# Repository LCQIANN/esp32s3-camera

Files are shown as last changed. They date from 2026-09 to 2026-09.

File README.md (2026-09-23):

# ESP32-S3 Camera — v1.4

以 ESP32-S3-WROOM-1-N16R8 為核心的隨身相機板：OV2640 DVP 相機、microSD 存檔、USB-C 燒錄與充電、鋰電池供電、電源開關與電源燈，1.3 吋 ST7789 預覽螢幕直接插在背面的母座上，快門在上板邊側按。v1.3 起為 3D 列印相機式外殼（鏡頭正面、螢幕背面）而改，v1.4 把快門移到上板邊。KiCad 10 專案，設計成直接送 JLCPCB PCBA。

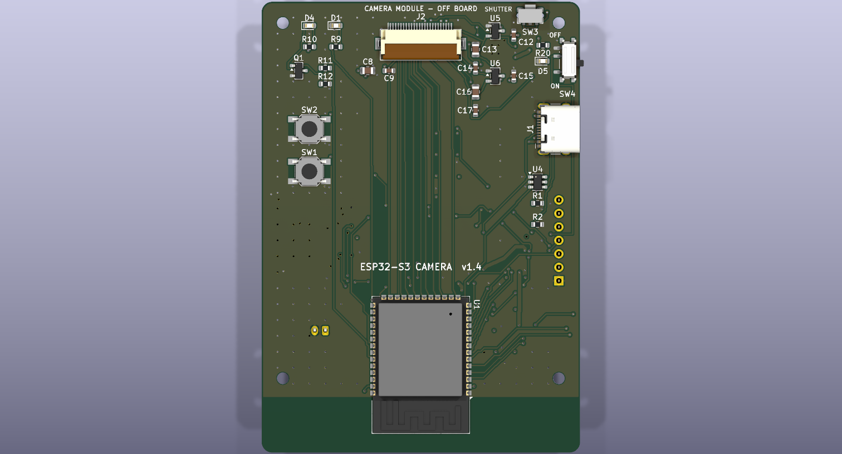
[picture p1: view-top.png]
頂面


| 項目 | 規格 |
|---|---|
| 板子 | 60 × 85 mm、4 層（In1 = GND、In2 = +3V3）、1.6 mm、四角 M2 孔 |
| 主控 | U1 ESP32-S3-WROOM-1-N16R8（16 MB flash、8 MB OPI PSRAM） |
| 相機 | J2 24P 0.5 mm FPC 座，AI-Thinker ESP32-CAM 標準腳位；U5 2.8V、U6 1.2V LDO 供相機 |
| 儲存 | J3 microSD（SDMMC），開口朝左板邊 |
| 電源 | J1 USB-C → U3 TP4056 充電 → J4 JST PH 2.0 鋰電池；U2 AP2112K 3.3V LDO；SW4 滑動開關控制 LDO EN；D5 藍色電源燈 |
| 操作 | SW3 SHUTTER 側按式（ALPS SKRTLAE010）在上板邊右段 (50.6, 2.6)；SW1 BOOT、SW2 RESET 頂面按壓式在左欄；D1 綠、D2 紅（充電）、D4 白 LED |
| 螢幕 | J5 1×7 2.54 mm 母座（底面右板邊），通用型 1.3 吋 IPS 240×240 ST7789 7 pin 模組，用七條公–母杜邦線接（2026-09-23 起；也可直插）；SCL=GPIO44、SDA=GPIO43、RES=GPIO6、DC=GPIO5、BLK=GPIO4。UART0 排針已取消 |
| 零件 | 60 顆：58 SMD 由 JLCPCB 貼片，2 插件（J4 電池座、J5 螢幕母座） |
| 狀態 | v1.4，2026-09-22 定稿。ERC 0、DRC 0/0/0、原理圖一致性 0、GND/3V3 連通性 0 孤立焊盤 |

## 目前狀態

- **v1.4 已定稿，可下單。** 快照在 `versions/v1.4/`，含 Gerber、BOM、CPL、ERC/DRC 報告，視為唯讀。v1.2、v1.3 都沒有下單。
- **預覽螢幕用七條公–母杜邦線接板上母座 J5**（2026-09-23 決定，省事不焊；腳序一對一）。模組鎖在後殼四支矮柱上、蓋在電池上方，亮面離板底約 26.4 mm；外殼後半因為杜邦膠殼加深到 27 mm 內深，整機 40.1 mm。細節與外殼用的尺寸在 `DESIGN.md` 2d 節與 `enclosure/README.md`。
- 版本沿革：v1.0 最初佈局 → v1.1 相機腳位改 ESP32-CAM 標準、加相機 LDO、填 LCSC 料號 → v1.2 加 SW4、R21、R20、D5 與 ON/OFF 絲印 → v1.3 J5/J6 兩條排針換成 1×7 螢幕母座 J5（SMD 與 CPL 不變）→ v1.4 快門 SW3 換成側按式移到上板邊右段，C12 下移 0.8 mm（CPL 只差這兩行）。
- 外殼相關但仍刻意沒改：LED 分兩面、板邊開口分三邊（USB-C 與開關右邊、記憶卡左邊、快門上邊）。
- 送洗前檢查補了兩顆 GND 過孔（J2.23、C3.2 原本焊盤浮接），細節見 `DESIGN.md` 第 3 節。

## 簡報

| 檔案 | 給誰看 | 內容 |
|---|---|---|
| `esp32s3-camera-v1.4-簡易版.pptx` / `.pdf` | 外行人、家人朋友、沒碰過電路板的人 | 11 頁，不用零件編號與專業縮寫：它能做什麼、正反面長什麼樣、工廠做哪些我們做哪些、要買什麼、三步組裝、三件注意事項、外殼長這樣、裝進殼裡長這樣 |
| `esp32s3-camera-v1.4.pptx` / `.pdf` | 自己下單與組裝時對照、有電子背景的人 | 21 頁完整版：依 PCB 座標畫的零件分工圖、Economic / Standard 差異、58 顆 SMD 清單、3D 渲染、組裝尺寸與高度、四頁 3D 列印外殼（含板外零件裝配檢查與杜邦線走線）、含購買連結的採購表；2026-09-23 已更新為杜邦線版 |

另有一個線上頁面「ESP32-S3 相機板零件分工圖」（claude.ai 私人連結，組織內可看），2026-09-23 已更新到 v1.4 杜邦線版：依座標畫的零件分工圖、組裝示意與裸板 3D 渲染、外殼與杜邦線走線渲染、採購清單。

兩份都用 PowerPoint 匯出成 PDF，PDF 內的購買連結可點。兩份簡報 2026-09-23 已更新到 v1.4（螢幕母座、側按快門、外殼）；更新方式是 `tools/update_decks_v14.py` 在 v1.2 檔上改文字、換圖、加頁，再用 `tools/export_decks.py` 叫 PowerPoint 匯出 PDF 與檢查用的 PNG。

## 檔案地圖

```
esp32s3-camera/
├── README.md                     本檔
├── DESIGN.md                     設計規格書：決策、腳位、電路細節、組裝與機構、版本規則
├── esp32s3-camera.kicad_pro/.kicad_sch/.kicad_pcb   KiCad 10 專案（根目錄永遠是最新版）
├── esp32s3-camera.pretty/        自訂 footprint（ESP32-S3-WROOM-1-Cam）
├── esp32s3-camera.step           板子 STEP，給外殼設計用
├── erc.rpt / drc.rpt / netlist.net
├── view-top.png / view-bottom.png   v1.4 頂面、底面 3D 正視
├── esp32s3-camera-v1.4.pptx / .pdf   零件分工、組裝示意、渲染圖、外殼、採購清單簡報（完整版 20 頁）
├── esp32s3-camera-v1.4-簡易版.pptx / .pdf   給外行人看的 11 頁簡易版
├── tools/                        簡報更新與匯出腳本（python-pptx + PowerPoint COM）
│
├── fab/                          送廠檔案
│   ├── esp32s3-camera-gerber.zip   Gerber + 鑽孔打包
│   ├── esp32s3-camera-bom.csv      BOM，含 LCSC Part # 欄
│   ├── esp32s3-camera-cpl.csv      貼片座標
│   ├── gerber/                     未打包的 Gerber、鑽孔檔
│   ├── JLCPCB-上傳-v1.4/            上傳用三個檔案的重新命名版 + 一頁說明
│   ├── JLCPCB-下單清單.md           下單逐步核對表，含收到板子後的第一次上電
│   └── 採購清單.md                  板外零件與插件的購買網址
│
├── render/                       kicad-cli 光線追蹤渲染
│   ├── iso-*/top/bottom/low-angle/closeup-*.png   裸板貼片後
│   ├── assembled-*.png / closeup-camera-module.png   插相機、記憶卡、電池、螢幕的組裝示意
│   └── illustration/             示意渲染專用的板檔複本、簡化 VRML 模型、輔助腳本（見下）
│
├── versions/                     各版完整快照，唯讀
│   ├── v1.0/  v1.1/  v1.2/  v1.3/  v1.4/   每版有 README.txt 說明改了什麼
│
├── enclosure/                    3D 列印外殼：SolidWorks 前殼、後殼、按鈕帽、組合件、STL、渲染圖與產生腳本（見 enclosure/README.md）
├── frames/                       2026-09-11 早期佈局的旋轉截圖，僅供回顧
└── .history/                     KiCad 自動快照，由 KiCad 管理
```

`render/illustration/esp32s3-camera-illustration.kicad_pcb` 多了三個沒有焊盤的假零件掛簡化模型，**只用來渲染，不要拿它出 Gerber**。

## 怎麼下單

1. 依 `fab/JLCPCB-下單清單.md` 逐項核對。上傳 `fab/esp32s3-camera-gerber.zip`、`esp32s3-camera-bom.csv`、`esp32s3-camera-cpl.csv`。
2. PCB：4 層、60 × 85 mm、1.6 mm、1 oz、ENIG 建議、Tented via，最少 5 片。
3. PCBA：雙面貼片，最少 2 片。
   - **Economic** 只焊 SMD：J4 電池座、J5 1×7 母座（C225482）自己買回來手焊。
   - **Standard** 含插件：兩顆一起焊好。
4. 料號配對頁逐行看：U1 `C2913202`（N16R8，可能預購，不要被換成 N8 或無 R 版）、D3 `C8598`（SOD-123，不是 SS14）、SW4 `C431540`、SW3 `C110293`（ALPS SKRTLAE010 側按，不要被換成頂按式）。
5. 零件擺放預覽確認方向：U1 天線端朝板子底邊、J1 開口朝板邊、J2 掀蓋朝板邊、SW4 撥桿朝右板邊、**SW3 觸桿朝上板邊**、J5 母座在底面、方形 pin 1 焊盤朝天線那一端。

## 板外要自己買的

相機模組、鋰電池、microSD 卡、USB-C 線是最小採購；Economic 方案再加 J4 電池座。完整清單與購買網址在 `fab/採購清單.md`。

| 品項 | 規格 | 接到 |
|---|---|---|
| OV2640 相機模組 | 24 pin 0.5 mm 排線，ESP32-CAM 相容，排線約 21 mm，多買一條備用 | J2 |
| 3.7V 鋰電池 | 603040 或 503040 約 600 mAh，帶保護板，JST PH 2.0 插頭 | J4 |
| microSD 卡 | 8–32 GB | J3 |
| USB-C 線 | 要能傳資料 | J1 |
| 預覽螢幕 | 通用型 1.3 吋 IPS 240×240 ST7789，7 pin 2.54 mm 直排針已焊，27.78 × 39.22 mm | 七條公–母杜邦線接 J5 |
| 杜邦線 | 公–母、10 cm、7 條 | 公頭插 J5、母頭套螢幕排針 |
| M2 螺絲與銅柱 | 板子 4 組 | H1–H4 |
| 雙面泡棉膠 | 約 2 mm 厚 | 相機模組與電池底下 |

## 組裝重點

- **相機**：排線接觸面朝下插入 J2，出來約 2.5 mm 就反折 180° 蓋回 J2，模組貼在按鍵欄與 U4 之間的空區（x 25.5–34.5、y 20.5–29.5 mm），鏡頭中心 (30, 25)，底下墊 8 × 8 mm 泡棉膠。
- **電池**：貼在底面中央 (34, 44)，墊 2 mm 泡棉，保護板端朝下緣。**J4 pin 1 = 正極**，在 L 形絲印那一側、靠板子中央。電池插頭極性沒有統一規範，插之前先量。
- **螢幕**：模組排針對準底面右板邊的 J5 母座直接插到底，亮面朝外、身體蓋在電池上方。腳序一對一：GND、3V3、SCL (GPIO44)、SDA (GPIO43)、RES (GPIO6)、DC (GPIO5)、BLK (GPIO4)，板上每格都有絲印，**第一次插之前先對一下模組上的 GND 字有沒有對到板上 GND 那格**。借用 UART0 腳位當 SPI，USB 序列埠仍可用。
- **快門**：SW3 在上板邊右段，觸桿朝板邊伸出 0.56 mm 內，由外殼上牆的快門帽按壓；不裝外殼時用指甲從板邊按。BOOT、RESET 仍在鏡頭面左欄。
- **電源開關**：撥向板子上緣（角落孔那側）= OFF，撥向模組 = ON，絲印已標。關機時 USB 仍可充電，D2 紅燈照常。D5 藍燈接 3.3V，開機必亮。
- **microSD**：從左板邊插入 J3，金手指朝電路板，推到「喀」一聲。
- **底面高度**：電池 + 泡棉 8 mm；J5 上的杜邦公頭膠殼到板底下 22.5 mm；螢幕模組背面離板底 23.6 mm、亮面 26.4 mm，外殼底側內深 27.0 mm。
- **外殼開孔**：鏡頭 (30, 25) 頂面；快門上板邊 x 47.6–53.6、板頂以上 0.2–4.4 mm；BOOT/RESET 針孔 (9, 24)、(9, 32)；開關右板邊 y 8–14；USB-C 右板邊 y 19.5–28.5；記憶卡左板邊 y 36–52；螢幕窗 23.4 × 23.4 mm，中心約 (28.4, 45) 底面。板子 STEP 在 `esp32s3-camera.step`，含母座；螢幕模組的簡化模型在 `render/illustration/models/display_module.wrl`。

## 外殼

`enclosure/` 是給 v1.4 板子的相機式兩片殼（前殼鏡頭面、後殼螢幕面，快門帽在上牆），用 `enclosure/build_enclosure_sw.py` 透過 SolidWorks 2024 的 API 依板檔座標自動建模，組合件含板子 STEP 與板外零件簡化模型，干涉檢查 0 件。螢幕模組用四支 M2×4 鎖在後殼的矮柱上、以七條杜邦線接 J5，快門帽在上牆。外形 65 × 90 × 40.1 mm，四支 M2×35 從背面鎖。組合件連相機模組、排線反折、電池與電池線、記憶卡、螢幕模組、杜邦線的簡化模型都放進去做過干涉檢查，0 件。尺寸依據、列印方向、組裝步驗與第一次實體要驗證的項目都在 `enclosure/README.md`。

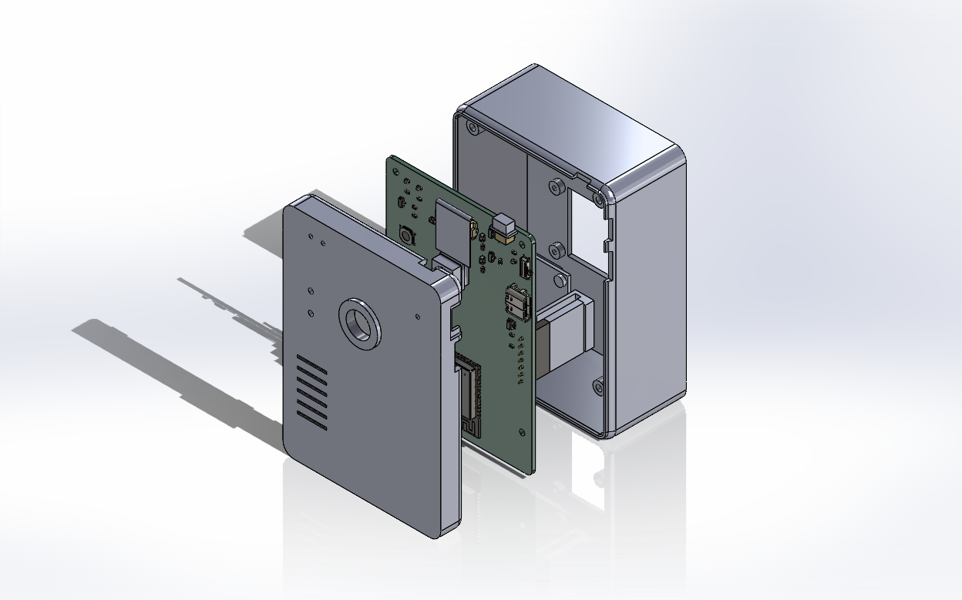
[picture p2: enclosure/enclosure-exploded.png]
外殼爆炸圖


## 收到板子後的第一次上電

先不插相機與電池。接 USB-C 撥 SW4 看 D5 亮滅，量 +3V3 / +2V8 / +1V2 對地無短路且電壓正確，電腦看到 ESP32-S3 USB 裝置，燒 blink 測 D1。都過了再依序插 microSD、相機排線、最後接電池。完整清單在 `fab/JLCPCB-下單清單.md` 第 8 節。

## 韌體

Arduino IDE `esp32` 套件的 CameraWebServer 範例，或 ESP-IDF 的 `esp32-camera` component。Board 選 **ESP32S3 Dev Module**，PSRAM 選 **OPI PSRAM**（R8 是 octal，選 QSPI 會抓不到）。相機 GPIO 對應表在 `DESIGN.md` 第 4 節，直接填進 `camera_config_t`。

## 版本規則

- 根目錄永遠是正在改的最新版。每次出 Gerber 準備下單，把 `.kicad_pcb / .kicad_sch / .kicad_pro`、`esp32s3-camera.pretty/`、`fp-lib-table` 與 `fab/` 內的 zip、BOM、CPL 複製到 `versions/vX.Y/`，並寫 README.txt。
- 版本號用數字（v1.0、v1.1、v1.2），不用 rev A / rev B。板上絲印、KiCad 標題欄、Gerber ProjectId 三處同步。
- 不在根目錄留 `*.bak_before_xxx`，中途快照交給 KiCad 的 `.history/`。
- 2026-09-21 起以 Git 管理，遠端為公開的 GitHub LCQIANN/esp32s3-camera；`versions/` 的快照仍照上面規則保留。

## 重新輸出送廠檔

```
kicad-cli sch export bom --fields "Reference,Value,Footprint,QUANTITY,LCSC" --labels "Designator,Comment,Footprint,Qty,LCSC Part #" --group-by "Value,Footprint,LCSC" --exclude-dnp -o fab/esp32s3-camera-bom.csv esp32s3-camera.kicad_sch
kicad-cli pcb drc --schematic-parity esp32s3-camera.kicad_pcb
```

## 輔助腳本（`render/illustration/`，用 KiCad 附的 python 執行）

| 腳本 | 用途 |
|---|---|
| `gnd_connectivity.py` | 幾何連通性檢查：焊盤、過孔、走線、敷銅做 union-find，確認每個 GND / +3V3 焊盤都在主群集。**DRC 只要有 unconnected_items 就跑一次，0 才算過。** |
| `battery_check.py` | 電池投影範圍對底面零件外框與高度的間距核對 |
| `fix_v12_gnd.py` | 2026-09-21 補 J2.23、C3.2 GND 過孔與 R21 腳位修正 |
| `v12_sch.py` / `v12_pcb.py` / `v12_silk_onoff.py` | v1.2 加 SW4、R20、R21、D5 與 ON/OFF 絲印的自動改板腳本 |
| `make_illustration_board.py` | 產生示意渲染用的板檔複本 |
| `gen_camera_wrl.py` / `gen_display_wrl.py` | 產生相機模組與螢幕的簡化 VRML 模型（KiCad 不畫 Cylinder 基本體，圓柱要用網格） |
| `sch_inspect.py` | 原理圖檢查工具 |

## 教訓

- DRC 報的「zone unconnected」不要當敷銅碎片忽略。KiCad 只回報兩群集間最近的一對物件，浮接的焊盤會藏在後面。
- D3 要用 B5819W SOD-123（`C8598`），LCSC 上的 SS14 是 SMA 封裝，焊盤不合。
- JLCPCB 的零件旋轉定義與 KiCad 不一定一致，零件擺放預覽頁逐一看有極性的零件。

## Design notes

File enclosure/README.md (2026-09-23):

# ESP32-S3 Camera v1.4 — 3D 列印外殼（SolidWorks 2024）

相機式兩片殼：**前殼**（鏡頭與凸起鏡座環、上牆的快門帽、BOOT/RESET 針孔、三個 LED 導光孔、左側握持溝紋、USB-C 與電源開關的開口）＋**後殼**（內縮邊框的螢幕窗、記憶卡插槽、四支板子立柱、四支螢幕螺絲柱），外緣整圈 R2.5 倒圓、直角 R4.5，用四支 M2×35 螺絲從背面鎖穿。整組 **65 × 90 × 40.1 mm**（鏡座環再凸 1.5），壁厚 2 mm。
螢幕模組**用七條公–母杜邦線接 J5**（2026-09-23 決定，省事不焊）：公頭插板上母座、母頭套模組排針；後殼因此加深到 27 mm 內深，模組改用四支 M2×4 鎖在後殼柱子上。
所有零件都是 `build_enclosure_sw.py` 透過 SolidWorks COM API 依 v1.4 板檔的座標畫出來的，改尺寸就改腳本開頭的參數重跑。v1.3 版外殼（三顆正面按鈕帽）已被取代。

爆炸圖

## 檔案

| 檔案 | 內容 |
|---|---|
| `esp32s3-camera-enclosure.SLDASM` | 組合件：板子 + 前殼 + 後殼 + 快門帽，全部固定在板子座標系，已跑干涉檢查 0 件 |
| `esp32s3-camera-shell-front.SLDPRT` / `.STL` | 前殼（鏡頭面） |
| `esp32s3-camera-shell-back.SLDPRT` / `.STL` | 後殼（螢幕面） |
| `esp32s3-camera-shutter-cap.SLDPRT` / `.STL` | 快門帽，印 1 個（T 形，凸緣在牆內） |
| `esp32s3-camera-board.SLDPRT` | 由 `../esp32s3-camera.step` 匯入的板子（148 個實體合成一個多實體零件），只給組合件用 |
| `enclosure-*.png` | 各方向渲染與爆炸圖 |
| `build_enclosure_sw.py` | 產生器。SolidWorks 開著時執行 `python enclosure/build_enclosure_sw.py`；只重建組合件加 `--asm-only` |

## 座標系

組合件用板子座標：X = KiCad x，Y = −KiCad y，Z = 0 在板子**頂面**（鏡頭那一面），板底 Z = −1.6。
前殼佔 Z 0 ～ +9，後殼佔 Z −31.1 ～ 0，分模線就在板子頂面。KiCad 的 STEP 是 Y 上下顛倒的右手座標，所以直接對得上，只平移 Z。

## 尺寸怎麼來的

| 項目 | 數字 | 依據 |
|---|---|---|
| 內腔 | 61 × 86 mm | 板子 60 × 85 + 每邊 0.5 mm 間隙 |
| 前殼內高 | 8 mm（板頂以上） | 相機模組：泡棉 2.3 + PCB 1 + 鏡座 3.5 = 鏡座頂 6.9，留 1.1 mm；鏡筒與壓環到 9.0 穿出 Ø10 孔，鏡片在鏡座環裡內縮 2.5 mm；USB-C 座 3.3、ESP32 模組 3.1 |
| 後殼內深 | 27.0 mm（板底以下） | 插在 J5 上的杜邦公頭：母座 8.5 + 膠殼 14.0 = 22.5，線從膠殼尾端彎出來再要 3.5，留 1.0；螢幕模組就吊在這個深度：背面離板底 23.6、玻璃面 26.4，離底板內面 0.6 給窗框泡棉；電池 6 + 泡棉 2 = 8 |
| 板厚 / 壁厚 / 底板 | 1.6 / 2.0 / 前 2.0、後 2.5 | 後底板 2.5 是為了放 1.5 mm 深的螺絲頭沉孔 |
| 直角圓角 | R4.5 外、R3.5 中、R2.5 內 | 三層同心；板子四角有 2 mm 斜切，Ø5 立柱仍在內腔圓弧內 |
| 面的倒圓 | 鏡頭面與螢幕面的外緣整圈 R2.5 | 板 2 mm 加牆 2 mm，45° 處最薄 1.8 mm |
| 鏡座環 | Ø16 / Ø10、凸出 1.5 mm | 鏡頭孔外一圈凸環，相機味，也擋住鏡頭孔邊緣的層紋 |
| 握持溝紋 | 鏡頭面左側 x 3.5–15.5，六道 1 mm 寬 0.6 mm 深，y 50–70 每 4 mm 一道 | 針孔下方的空區；內側是前殼柱子，不影響 |
| 螢幕邊框 | 螢幕窗外 28.5 × 28.5 內縮 0.8 mm | 讓窗看起來是一片面板，不是牆上開個洞 |
| 立柱（後殼） | Ø5 × 14.5，Ø2.4 穿孔，底面 Ø4.2 × 1.5 沉孔 | 在板子四角 M2 孔 (4,4)(56,4)(4,71)(56,71) |
| 柱（前殼） | Ø4.6 × 8，Ø1.6 × 7 導孔 | M2 自攻，M2×35 進去 5.4 mm；Ø4.6 是因為 (56,4) 那支離 SW4 只有 0.2 mm |
| 唇口 | 後殼內側 0.8 mm 厚、高 1 mm，前殼對應凹槽 1.0 mm，每側 0.1 mm 間隙 | 對位用，也擋光 |
| 鏡頭孔 | Ø10 @ (30, 25) | 相機模組鏡頭中心 |
| 快門窗 | 上牆（y = 0 那一側）x 47.6–53.6、板頂以上 Z 0.2–4.4；後殼唇口同位置開缺口 | SW3 ALPS SKRTLAE010 側按，觸桿頭在 y = 0.56、Z 1.75，開關高 3.5 |
| 快門帽 | 凸緣 7.6 × 4.0 × 0.8 在牆內，頭 5.6 × 3.6 穿牆、露出 1.0 mm，總長 4.06 | 觸桿頭到牆內面 1.06 mm：凸緣 0.8 + 預行程 0.26；開關行程 0.25 |
| BOOT / RESET 針孔 | Ø2.0 @ (9, 24) RESET、(9, 32) BOOT，穿過 2 mm 頂板 | 用 SIM 卡針或牙籤從 7 mm 外按 1.5 mm 高的開關 |
| LED 導光孔 | Ø1.5 @ (14,4.5) D1 綠、(9,4.5) D4 白、(53,11.2) D5 藍；後殼 Ø2 @ (53,14) D2 紅 | 頂面直接透光；D2 隔 14.5 mm，只看得到微光 |
| USB-C 窗 | 右側牆，y 18.75–29.25、Z 0–4.2 | 座子 8.94 寬 × 3.26 高，加間隙；後殼唇口對應開缺口到 Z −1 |
| 電源開關槽 | 右側牆，y 7–15、Z 0–4.5；外側再挖 1 mm 深、12 × 6 的指窪 | 撥桿只伸出板邊 0.7 mm，牆薄到 1 mm 才撥得到 |
| 記憶卡槽 | 左側牆，y 37.5–50.5、Z −4.8 ～ −2.0 | 卡插到底仍露出板邊 4.6 mm，會露出殼外 2.1 mm 好拔 |
| 螢幕窗 | 24.5 × 24.5 @ (28.4, 45) | 有效顯示區 23.4 × 23.4（模組中心 x 30，顯示區偏向排針那一側 1.6）；模組玻璃 25.8 × 29.22，窗框壓在玻璃邊緣上，內側貼一圈 0.5 mm 泡棉膠填掉 0.6 mm 空隙 |
| 螢幕螺絲柱 | 後殼底板長四支 Ø4.5、2.2 mm 高的柱到模組 PCB 朝底板那一面（離板頂 26.4 mm），Ø1.6 × 4 導孔，M2×4 穿過模組四角 Ø2 孔鎖進去 @ (12.9, 33.6)、(47.1, 33.6)、(12.9, 56.4)、(47.1, 56.4) | 模組不插母座，只靠這四支螺絲；模組中心 x = 30、排針那排朝左（x 12.9），離 J5 遠一點才有地方繞線。孔位照 lcdwiki 的 GMT130 圖面，買到孔位不同的相容品要改 `DISPLAY_MODULE` |
| 杜邦線 | 7 條公–母，J5 上的公頭膠殼 2.54 × 14 站在母座上（板底下 8.5–22.5），模組排針上的母頭膠殼從模組背面朝板子伸 16.5（含排針塑膠 2.54），頂端離板底 7.1；線先在母頭上方 S 彎、走電池底下 0.7 mm 的空隙到模組右邊 x 51，沿模組邊下到離底板內面 1 mm，再從下面繞進公頭 | 買 10 cm 的一排 40P 剪 7 條；多出來的長度盤在模組右邊 x 50–54 到底板之間。膠殼尺寸不同就改 `DUPONT`，線走法在 `build_display_cable()` |

## 列印與組裝

- **列印方向：兩片殼都開口朝下、外面朝上。** 外緣有 R2.5 倒圓之後，外面朝下印會讓第一層只剩內縮 2.5 mm 的平面，圓角從幾乎水平開始一層層外擴，表面會很糙；翻過來讓圓角像圓頂一樣往上收就沒有懸空。鏡座環、握持溝紋、螢幕邊框都在最上面那一面，也正好印得最乾淨。
- 翻過來印的代價是殼內的柱子變成從天花板往下長、離床有空隙，要開支撐：前殼四支柱離床 2 mm（內高 8 對板頂，柱長 8），後殼四支立柱離床 1.6 mm、四支螢幕螺絲柱只有 2.2 mm 高、離床 26.4 mm。切片時選「只在列印床上生成支撐」加樹狀支撐，支撐只會長在這幾支柱子下面，拆掉即可；柱子底面（貼板子那一面）拆完稍微修平。後殼的唇口比外牆高 1 mm，開口朝下時唇口先著床、外牆邊 1 mm 懸空，同一組支撐設定會自動補一圈薄底，或改用 raft。
- 上牆快門窗、右側牆 USB-C 窗與開關槽、左側牆記憶卡槽都在垂直牆上，2–6 mm 跨距自然橋接，不用支撐。**快門帽**：凸緣朝下、頭朝上，不用支撐。
- 材料 PLA/PETG 皆可；預估 PLA 用量前殼約 20 g、後殼約 40 g（牆高 31 mm），支撐另加幾克。層高 0.2 mm、壁 3 圈；想要圓角更順可用 0.12 mm 層高只印外殼那兩件。
- 螺絲：**M2 × 35 mm 盤頭** ×4，從後殼底部沉孔穿過立柱與板子，自攻進前殼的 Ø1.6 × 7 導孔（進去 5.4 mm）。先用 M2 螺絲在前殼導孔上預攻一次再組。另外 **M2 × 4 mm 盤頭** ×4 把螢幕模組鎖在後殼的四支矮柱上。
- 組裝順序：① 螢幕窗框內側貼 0.5 mm 泡棉膠 ② 螢幕模組亮面朝窗、排針那排朝左（記憶卡那一側），四角用 M2×4 鎖在後殼的矮柱上 ③ 七條杜邦線母頭套上模組排針，公頭照板上絲印插進 J5（GND 對 GND，先核對模組絲印），多出來的線盤在模組右邊 ④ 板子放進後殼，四角落在立柱上，線不要壓在電池與模組之間以外的地方 ⑤ 快門帽從前殼內側塞進上牆的窗，凸緣留在牆內 ⑥ 前殼蓋上，唇口對進凹槽 ⑦ 翻面鎖四支 M2×35。相機模組與電池用泡棉膠照 `../README.md` 貼好再蓋。
- 板子與殼壁間隙 0.5 mm，FDM 列印若內縫收縮，用刀修一下唇口即可。

## 板外零件的裝配檢查

組合件除了板子 STEP，還放了五個依文件尺寸畫的簡化零件：`offboard-camera-module`（相機模組含泡棉、鏡座、鏡筒）、`offboard-ribbon`（24P 排線：0.3 mm 厚、14 mm 寬，在 y 4.0 以 0.7 mm 半徑反折，最外緣 y 3.15，回程貼板高 2.4 mm 到模組邊 y 20.5）、`offboard-battery-card`（603040 電池、電池線、J4 下方的插頭出線、露出板邊的記憶卡）、`offboard-display-module`（螢幕模組 PCB 含四角孔、背光框、玻璃、模組背面的排針塑膠、四顆 M2 螺絲頭）、`offboard-display-cable`（七條杜邦線：J5 上的公頭膠殼、模組排針上的母頭膠殼、線束以 7 條並排 1.4 mm 厚的扁塊表示）。干涉檢查含這些零件為 0 件。刻意沒放進去的：電池底下的泡棉（會包住 1.3 mm 高的零件，放進去是假警報）、插在 J4 裡的插頭本體、插在 J3 裡的卡身、排針針腳與杜邦公頭的針（在膠殼或母座裡）、杜邦線多出來的長度。這些零件只是給外殼檢查用，尺寸與實品不同就改 `build_offboard_*()`。

`fit_shots.py` 會把殼隱藏或調半透明拍幾張裝配檢查圖（`fit-*.png`）：

| | |
|---|---|
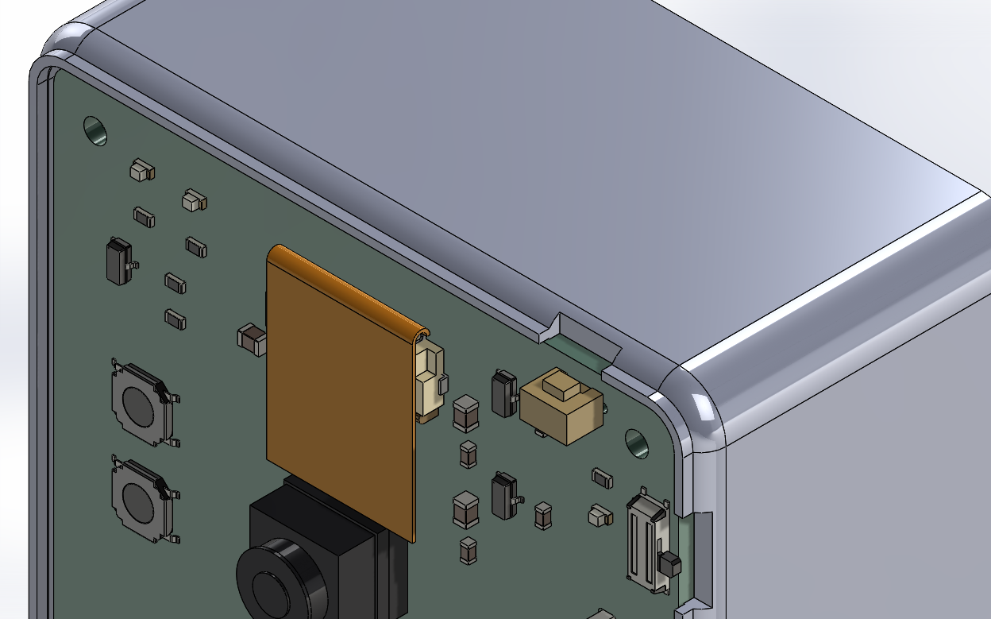
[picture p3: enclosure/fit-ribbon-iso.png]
排線特寫
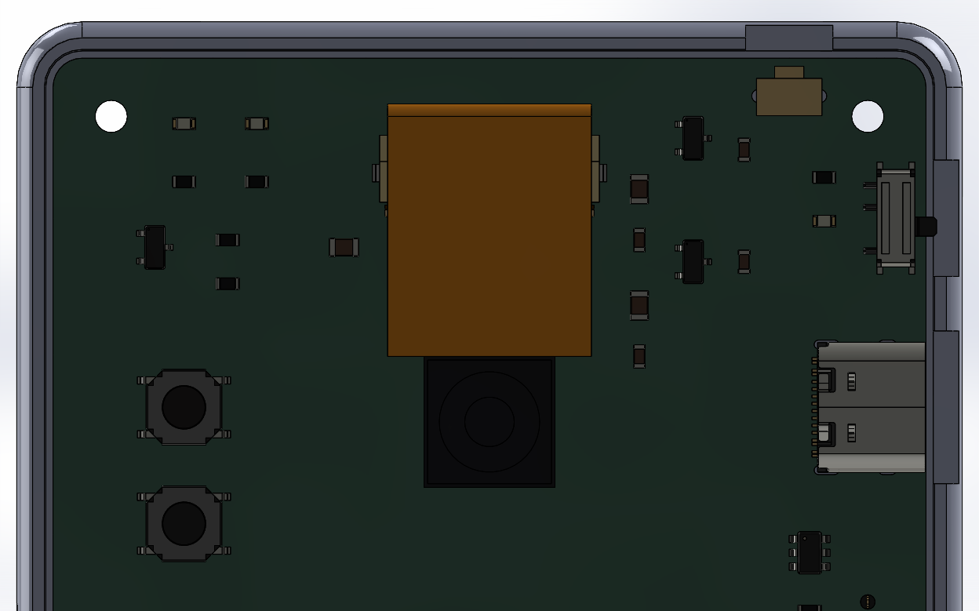
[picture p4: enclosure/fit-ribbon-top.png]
排線正上方
|  排線（橘）從 J2 出來反折 180° 貼回板面接到相機模組；反折處離上牆內面 3.8 mm |  正上方看：排線蓋過 J2，模組落在按鍵欄與 U4 之間，鏡頭中心 (30, 25) |
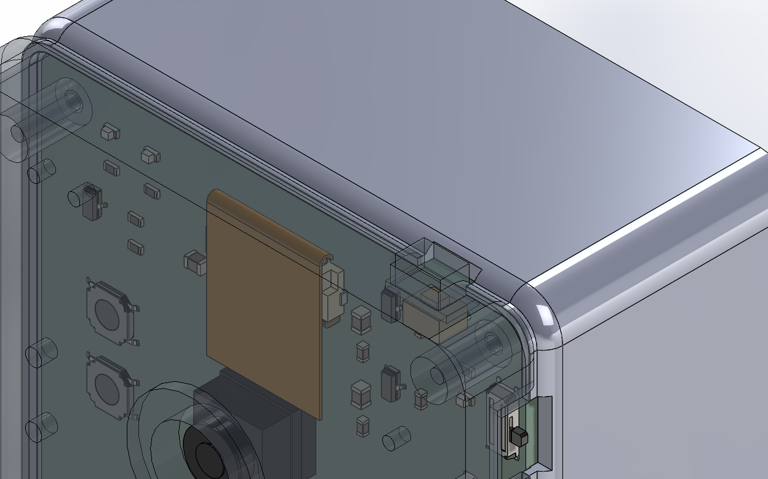
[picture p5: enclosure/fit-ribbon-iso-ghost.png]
排線半透明
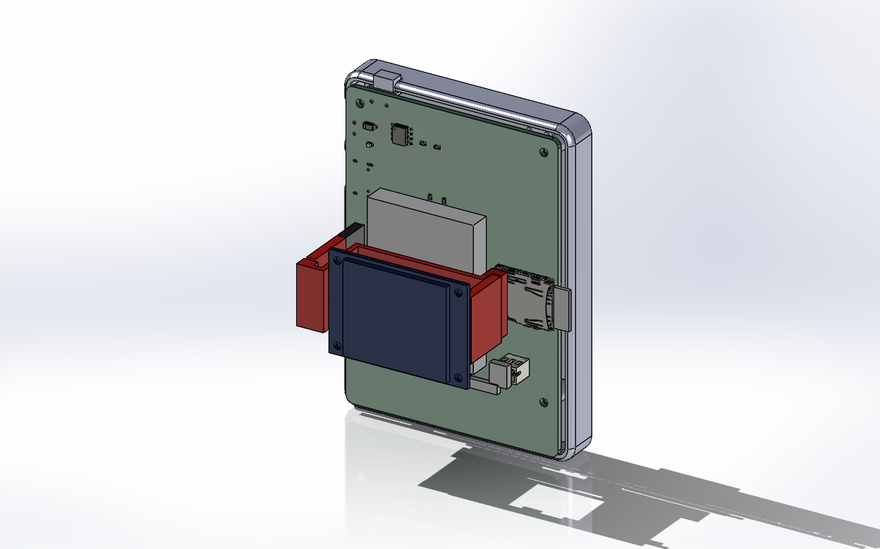
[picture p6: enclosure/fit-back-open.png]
後殼拿掉
|  前殼半透明：排線、鏡座與天花板、快門帽與上牆窗的關係 |  後殼拿掉：螢幕模組（藍）吊在杜邦線（紅）之下、電池與電池線、J4 插頭、露出的記憶卡 |
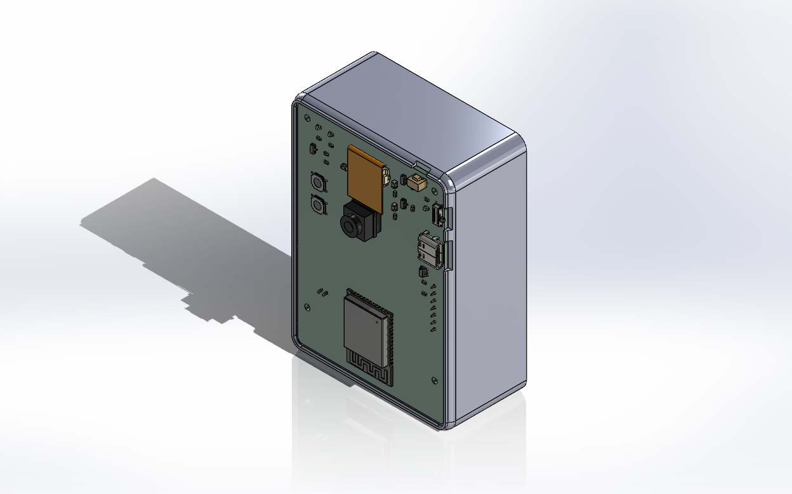
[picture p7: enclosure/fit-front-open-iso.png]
前殼拿掉
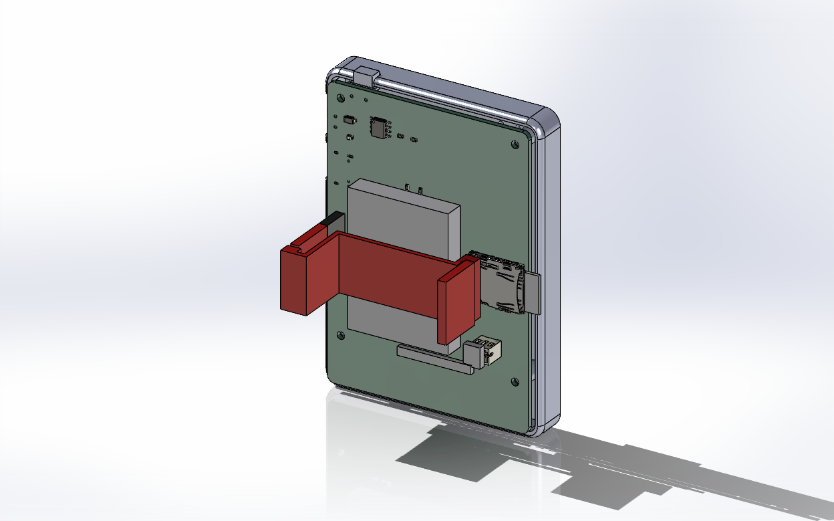
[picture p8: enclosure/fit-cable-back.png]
杜邦線
|  前殼拿掉全景 |  後殼與螢幕模組都拿掉：七條杜邦線從左邊的母頭 S 彎後走電池底下，到右邊下去繞進 J5 上的公頭 |
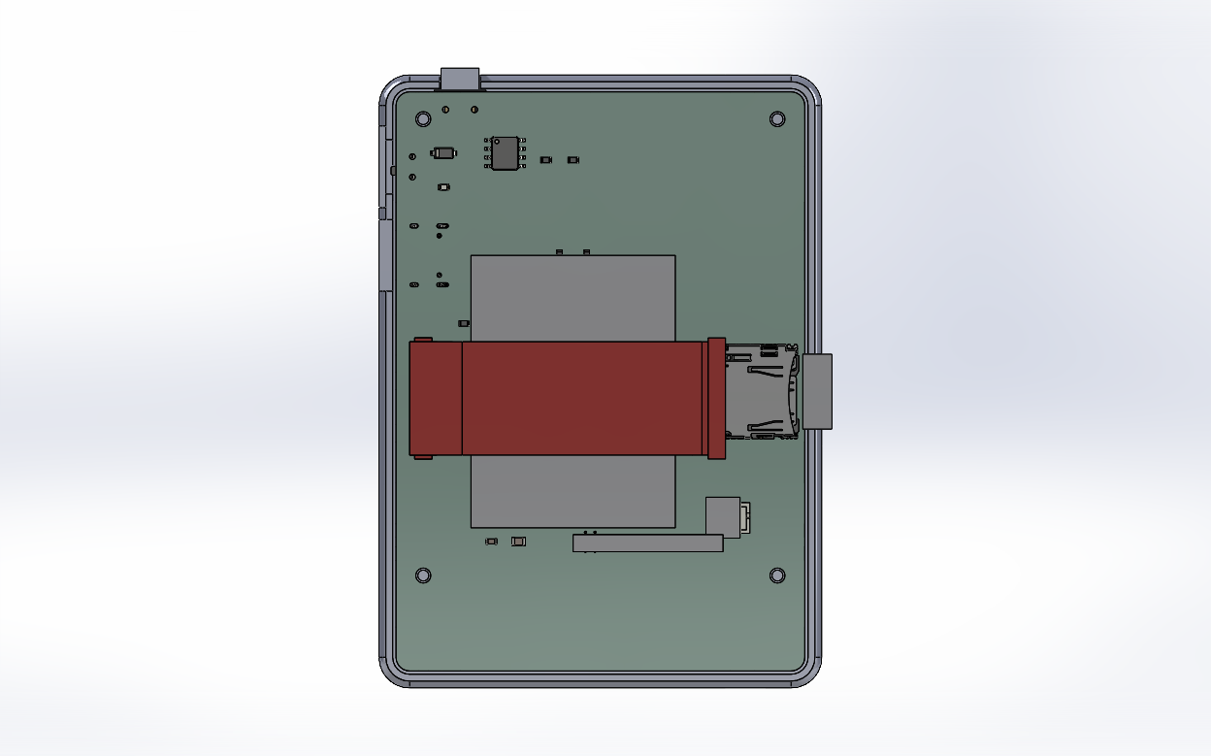
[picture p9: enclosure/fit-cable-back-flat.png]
杜邦線正視
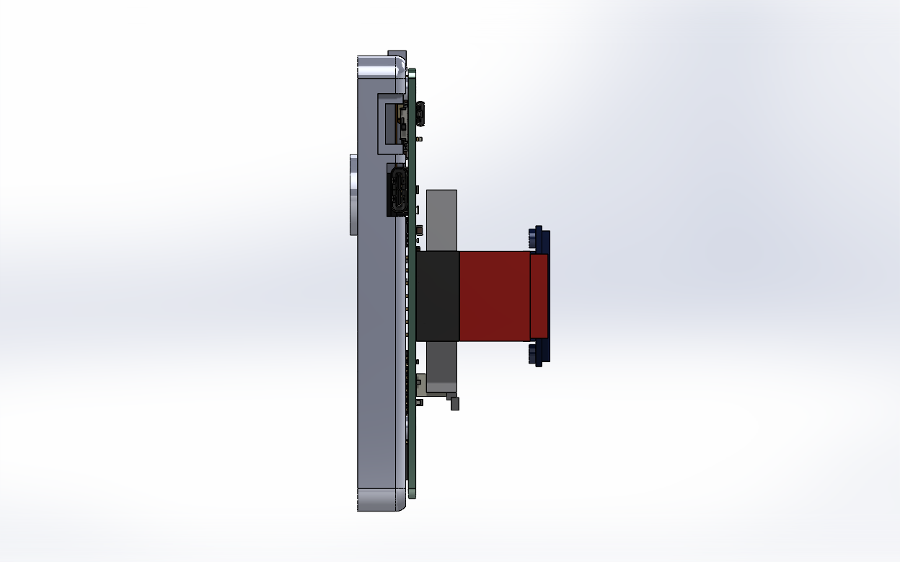
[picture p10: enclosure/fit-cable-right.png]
杜邦線側視
|  同上，底面正視 |  右側視：公頭膠殼站在 J5 母座上到板底下 22.5，線在下面彎進去；模組玻璃面在 26.4 |
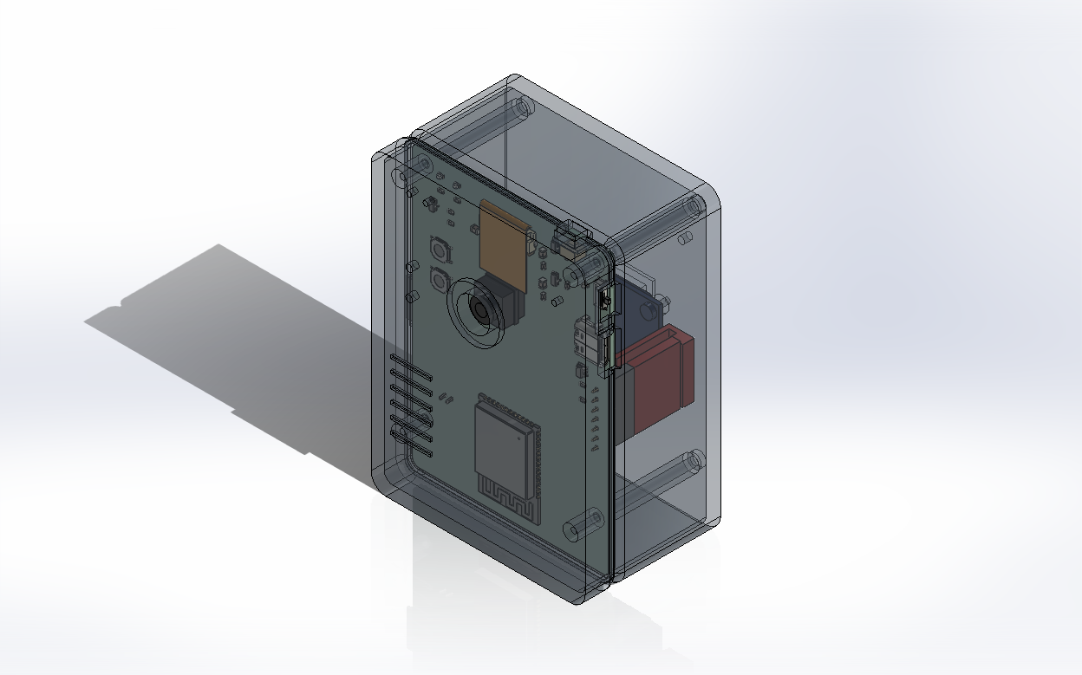
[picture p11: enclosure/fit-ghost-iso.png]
半透明
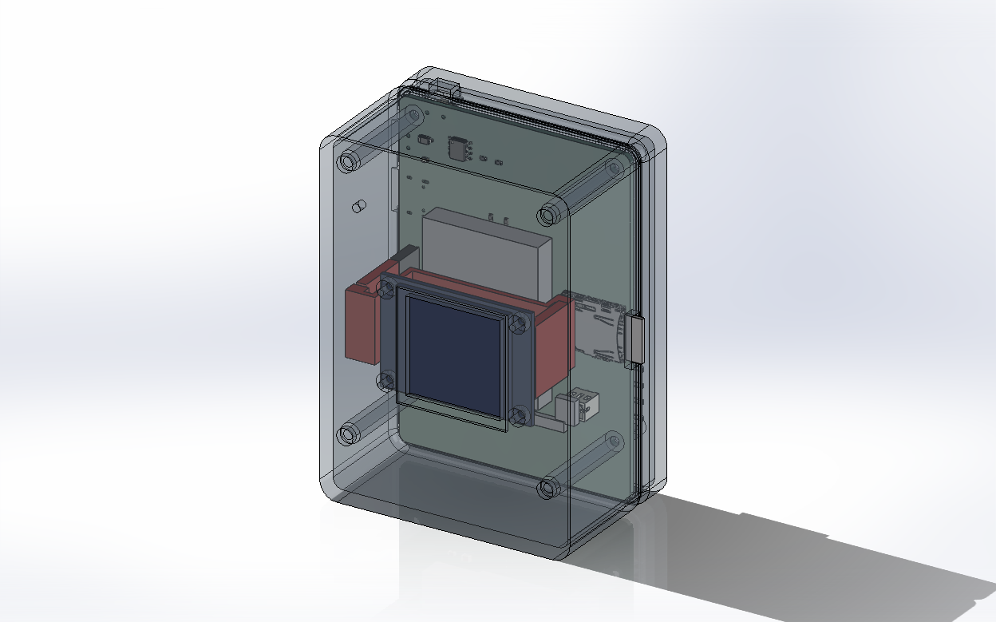
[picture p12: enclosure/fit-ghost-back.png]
半透明背面
|  兩片殼半透明，鏡頭面 |  兩片殼半透明，螢幕面：四支矮柱頂住螢幕四角 |

## 第一次實體驗證要看的

1. 相機模組含鏡頭實際高度：內高 8 mm 是照 6.9 mm 的鏡座頂加 1.1 mm 餘裕定的，鏡頭筒要能穿出 Ø10 孔且鏡座不被壓到；不合就改 `FRONT_CAV`。
2. 杜邦線：公頭插進 J5 後膠殼尾端離底板內面應有 4.5 mm（3.5 給線彎、1 餘裕），線塞不進去就把 `DUPONT["loop"]` 加大；母頭套上模組排針後頂端離板底約 7 mm，上方不能有零件；10 cm 的線多出來的部分要盤得進模組右邊的空間。
3. 螢幕模組鎖上後玻璃面離板底的實測值（設計值 26.4 mm）與四角孔是否對到矮柱；差太多就改 `DISPLAY_MODULE["back_zb"]`。
4. 電源開關撥桿能否從指窪撥動；不行就把 `SW4["pocket_depth"]` 加到 1.5。
5. 快門手感：預行程 0.26 mm 太多就把 `SHUTTER["flange_t"]` 加到 1.0；快門帽在窗裡卡住就把 `head_w`/`head_h` 各減 0.2。
6. 針孔按 BOOT/RESET 順不順手：不順就把 `PINHOLE_D` 放大到 2.5。

## 這版刻意沒做

LED 分兩面、開口分三邊（右邊 USB-C 與開關、左邊記憶卡、上邊快門），這些是板子 v1.4 定案時決定不改的；外殼跟著板子。沒有腕帶孔、腳架螺孔與品牌文字，要加請在 SolidWorks 裡直接改零件，或在腳本加特徵後重跑（腳本會覆寫同名檔案）。

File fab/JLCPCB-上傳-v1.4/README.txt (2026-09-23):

JLCPCB 上傳檔案 — ESP32-S3 Camera v1.4（2026-09-22 輸出）

1. esp32s3-camera-v1.4-gerber.zip  → Order Now → Add Gerber File（4 層、60 x 85 mm、1.6 mm、1 oz、ENIG 建議、Tented via）
2. esp32s3-camera-v1.4-bom.csv     → PCB Assembly → BOM（Designator / Comment / Footprint / Qty / LCSC Part #）
3. esp32s3-camera-v1.4-cpl.csv     → PCB Assembly → CPL（Ref / Val / Package / PosX / PosY / Rot / Side）

Assembly Side 選 Both sides，PCBA 數量最少 2。v1.4 相對 v1.3：快門 SW3 換成側按式 ALPS SKRTLAE010（C110293）放在上板邊右段，C12 下移 0.8 mm；插件仍是 J4、J5。
完整步驟見 ../JLCPCB-下單清單.md。

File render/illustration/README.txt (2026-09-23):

僅供 3D 示意渲染用的板檔複本。多了 ILL1–ILL4 四個沒有焊盤的假零件，
掛著 models/ 內簡化的相機模組、microSD 卡、鋰電池、1.3 吋螢幕模組 VRML 模型（v1.3 起螢幕插在 J5 母座上）。
不要拿這個檔案出 Gerber；真正的板檔是上層的 esp32s3-camera.kicad_pcb。
models/ 內另有 SW_Push_SKRTLAE010_Side.step（v1.4 側按快門的簡化模型，與根目錄 models/ 相同），因為板檔複本的 ${KIPRJMOD} 指到這個資料夾。

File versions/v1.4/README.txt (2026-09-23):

v1.4 — 2026-09-22 定稿（v1.3 未下單，直接改成 v1.4）。
起因：三顆按鍵都在鏡頭面左欄，拿相機時要繞到前面盲按，不符合人體工學。
相對 v1.3 的改動：快門 SW3 從頂面按壓式 SKQG (9, 40) 換成側按式 ALPS SKRTLAE010（LCSC C110293），
放在上板邊右段 (50.6, 2.6) 轉 180 度，觸桿朝板邊伸出，桿頭在 y = 0.56，由外殼上牆的快門帽按壓。
封裝用專案內複本 esp32s3-camera:SW_Push_SKRTLAE010_Side（焊盤 1 由 0.75 縮到 0.55 mm，與定位孔留 0.15 mm）。
C12 下移 0.8 mm 到 (47.5, 6.3) 讓位；刪掉 GND 縫合過孔 (51,3)、(54,3)、(22.4,73.8)、(40,73.8)；IPROG 頂層斜線改繞 GND 過孔 (45.7,7.3)。
BTN_SHUTTER 走線：U1 pin 39 (21.25,72.49) 往左打過孔 (19.4,73.4)，底層沿模組下方 y = 73.3..73.4 到右板邊，沿 x = 59.35 往上到 y = 2，過孔 (53.8,2) 回頂層接 SW3；
原本到左欄 SW3 的 16 段頂層走線刪除。SW1 BOOT、SW2 RESET 不動。
58 顆 SMD 不變（SW3 換料號），CPL 只有 C12 與 SW3 兩行不同；插件 J4、J5。零件 60 顆。絲印、標題欄、Gerber ProjectId 皆為 v1.4。
驗證：ERC 0 錯誤（2 個 XC6206 符號庫警告）；DRC 含原理圖一致性 0 錯誤、0 警告、0 未連接、0 一致性問題；gnd_connectivity.py GND / +3V3 全部焊盤在主群集。
內容：原理圖、板檔、專案檔、網表、ERC/DRC 報告、fab/（Gerber zip、鑽孔、BOM 34 行、CPL 58 顆、JLCPCB-上傳-v1.4、下單清單、採購清單）、自訂 footprint 庫。
外殼：enclosure/ 同步改為 v1.4（快門帽在上牆、BOOT/RESET 針孔），組合件干涉 0 件。
腳本：render/illustration/v14_sch.py、v14_pcb.py、v14_pcb_fix.py、v14_pcb_fix2.py。
此資料夾視為唯讀。

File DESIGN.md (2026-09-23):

# ESP32-S3 相機板 — 設計規格書

## 目前狀態（2026-09-22，v1.4）

版本編號用數字：最初佈局是 **v1.0**，2026-09-17 改相機腳位並加相機 LDO 的是 **v1.1**，2026-09-21 加電源開關與電源燈的是 **v1.2**，同日晚上為了做 3D 列印外殼把螢幕改成板上母座的是 **v1.3**，2026-09-22 把快門改成板邊側按的是 **v1.4**。板上絲印、KiCad 標題欄、Gerber ProjectId 都已同步。各版整份存在 `versions/v1.0/`～`versions/v1.4/`（含 fab 輸出），視為唯讀；之後若再改板，先從 v1.4 快照比對差異。v1.2、v1.3 都沒有下單。

### v1.4 改了什麼（2026-09-22）：快門改到上板邊側按

起因：v1.3 的三顆按鍵都在鏡頭面左欄（x = 9），拿相機時那一面朝著被拍的人，要繞到前面盲按；快門離任何板邊都 9 mm 以上，外殼做不出邊按。

| 改動 | 內容 |
|---|---|
| SW3 SHUTTER | 頂面按壓式 SKQG (9, 40) → **側按式 ALPS SKRTLAE010**（LCSC **C110293**，4.5 × 3.55 × 3.5 mm，160 gf），放在**上板邊右段 (50.6, 2.6)** 轉 180°，觸桿朝 −y 伸出，桿頭在 y = 0.56、離板頂 1.75 mm。右手食指位置 |
| 封裝 | 專案庫 `esp32s3-camera:SW_Push_SKRTLAE010_Side`：KiCad 內建封裝的複本，兩個 pad 1 由 0.75 mm 縮到 0.55 mm，與 Ø0.9 定位孔留 0.15 mm（原封裝只有 0.075 mm，過不了孔間距規則）。兩個 pad 1 在板上用 0.2 mm 線於 y = 4.9 連通 |
| 讓位 | C12 下移 0.8 mm 到 (47.5, 6.3)，其 GND / +3V3 短線重接；刪 GND 縫合過孔 (51,3)、(54,3)、(22.4,73.8)、(40,73.8)；IPROG 頂層斜線改成 (44.6,6.7)→(46.5,6.7)→(46.5,7.7)→(47.2,8.4) 繞過 GND 過孔 (45.7,7.3) |
| 走線 | BTN_SHUTTER 從 U1 pin 39 (21.25, 72.49) 往左 (20.0, 72.49)→(19.4, 73.09) 打過孔 (19.4, 73.4)，底層沿模組下方 y = 73.4 走到 (58.5, 73.4)，沿右板邊 x = 59.35 往上到 (59.35, 2.0)，西行到過孔 (53.8, 2.0)，頂層 (53.8, 2.9)→(53.2, 3.5)→SW3 pad 1。SW3 pad 2 (GND) 往板邊方向短線到過孔 (50.6, 1.3)。原本到左欄 SW3 的 16 段頂層走線刪除。右板邊底層三條 IO4/5/6 線不動，新線離 IO4 過孔 0.25 mm、離板邊 0.55 mm |
| 不變 | SW1 BOOT、SW2 RESET 留在鏡頭面（外殼改針孔）；其餘 57 顆 SMD、J4、J5 不動。CPL 只有 C12 與 SW3 兩行不同 |
| 3D 模型 | KiCad 內建庫沒有 SKRTLAE010 的 STEP，用 SolidWorks 依 ALPS 圖面做了簡化模型 `models/SW_Push_SKRTLAE010_Side.step`（本體 4.5 × 2.56 × 3.5，觸桿 2 × 0.83 伸出 0.83、離板 0.95–2.55），封裝指向 `${KIPRJMOD}/models/`；示意圖板檔複本的 `render/illustration/models/` 也放一份。沒有它，板子 STEP 少一個實體、外殼干涉檢查會漏掉快門本體 |

**外殼**：`enclosure/` 同步改為 v1.4：前殼上牆開 6 × 4.2 的快門窗（Z 0.2–4.4），T 形快門帽凸緣 7.6 × 4.0 × 0.8 在牆內、頭 5.6 × 3.6 穿牆露出 1 mm，桿頭到牆內面 1.06 mm 所以預行程 0.26 mm；後殼唇口在同位置開缺口。BOOT / RESET 改成 Ø2 針孔，原本的長條凸台與三個圓按鈕帽取消。螢幕模組的固定：後殼底板長四支 Ø4 定位柱到模組 PCB 朝底板那一面（離板頂 13.84 mm），頂端 Ø1.8 凸柱穿進模組四角 Ø2 孔，窗框內側貼 0.5 mm 泡棉膠，模組不再只靠 J5 母座懸著。2026-09-23 把相機模組（含排線反折）、電池與電池線、記憶卡、螢幕模組也依文件尺寸建成簡化零件放進組合件，干涉 0 件；相機鏡座頂 6.9 mm 離原本 7 mm 的天花板只剩 0.1，前殼內高改 8 mm（整組 28.6 mm）。2026-09-23 外觀修飾：直角圓角 R3→R4.5，兩面外緣整圈 R2.5 倒圓，鏡頭孔外加 Ø16 凸 1.5 mm 的鏡座環，螢幕窗外 28.5 × 28.5 內縮 0.8 mm 邊框，鏡頭面左側六道握持溝紋。組合件干涉檢查 0 件（含用簡化 STEP 補上的 SW3 本體）。**2026-09-23 晚上改成螢幕用七條公–母杜邦線接 J5**（省事、不焊；母座腳序與模組一致，一對一插）：模組不再插母座，移到 x 10.4–49.6（中心 x 30，排針那排朝左 x 12.9），用 M2×4 鎖在後殼四支 Ø4.5 矮柱上；後殼內深 14.5 → 27.0 mm（杜邦公頭膠殼 14 mm 站在 8.5 mm 的母座上，再留 3.5 mm 讓線彎出來），整機 40.1 mm；外殼螺絲 M2×25 → M2×35；螢幕窗中心 (40.5, 45) → (28.4, 45)。杜邦線建成 `offboard-display-cable` 放進組合件，干涉 0 件。

**驗證（2026-09-22）**：ERC 0 錯誤（同樣 2 個 XC6206 符號庫警告）；`kicad-cli pcb drc --schematic-parity` 0 錯誤、0 警告、0 未連接、0 一致性問題；`gnd_connectivity.py` GND 與 +3V3 焊盤全部在主群集。
腳本：`render/illustration/v14_sch.py`、`v14_pcb.py` + `v14_pcb_fix.py` + `v14_pcb_fix2.py`。教訓：右下角底層 y 65 那條「看起來空的」通道其實有 VBAT 主幹、EN 迴路與 C5/C6 的 GND 過孔，第一版走線 DRC 抓出 10 個錯；改走模組下方 y 73.4 才乾淨。

**這版仍刻意不改**：LED 分兩面（D1/D4/D5 頂面、D2 底面）；板邊開口分三邊（USB-C 與電源開關右邊、記憶卡左邊、快門上邊）。

## 目前狀態（2026-09-21，v1.3）

（v1.3 當時的狀態說明，保留供對照；最新狀態見上方 v1.4。）

### v1.3 改了什麼（2026-09-21）：螢幕母座取代 J5/J6

起因：要 3D 列印相機式外殼（鏡頭在正面、螢幕在背面），v1.2 用杜邦線把螢幕接到 J5/J6 兩條直排針，在外殼裡收不乾淨。

| 改動 | 內容 |
|---|---|
| 拆掉 | J5 UART/DEBUG 1×4 排針、J6 EXPANSION 1×4 排針（都在底面右板邊 x = 56） |
| 新增 | **J5 1×7 2.54 mm 立式母座**（CJT A2541WV-7P，LCSC **C225482**，8.5 mm 高），底面右板邊 x = 56，pin 1 在 y 52.62（靠天線端，方形焊盤）、pin 7 在 y 37.38。1.3 吋 ST7789 模組出廠焊好的 7 pin 直排針**直接插進去**，亮面朝外，模組身體蓋在電池上方 |
| 腳序 | 照模組順序 1 GND、2 VCC(3V3)、3 SCL、4 SDA、5 RES、6 DC、7 BLK。**SCL = GPIO44（網路 UART_RX）、SDA = GPIO43（網路 UART_TX）**，與 v1.2 文件相反，這樣舊走線不用動；兩支都是 GPIO 矩陣任選腳，韌體填 SCK=44、MOSI=43 即可。RES/DC/BLK = GPIO6/5/4 |
| 走線 | UART_TX、UART_RX 的頂層線只改末端 0.1 mm 落到新焊盤；IO6、IO5、IO4 從原本到 J6 的頂層線末端各打一顆過孔，沿右板邊底層 x = 57.4 / 58.05 / 58.7 三條 0.2 mm 線往上，依序轉進 pin 5、6、7，互不交叉。GND、3V3 是通孔焊盤，直接接 In1 / In2 內層平面，不加過孔 |
| 絲印 | 底面每支腳旁印 GND 3V3 SCL SDA RES DC BLK（0.8 mm 高），母座下方印 DISPLAY；B.Fab 畫出模組 27.78 × 39.22 的投影框 |
| 不變 | 58 顆 SMD 全部不動，CPL 與 v1.2 完全相同；J4 不動。零件 60 顆 = 58 SMD + 2 插件（J4、J5） |
| 少掉 | UART0 除錯排針。USB 序列埠（USB-CDC）照常；螢幕拔掉時母座 pin 3/4 就是 RX/TX，要接 UART 轉接板仍可 |

**機構數字（給外殼用）**：模組投影 x 19.3–58.5、y 31.1–58.9（中心 (38.9, 45)），四角 Ø2 孔在 (21.8, 33.6)、(56, 33.6)、(21.8, 56.4)、(56, 56.4)，與板子 M2 孔不對位，外殼用螢幕窗壓住模組即可，母座本身的插拔力也夠。
有效顯示區 23.4 × 23.4 mm，中心約 **(40.5, 45)**（模組玻璃偏向排針那一側 1.6 mm）。
> 2026-09-23 改用杜邦線接法後模組移到 x 10.4–49.6、排針朝左，顯示區中心 **(28.4, 45)**，四角孔 (12.9, 33.6)、(47.1, 33.6)、(12.9, 56.4)、(47.1, 56.4)；見下方與 2d 節。
底面高度（直插版）：母座 8.5 + 模組自帶排針塑膠 2.54 = 模組 PCB 背面離板底 **11.0 mm**，再加模組 PCB 1.2 與玻璃 1.6，亮面約 **13.9 mm**；電池 6 + 泡棉 2 = 8 mm，到模組背面還有 3 mm。
底面高度（**杜邦線版，2026-09-23 起採用**）：J5 上的公頭膠殼到板底下 22.5，線彎出來 3.5，外殼內深 27.0；模組背面 23.6、亮面 26.4，電池到模組背面之間 15.6 mm 就是走線的空間。
母座本體 x 54.73–57.27、y 36.1–53.9，離電池投影（x ≤ 49）5.7 mm；LDO_EN 頂層線 (58.6→54.5, 43.81) 現在穿過 J5 pin 4、5 之間（間距 0.24 / 0.40 mm）。

**驗證（2026-09-21 22:20）**：ERC 0 錯誤（同樣 2 個 XC6206 符號庫警告）；`kicad-cli pcb drc --schematic-parity` 0 錯誤、0 警告、0 未連接、0 一致性問題；`gnd_connectivity.py` GND 與 +3V3 焊盤全部在主群集、無孤島。
腳本：`render/illustration/v13_sch.py`（原理圖）、`v13_pcb.py` + `v13_pcb_fix.py` + `v13_pcb_fix2.py`（板子，KiCad 附的 python）。pcbnew 的 python 拆零件時要把回傳物件留在變數裡，否則被回收後板子清單裡留下懸空指標，下一次迭代會噴 `SwigPyObject has no attribute GetReference`。

**外殼**：2026-09-22 已用 SolidWorks 依本版座標建好兩片殼與組合件，見 `enclosure/README.md`（內含每個尺寸的依據）。

**外殼還沒做的事（討論過、這版刻意不改）**：快門 SW3 仍是頂面垂直按壓式，外殼要做按鈕柱；LED 分兩面（D1/D4/D5 頂面、D2 底面）；板邊開口分三邊（USB-C 與開關右邊、記憶卡左邊）。要改就是 v1.4。

### v1.2 改了什麼（2026-09-21）

| 新零件 | 位置 | 料號 | 作用 |
|---|---|---|---|
| SW4 滑動開關 MSK12C02（SPDT） | 頂面右上板邊 (57.6, 11)，J1 上方，撥桿朝右板邊 | C431540（Extended） | 開關機 |
| R21 100 kΩ 0603 | 底面 (53.2, 41.7)，U2 右側 | C25803 | EN 上拉到 VSYS |
| R20 1 kΩ 0603 | 頂面 (53, 8.2) | C21190 | 電源燈限流 |
| D5 藍色 0603 LED | 頂面 (53, 11.2) | C2288 | 電源燈，接 3.3V，開機就亮 |

**電路**：開關不切電池，而是控制 U2（AP2112K）的 EN 腳。v1.1 的 EN 直接接 VSYS；v1.2 把 U2 pin 3 改成新網路 `LDO_EN`，由 R21 上拉到 VSYS，SW4 的共用端接 LDO_EN、一端接 GND、另一端空接。
撥到接地那一側 = 關機：3.3V 全斷，ESP32、相機、記憶卡、LED 全部斷電，電池只剩穩壓器 10 nA 級待機電流加保護板本身耗電；插著 USB 時 TP4056 仍照常充電，D2 紅燈照常。
撥到空接那一側 = 開機。開關只流 EN 腳的微安級電流，MSK12C02 的 50 mA 額定綽綽有餘。
D5 接在 3.3V 上，開機必亮、關機必熄，不靠韌體；耗電約 1 mA。

**佈線**：LDO_EN 從 SW4 沿右板邊 x = 58.6 往下，穿過 J5 排針 pin 2、3 之間（各留 0.32 mm；v1.3 換成 1×7 母座後是 pin 4、5 之間，0.24 / 0.40 mm）到 (54.5, 43.8) 過孔，底面經 R21 到 U2 pin 3。
U2 pin 3 原本兼作 C1、C2 的 VSYS 接入點，拆開後 C1/C2 的 VSYS 改由新過孔 (49.6, 46.9) 經一段 3 mm 的 In2 內層跳線接到 VSYS 主幹上的過孔 (50.9, 43.45)。刪掉一顆擋路的 GND 縫合過孔 (53.5, 42.7)。
改動全由腳本完成（`render/illustration/v12_sch.py`、`v12_pcb.py`，需 KiCad 附的 python），先在副本上跑到 ERC/DRC 乾淨才套用。
SW4 的 KiCad 內建 3D 檔不存在，板檔改指向外形相同的 `SW_SPDT_PCM12.step`，只影響 3D 顯示。

**2026-09-21 送洗前最後檢查發現並修正的問題**（腳本 `render/illustration/fix_v12_gnd.py`，KiCad 附的 python 執行）：

| 問題 | 修法 |
|---|---|
| **J2.23（相機 AGND）焊盤浮接**：只接到一片 0.2 mm² 的孤立敷銅，沒有過孔到內層地。v1.1 起就存在 | IPROG 頂層走線在 x 34.4–39.65 這段上移到 y 2.85 並把斜線右移；在 (37.0, 3.45) 加 GND 過孔，0.2 mm 線經 (35.25, 3.95)、(35.7, 3.5) 接回焊盤 |
| **C3.2（22 µF 3.3V 輸出電容 GND）焊盤浮接**：只接到 2 mm² 孤立敷銅。v1.1 起就存在 | 底層在 (42.8, 53.0) 加 GND 過孔，0.3 mm 線接到焊盤 |
| R21 兩腳網路與原理圖相反（電阻無極性，電氣無差，但 Update PCB from Schematic 會翻回來造成短路） | R21 轉 180°，pad 1 = VSYS、pad 2 = LDO_EN，標號移回原位 |
| D5/R20/R21/SW4 封裝缺庫名前綴、全部 61 顆缺 LCSC 欄位、SW4 pad 1 無網路 | 補齊，現在 DRC 的原理圖一致性檢查 0 問題 |
| C9 標號壓到 J2 絲印外框 | 標號移到零件下方 |

這兩個浮接焊盤就是之前 DRC 一直報的「2 條 GND 敷銅未連接」。過去把它當成無害的敷銅碎片是錯的：KiCad 只會回報兩個群集間最近的一對物件，剛好都是敷銅，焊盤本身就被藏在後面。
以後看到 zone unconnected 一律用 `render/illustration/gnd_connectivity.py` 跑一次幾何連通性（把焊盤、過孔、走線、敷銅島做 union-find），確認沒有焊盤落在主群集之外。
修正後 Gerber、鑽孔（PTH 從 319 孔變 321 孔）、CPL（只有 R21 旋轉角從 90 變 −90）於 2026-09-21 18:16 重新輸出，BOM 與原理圖未變。

**開關方向（2026-09-21 已依規格書標上絲印）**：Vimex 的 MSK-12C02 圖面顯示撥桿撥向哪一端，中間共用腳就接到那一端的腳。
板上 pad 3（GND）在 y 8.75、靠板子上緣；pad 1（空接）在 y 13.25、靠模組。所以撥桿**往上緣（角落孔那側）= OFF、往下（往模組）= ON**，
頂面絲印在開關上方印「OFF」、下方印「ON」（`render/illustration/v12_silk_onoff.py`）。撥桿行程 1.5 mm，外殼開槽對 x = 58–60、y = 8–14 mm 的右板邊。
收到板子仍請以藍燈實測一次，方向若與絲印相反代表買到的相容品機構相反，改用另一側即可，電路不用動。

| 項目 | 狀態 |
|---|---|
| 原理圖 | ✅ ERC 0 錯誤（2 個 XC6206 符號庫比對警告，開 KiCad 後「從庫更新符號」即可清除） |
| 板子與原理圖一致性 | ✅ 0 問題（2026-09-21 18:15 以 `kicad-cli pcb drc --schematic-parity` 驗證，含 LCSC 欄位與 R21 腳位） |
| 佈件 | ✅ 60 個零件雙面：58 SMD + 2 插件 J4、J5（v1.2 新增 SW4、R20、R21、D5；v1.3 J5/J6 併成 1×7 母座；v1.4 SW3 換側按式移到上板邊） |
| 內層平面 | ✅ In1 = GND、In2 = +3V3 |
| 線寬／間距 | ✅ 訊號 0.2 mm、間距 0.15 mm；VBAT/VSYS/+5V 0.6 mm；3V3/GND 短接線 0.3 mm |
| 佈線 | ✅ 全部網路接通（2026-09-18 補完 +5V、+2V8 最後幾段） |
| DRC | ✅ v1.4 於 2026-09-22 複跑（含原理圖一致性）0/0/0/0；v1.3 於 2026-09-21 22:20 複跑 0/0/0/0；v1.2 於 2026-09-21 18:15 複跑（含敷銅重填）：0 錯誤、0 警告、0 未連接焊盤、0 原理圖一致性問題。先前的「2 個 GND 敷銅提示」其實是 J2.23 與 C3.2 焊盤浮接，已加過孔修正（見上表） |
| GND / +3V3 連通性 | ✅ 幾何連通性腳本：GND 66 個焊盤、+3V3 29 個焊盤全部接到主群集 |

### 2026-09-17 這一版改了什麼

1. **J2 相機腳位改成 AI-Thinker ESP32-CAM 標準 24pin 定義**（見第 4 節），原本的順序對不上任何市售模組。
2. **新增 2.8V（U5 XC6206P282MR）與 1.2V（U6 XC6206P122MR）LDO** 供 AVDD / DVDD，DOVDD 接 3.3V。用 OV5640 模組時 U6 換成 XC6206P152MR（1.5V），焊盤相同。
3. 相機 GPIO 對應重排，讓 16 條線從 J2 到模組不交叉（韌體 `camera_config_t` 要照新表填）。
4. 電源線加寬，TP4056 散熱焊盤下補 4 顆 GND 過孔，每個 GND / 3V3 表面焊盤都有自己的過孔。
5. 改動前的原理圖、板子與專案檔（v1.0 最後狀態）存放在 `versions/v1.0/`，見該資料夾的 README。

### 3D 渲染與示意圖（2026-09-18）

- `render/` 內是 kicad-cli 光線追蹤輸出：`iso-top/iso-bottom/top/bottom/low-angle/closeup-*.png` 為裸板貼片後的樣子，`assembled-*.png` 與 `closeup-camera-module.png` 為插上相機、記憶卡、墊上電池的組裝示意。KiCad 的 VRML 讀取器不畫 `Cylinder` 基本體，圓柱要用 IndexedFaceSet 網格；相機模型由 scratchpad 的 `gen_camera_wrl.py` 產生。
- J1（HCTL USB-C）與 U3（ESOP-8 EP2.41x3.3）在 KiCad 內建庫沒有對應 3D 檔，已改指向外形相同的 `USB_C_Receptacle_GCT_USB4105-xx-A_16P_TopMnt_Horizontal.step` 與 `SOIC-8-1EP_..._EP2.41x3.81mm.step`。只影響 3D 顯示，焊盤與 Gerber 不變。
- `render/illustration/` 是專門給組裝示意用的板檔複本，多了三個沒有焊盤的假零件掛簡化 VRML 模型。**不要用它出 Gerber。**
- 2026-09-18 整理檔案：中間過程的 `*.bak_before_fix2 / fix3 / 3dfix / lcsc` 與舊 Gerber zip 已刪除（差異皆已收進正式檔）。`.history/` 是 KiCad 自動快照，由 KiCad 管理。

### 版本管理規則

- 根目錄永遠是「正在改的最新版」。每次出 Gerber 準備下單時，把 `.kicad_pcb / .kicad_sch / .kicad_pro`、`esp32s3-camera.pretty/`、`fp-lib-table` 和 `fab/` 內的 zip、BOM、CPL 複製一份到 `versions/vX.Y/`，並在該資料夾放 README 寫這一版改了什麼。
- 版本號用數字（v1.0、v1.1、v1.2…），不用 rev A / rev B。板上絲印、KiCad 標題欄 rev、Gerber ProjectId 三處同步。
- 已有：`versions/v1.0/`（2026-09-17 改 J2 前）、`versions/v1.1/`（2026-09-18）、`versions/v1.2/`（2026-09-21 白天，未下單）、`versions/v1.3/`（2026-09-21 晚上，螢幕母座，未下單）、`versions/v1.4/`（2026-09-22，側按快門，下單版）。
- 不要再用 `*.bak_before_xxx` 這種散在根目錄的備份；改動過程中的臨時快照交給 KiCad 的 `.history/`。
- 2026-09-18 板上絲印改為「ESP32-S3 CAMERA  v1.1」，`.kicad_pcb` 補上標題欄 rev 1.1，`.kicad_sch` 標題欄 rev 同步為 1.1，並以 kicad-cli 重出 Gerber、鑽孔檔與 zip。

### 下單前建議再做一次

1. 在 KiCad 開啟專案，Tools → Update PCB from Schematic 確認 0 差異；跑一次 DRC。2026-09-21 18:15 以 kicad-cli 跑過 DRC + schematic parity，全部為 0，但 KiCad GUI 的比對可能多列出符號庫版本差異，屬警告。
2. 在 3D 檢視確認 U5/U6/C12–C17（J2 右側）與相機排線走向不打架。
3. `fab/` 內的 Gerber、鑽孔、CPL 是 2026-09-21 18:16 依修正後板子重新輸出的（BOM 為 2026-09-21 14:14 版，原理圖未變），上傳 JLCPCB 預覽確認層數為 4 層。
   BOM 已含 `LCSC Part #` 欄（2026-09-18 於原理圖每顆零件加上 `LCSC` 欄位後以 kicad-cli 重新輸出），JLCPCB 上傳後可自動配對；電阻電容 LED 全部選 Basic Part。
   重新輸出指令：`kicad-cli sch export bom --fields "Reference,Value,Footprint,QUANTITY,LCSC" --labels "Designator,Comment,Footprint,Qty,LCSC Part #" --group-by "Value,Footprint,LCSC" --exclude-dnp -o fab/esp32s3-camera-bom.csv esp32s3-camera.kicad_sch`
   D3 的料號是 **C8598（B5819W，SOD-123，Basic）**，不是 SS14：LCSC 上的 SS14 是 SMA/DO-214AC 封裝，跟板上 SOD-123 焊盤不合。
   同日也清掉了 `.kicad_sch` 檔尾一段重複殘留的內容（約 17,900 行，與前段完全相同，KiCad 原本就會忽略）。
4. 自動補的走線有些是 45° 階梯狀，電氣正確但不美觀，想整理可在 pcbnew 手動拉直。

**2. 相機模組的擺法：排線反折、模組貼回板面**

模組不要懸在板子上緣外，排線一碰就凹。做法跟 ESP32-CAM 一樣：排線從 J2 往板邊出來約 2.5 mm 就 180° 反折，
回頭蓋過 J2，模組躺在板面上、鏡頭朝上。用 21 mm 排線時模組會落在 **x 25.5–34.5、y 20.5–29.5 mm**
（按鍵那一欄與 U4 之間），那一區只有走線、沒有零件，最高的鄰居是 C17（y 20.5，x 40.3），不會碰到。
模組底下墊一塊 8 × 8 mm、約 2 mm 厚的雙面泡棉膠固定，同時墊高到排線折回的高度。
板上沒有螺絲孔可鎖模組；若外殼要開鏡頭孔，孔心對 (30, 25) mm。
排線長度不同時模組落點會變：落點 y ≈ 6.5 + (排線長 − 3.5) − 4.5。

**2b. 電池的擺法：貼在底面中央，墊 2 mm 泡棉**

建議用 **603040**（30 × 40 × 6 mm，約 600 mAh）或更小的 502535，中心放在底面 **(34, 44) mm**，長邊沿 Y，
保護板那一端朝下緣（y 大的那側），引線繞到左邊的 J4。

**J4 極性**：pin 1 = VBAT（正極），pin 2 = GND。pin 1 焊盤在 (12, 62)、pin 2 在 (10, 62)，
也就是 pin 1 靠板子中央、pin 2 靠左板邊。底面絲印在 pin 1 那一側有 L 形記號。
把底面朝自己、天線那端朝下來看，pin 1 在左、pin 2 在右（`render/closeup-j4.png`）。
JST PH 插頭本身有防呆只能單向插入，所以要確認的是電池線材：紅線必須壓在會對到 pin 1 的那一格，不合就把插頭裡的端子對調。2026-09-18 用 pcbnew 讀出底面全部零件外框與高度核對過：

| 檢查項 | 結果 |
|---|---|
| 電池投影範圍 | x 19–49、y 24–64 mm |
| 投影範圍內最高零件 | 0805 電容 1.3 mm（C1、C3、C10），墊 2 mm 泡棉即可跨過 |
| 到 J5 螢幕母座（8.5 mm 高，v1.3） | 5.7 mm（母座本體 x ≥ 54.73） |
| 到 J4 電池座（6 mm 高） | 4.5 mm |
| 到天線淨空區（y ≥ 74.5） | 10.5 mm，不會壓在天線上 |
| 到 U3 充電 IC（會發熱） | 12 mm 以上 |
| 底面總厚度 | 電池 6 + 泡棉 2 = 8 mm；v1.3 螢幕模組背面在 11.0 mm，還有 3 mm 餘裕 |

換 803040（8 mm 厚）位置相同，底面總厚變 10 mm；換 103450（34 × 50 × 10）放 (35, 45) 也放得下，但離母座只剩 2.7 mm、離螢幕背面 1 mm，
且底面總厚 12 mm。電池不要往下緣挪：壓到天線淨空區會讓 Wi-Fi 變差。核對腳本是 `render/illustration/battery_check.py`（用 KiCad 附的 python 執行），
邏輯是把底面零件的 courtyard 外框與估計高度，對照電池投影範圍。

**2c. microSD 卡插入方向**

J3（Hirose DM3AT-SF-PEJM5）在底面，開口朝**左板邊**（x = 0 那一側，USB-C 在對面的右板邊）。
Hirose 型錄寫明 DM3AT 是 Top board mounting（Standard）型：卡片**金手指面朝電路板**、標籤面朝外。
板子正面朝上時，卡片標籤朝下、金手指朝上插進去；翻到底面朝上時剛好相反。
Push-push 機構：推到底會「喀」一聲鎖住，再推一下退出。插到底時卡片仍露出板邊約 4.6 mm，外殼在左側要留插卡口。
座子有防反插保護，方向錯了推不進去，不要硬壓。

**2d. 即時預覽螢幕（v1.3：板上 1×7 母座 J5，模組直接插）**

> 2026-09-21 白天原本決定 v1.2 用杜邦線外接、不做 v1.3；同日晚上因為要 3D 列印外殼改成 v1.3：J5/J6 拆掉，換一個 1×7 母座讓模組直插。以下腳位描述已改為 v1.3。

需求：看到鏡頭對準的畫面。腳位餘量只有 GPIO4/5/6（J6）與 strapping 的 45/46，SPI TFT 需要 5 支訊號腳，
解法是**借用 UART0 的 GPIO43/44 當 SPI 時脈與資料**（ESP32-S3 的 GPIO 矩陣允許 SPI2 用任意腳，40 MHz 內沒問題），
BLK/DC/RES 用 GPIO4/5/6，電源從同一個母座拿。代價是失去 UART 除錯排針（USB 序列埠仍可用；螢幕拔掉時母座 pin 3/4 就是 GPIO44/43）。

**指定面板（2026-09-21 定案）：通用型 1.3 吋 IPS 240×240 ST7789 模組，7 pin 2.54 mm 焊接式**（市售名稱 GMT130-V1.0、ZJY133T-IG01、lcdwiki「1.3inch IPS Module」，
搜尋關鍵字「1.3吋 IPS 240x240 ST7789 7pin」，蝦皮約 NT$150–220）。選它的理由：有完整尺寸圖、板子 27.78 × 39.22 mm 剛好蓋在電池上、四角有 Ø2 mm 孔可鎖外殼、沒有 CS 腳正好配合專用 SPI 匯流排。
尺寸（lcdwiki 圖面）：PCB 27.78 × 39.22 mm；四角孔 Ø2.0，距邊 2.5 mm（孔距 22.78 × 34.22）；7 pin 與上緣兩孔同一排、距上緣 2.5 mm，第一腳距左緣 6.27 mm，順序 GND VCC SCL SDA RES DC BLK；
顯示玻璃 25.8 × 29.22 mm，上緣距板頂 5.0 mm；有效顯示區 23.4 × 23.4 mm；含玻璃厚約 2.8 mm。

| 模組腳 | 接到 | ESP32-S3 |
|---|---|---|
| GND | J5.1（方形焊盤，靠天線端） | — |
| VCC | J5.2 | 3V3 |
| SCL（SPI SCK） | J5.3 | **GPIO44**（網路 UART_RX） |
| SDA（SPI MOSI） | J5.4 | **GPIO43**（網路 UART_TX） |
| RES | J5.5 | GPIO6 |
| DC | J5.6 | GPIO5 |
| BLK | J5.7 | GPIO4，可用程式關背光省電 |

母座腳序就是模組腳序，插上去一對一，不會接錯；板上每支腳旁都有絲印。腳位是 2026-09-21 晚上依模組圖面推算：模組排針那一邊朝右板邊、亮面朝外時，模組 pin 1（GND）落在 y 大的那一端。**第一片板子插螢幕前，先對一次模組絲印的 GND 是否對到板上 GND 那一格**；若買到的相容品腳序相反，不要硬插，改用杜邦線交叉接。

替代品：Waveshare 1.3inch LCD Module（ICShop 368031700013，NT$225，含 20 cm PH2.0 8 pin 線）電路一樣可用，但板子 45 × 31 mm 較大、腳序不同（VCC GND DIN CLK CS DC RST BL），不能直插母座，要用它附的線對接，CS 接 GND。

microSD 維持 SDMMC 模式，不與螢幕共用匯流排。預期 240×240 RGB565 約 10–15 fps。
機構（v1.3 原案）：螢幕在底面朝外（與鏡頭相反面），模組自帶的 7 pin 直排針插進 J5 母座，身體蓋在電池上方，沒有任何線。

> **2026-09-23 改為杜邦線**：模組排針不插母座，改用七條公–母杜邦線（公頭插 J5、母頭套模組排針，腳序一對一，GND 對 GND）。理由是省事、不用焊。模組移到 x 10.4–49.6、排針那排朝左（x 12.9，離 J5 遠一點才有空間繞線），四角用 M2×4 鎖在後殼矮柱上；杜邦膠殼 14 mm 讓外殼後半加深到 27 mm 內深（整機 40.1 mm）。買到腳序相反的相容品也不用改板，線交叉接即可。細節與走線在 `enclosure/README.md`。
3D 示意（`render/assembled-bottom.png`、`assembled-iso-bottom.png`、`assembled-bottom-low.png`）依上述圖面 1:1 畫出：模組轉 90°，中心 (38.9, 45)，
佈滿 x 19.3–58.5、y 31.1–58.9，排針那一邊在 x = 56 對準母座，四角孔落在 (21.8, 33.6)、(56, 33.6)、(21.8, 56.4)、(56, 56.4)。
螢幕是正方形，轉 90° 不影響畫面，韌體用 rotation 調；模型由 `render/illustration/gen_display_wrl.py` 產生。
底面高度（直插版）：母座 8.5 + 模組排針塑膠 2.54 → 模組 PCB 背面離板底 11.0 mm，亮面約 13.9 mm。杜邦線版：模組背面 23.6、亮面 26.4，外殼底側內深 27.0。想壓低可換 5 mm 高的矮母座（模組背面降到 7.5 mm，就要改用 5 mm 厚的 503040 電池 + 1 mm 泡棉）。

**3. GND 敷銅碎片與 DRC 的 zone unconnected（2026-09-21 更正）**

外層 GND 敷銅被繞線切碎成許多小島，敷銅設定是「移除孤島」，所以留下來的每一塊都至少黏著一個 GND 物件。
這一節原本寫「DRC 報的 zone unconnected 電氣上沒有影響」，**這是錯的**：2026-09-21 送洗前檢查發現那兩條回報各自藏著一個只靠小碎片、沒有過孔的焊盤（J2.23 相機 AGND、C3.2 輸出電容 GND），已加過孔修正。
規則改為：DRC 只要有 unconnected_items，不管它指的是不是敷銅，都要用 `render/illustration/gnd_connectivity.py` 跑一次幾何連通性確認每個焊盤都在主群集裡；0 才算過。

### 輸出檔案

`fab/` 底下有 Gerber（含四層）、鑽孔檔、BOM、貼片座標（CPL），
以及打包好的 `esp32s3-camera-gerber.zip`。

目標：2 層板、可 JLCPCB 發包、USB-C 供電與燒錄、DVP 相機模組、microSD 存檔、鋰電池供電。

---

## 1. 系統架構

```
              USB-C ──┬── ESD ──── ESP32-S3 USB (GPIO19/20)
                      │
                      └── 5V ──┬── TP4056 充電 ──── LiPo 3.7V ──┐
                               │                                │
                               └────────── 理想二極體 OR ────────┘
                                                │
                                             VSYS
                                                │
                                          LDO 3.3V / 1A
                                                │
                        ┌───────────────────────┼──────────────┐
                        │                       │              │
                   ESP32-S3-WROOM-1        相機模組       microSD
                     (N16R8)              (DVP 24pin)     (SPI/SDMMC)
```

## 2. 為什麼這樣選

| 決策 | 理由 |
|---|---|
| 用 **WROOM-1 模組**，不用裸晶片 | 模組已過認證、內建天線與晶振。裸晶片要做 50Ω 天線走線、π 型匹配、外掛 flash/PSRAM，2 層板做不好 |
| 一定要 **N16R8**（8MB PSRAM） | 相機 framebuffer 放在 PSRAM。沒有 PSRAM 只能跑 QVGA 320×240 且無法 JPEG 緩衝 |
| **DVP 並列介面**，不用 MIPI CSI | MIPI 是差動高速訊號，需 4 層板 + 阻抗控制 + 等長。DVP 是 8-bit 並列，最高 ~20MHz，2 層板隨便走 |
| **相機用 FPC 連接器**，不焊裸 sensor | 買現成 OV2640/OV5640 模組（含鏡頭座與對焦鏡頭），焊裸 sensor 要處理 CSP 封裝與光學對位 |
| **LDO 而非 buck** | 峰值 ~500mA，LDO 壓降損耗可接受，且無開關雜訊干擾影像。省掉電感與 layout 難度 |

## 3. 零件選型（BOM）

| 編號 | 零件 | 型號 | 封裝 | 數量 | 備註 |
|---|---|---|---|---|---|
| U1 | 主控模組 | ESP32-S3-WROOM-1-N16R8 | Module | 1 | **務必是 N16R8**，不要 N8 無 PSRAM 版 |
| U2 | LDO 3.3V | AP2112K-3.3TRG1 或 ME6211C33M5G | SOT-23-5 | 1 | 600mA~1A，壓差低 |
| U3 | 鋰電充電 IC | TP4056 (帶保護建議搭 DW01+FS8205) | SOP-8 | 1 | 或用 MCP73831 (SOT-23-5) |
| U4 | USB ESD 保護 | USBLC6-2SC6 | SOT-23-6 | 1 | D+/D- 靜電防護 |
| J1 | USB-C 母座 | TYPE-C-31-M-12 (16pin 簡化版) | SMD | 1 | CC1/CC2 各接 5.1k 下拉 |
| J2 | 相機 FPC 座 | 24pin 0.5mm 掀蓋式 下接觸 | SMD | 1 | 對應 OV2640/OV5640 標準模組 |
| J3 | microSD 卡座 | 推push-push 型 | SMD | 1 | |
| J4 | 電池座 | JST PH 2.0mm 2pin | THT | 1 | |
| SW1 | BOOT 按鍵 | 輕觸開關 | SMD 3×4 | 1 | GPIO0 |
| SW2 | RESET 按鍵 | 輕觸開關 | SMD 3×4 | 1 | EN |
| SW3 | 快門按鍵 | 輕觸開關 | SMD 3×4 | 1 | GPIO1（GPIO47 已改給相機 D1，見第 4 節） |
| SW4 | 電源開關（v1.2） | MSK12C02 SPDT 滑動 | SMD 8×2.8 | 1 | 控制 U2 EN，C431540 |
| D1 | 狀態 LED | 0603 綠 | 0603 | 1 | GPIO2 |
| D2 | 充電指示 LED | 0603 紅 | 0603 | 1 | TP4056 CHRG |
| D5 | 電源 LED（v1.2） | 0603 藍 | 0603 | 1 | 接 3.3V 經 R20 1k，C2288 |
| R21 | EN 上拉（v1.2） | 100kΩ | 0603 | 1 | VSYS → LDO_EN |
| Q1 | 閃光燈 MOSFET | AO3400A (N-ch) | SOT-23 | 1 | 若要高亮 LED |
| C_bulk | 電解/鉭質 | 22µF | 0805 或 A 型 | 2 | LDO 輸入輸出各一 |
| C_dec | 去耦電容 | 100nF | 0402/0603 | ~10 | 每顆 IC 電源腳旁 |
| C_cam | 相機電源 | 10µF + 100nF | 0603 | 各 1 | 靠近 J2 |
| R_usb | CC 下拉 | 5.1kΩ | 0402/0603 | 2 | **必要**，否則 USB-C 不供電 |
| R_i2c | SCCB 上拉 | 4.7kΩ | 0603 | 2 | SIOC/SIOD 拉到 3V3 |
| R_led | LED 限流 | 1kΩ | 0603 | 2~3 | |
| R_boot | 按鍵上拉 | 10kΩ | 0603 | 3 | |

> LCSC 料號已於 2026-09-18 填入原理圖 `LCSC` 欄位並輸出到 `fab/esp32s3-camera-bom.csv`。庫存會變動，下單前仍請在 JLCPCB 頁面確認每顆有貨；電阻電容 LED 皆為 **Basic Part**（免上料費）。

## 4. 腳位配置（關鍵，先確認再畫）

### ⚠️ 不可使用
- **GPIO26–32**：內部 SPI Flash 專用
- **GPIO33–37**：Octal PSRAM 專用（R8 版本）
- GPIO22–25：ESP32-S3 上不存在

### 相機 DVP（J2 = AI-Thinker ESP32-CAM 標準 24pin 定義）

J2 腳位照 ESP32-CAM 原理圖的 24pin 座定義（來源：AI-Thinker ESP32_CAM_V1.6 schematic）。
模組要買 **底接觸（bottom contact）、跟 ESP32-CAM 相容** 的 OV2640/OV5640 24pin 排線模組。
GPIO 對應是為了讓 16 條線從 J2 到模組不交叉而排的，韌體 `camera_config_t` 照這張表填。

| J2 pin | 模組訊號 | 接到 |
|---|---|---|
| 1, 2 | Y0, Y1（10-bit 低兩位，不用） | 空接 |
| 3 | Y4 = D2 | GPIO48 |
| 4 | Y3 = D1 | GPIO47 |
| 5 | Y5 = D3 | GPIO21 |
| 6 | Y2 = D0 | GPIO14 |
| 7 | Y6 = D4 | GPIO13 |
| 8 | PCLK | GPIO12 |
| 9 | Y7 = D5 | GPIO11 |
| 10 | DGND | GND |
| 11 | Y8 = D6 | GPIO10 |
| 12 | XCLK | GPIO9 |
| 13 | Y9 = D7 | GPIO3 |
| 14 | DOVDD | +3V3 |
| 15 | DVDD | +1V2（U6） |
| 16 | HREF | GPIO8 |
| 17 | PWDN | GPIO18 |
| 18 | VSYNC | GPIO17 |
| 19 | RESET | GPIO16 |
| 20 | SIOC (SCL) | GPIO15 |
| 21 | AVDD | +2V8（U5） |
| 22 | SIOD (SDA) | GPIO7 |
| 23 | AGND | GND |
| 24 | NC | 空接 |

> GPIO3 是 strapping pin，但它只決定 JTAG 訊號來源，不影響開機，
> 拿來當一般 GPIO 是安全的（Espressif 自家板子也這樣用）。

### microSD（SDMMC 1-bit 或 SPI）
| 訊號 | ESP32-S3 |
|---|---|
| CLK | GPIO39 |
| CMD / MOSI | GPIO38 |
| D0 / MISO | GPIO40 |
| CS / DAT3 | GPIO41 |

### 其他
| 功能 | ESP32-S3 |
|---|---|
| USB D− | GPIO19 |
| USB D+ | GPIO20 |
| UART0 TX ＝ 螢幕 SDA（J5.4） | GPIO43 |
| UART0 RX ＝ 螢幕 SCL（J5.3） | GPIO44 |
| BOOT 按鍵 | GPIO0 |
| 狀態 LED | GPIO2 |
| 閃光燈 | GPIO42 |
| 快門按鍵 SW3（v1.4 起側按式，上板邊 (50.6, 2.6)） | GPIO1 |
| 螢幕 BLK / DC / RES（J5.7 / 6 / 5） | GPIO4, 5, 6 |
| 未使用 | GPIO45, 46（strapping，刻意空接） |

> GPIO45/46 是 strapping pin，開機瞬間電位會影響啟動模式，**不要接按鍵或會被外部拉動的東西**。GPIO0 是 BOOT，接按鍵到 GND 是標準做法。

## 5. 必做的電路細節（新手最常漏）

1. **USB-C 的 CC1、CC2 各要一顆 5.1kΩ 下拉到 GND** — 少了這個，充電器不會送電，板子完全不會亮。兩顆分開接，不可共用一顆。
2. **EN 腳的上電延遲**：EN 接 10kΩ 上拉到 3V3 + 1µF 對地。ESP32 需要電源穩定後才釋放 reset，少了這個會隨機開機失敗。
3. **相機的 XCLK 走線盡量短**，這是唯一比較快的訊號（20MHz）。D0–D7 不需等長，但別繞遠路。
4. **模組天線下方要挖空**：WROOM-1 天線那一端伸出板邊，或至少該區域的頂層/底層都不鋪銅、不走線。這是最常見的翻車點。
5. **去耦電容貼著 IC 電源腳放**，不要放在板子另一頭。
6. **UART0 (GPIO43/44) 拉出 2.54mm 排針** — 燒錄雖然走 USB，但出問題時序列埠 log 是唯一救命線索。
7. **相機模組電源獨立去耦**：J2 旁放 10µF + 100nF，OV2640 的電流會抖。

## 6. PCB 疊構與規格

**60 × 85 mm、4 層、板厚 1.6mm、1oz 銅。**

| 層 | 用途 |
|---|---|
| F.Cu | 訊號 + GND 敷銅 |
| In1.Cu | 完整 GND 平面 |
| In2.Cu | +3V3 電源平面 |
| B.Cu | 訊號 + GND 敷銅 |

為什麼從原本規劃的 2 層改成 4 層：16 位元並列匯流排加上 24 個焊盤的 +3V3
網路，2 層根本走不完（實測最多只能繞到 45/47 條）。而且 20MHz 的 XCLK/PCLK
需要一個完整的參考平面才不會亂輻射。JLCPCB 4 層 5 片大約比 2 層貴 5 美金。

為什麼是 60×85 而不是更小：**JLCPCB 對 100×100mm 以內收同一個價**，
所以放大板子是免費的，而 50×75 太擠導致佈線失敗。

- 線寬 0.15mm、間距 0.13mm、過孔 0.6/0.3mm — 都在 JLCPCB 標準製程內（下限 0.127mm）
- 表面處理：HASL（最便宜）或 ENIG
- **天線淨空**：y ≥ 74.5mm 整條無銅、無零件、無過孔，模組天線端懸在這一區

## 7. 施工順序

1. 建 KiCad 專案 → 設定圖框、標題
2. 畫原理圖：先電源區 → USB → MCU → 相機 → SD → 按鍵 LED
3. 跑 ERC，清乾淨所有錯誤
4. 指定每顆零件的 footprint
5. Update PCB from Schematic
6. 排版 → 定外形 → 走線 → 鋪銅
7. DRC（用 JLCPCB 規格）
8. 3D 檢視確認零件不打架
9. 輸出 Gerber + Drill + BOM + CPL(Pick&Place)
10. 上傳 JLCPCB 預覽確認

## 8. 韌體端

用 Arduino IDE 的 `esp32` 套件 + 內建 `ESP32 Camera` 範例（CameraWebServer），
或 ESP-IDF 的 `esp32-camera` component。設定時 board 選 **ESP32S3 Dev Module**，
並開啟 **PSRAM: OPI PSRAM**（R8 是 octal，選錯成 QSPI 會抓不到）。
把上面的腳位表填進 `camera_config_t` 即可。

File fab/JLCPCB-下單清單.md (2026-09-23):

# JLCPCB PCBA 下單步驟清單 — ESP32-S3 Camera v1.4

v1.4（2026-09-22）：快門 SW3 換成側按式 ALPS SKRTLAE010（C110293，Extended）放到上板邊右段 (50.6, 2.6)，C12 下移 0.8 mm；SMD 仍 58 顆，CPL 只有這兩行不同。
v1.3（2026-09-21 晚）：J5、J6 兩條 1×4 排針拆掉，換成一個 1×7 母座 J5（C225482）讓 1.3 吋螢幕直插。SMD 58 顆與 v1.2 完全相同，CPL 相同；插件只剩 J4、J5 兩顆。
v1.2（同日白天）新增電源滑動開關 SW4、EN 上拉 R21、藍色電源燈 D5 與限流 R20，並補了 J2.23、C3.2 兩顆 GND 過孔；v1.2 未下單。

日期：2026-09-21。對應檔案都在 `fab/`。

---

## 0. 上傳前（KiCad 內，約 10 分鐘）

- [ ] 開啟專案，Schematic → Tools → Update Symbols from Library，清掉 U5/U6 的兩個符號庫警告
- [ ] Tools → Update PCB from Schematic，確認 0 差異（2026-09-22 以 kicad-cli 驗過為 0）
- [ ] pcbnew 跑 DRC，確認 0 錯誤、0 未連接（2026-09-22 為 0/0/0；若出現任何 unconnected，不要當敷銅碎片忽略，見 DESIGN.md 第 3 節）
- [ ] **若上面任何一步改到板子**，重新輸出 Gerber、鑽孔、CPL 並重新打包 zip；沒改就直接用現有的 `fab/` 檔案
- [ ] 確認三個要上傳的檔案存在：
  - `fab/esp32s3-camera-gerber.zip`
  - `fab/esp32s3-camera-bom.csv`（含 LCSC Part # 欄）
  - `fab/esp32s3-camera-cpl.csv`

---

## 1. 上傳 Gerber，設定 PCB 規格

前往 jlcpcb.com → Order Now → Add Gerber File，上傳 `esp32s3-camera-gerber.zip`。

檢查預覽：
- [ ] 層數自動辨識為 **4 層**
- [ ] 尺寸約 **60 × 85 mm**
- [ ] 外形正確，四個 M2 孔都在，底部天線淨空區沒有銅

PCB 選項：

| 欄位 | 選擇 | 說明 |
|---|---|---|
| Layers | 4 | |
| Dimensions | 60 × 85 mm | 自動帶入 |
| PCB Qty | 5 | 最少 5 片；PCBA 可只組其中 2 片 |
| PCB Thickness | 1.6 mm | |
| PCB Color | 隨意 | 綠色最快 |
| Surface Finish | **ENIG** 建議 | J2 是 0.5 mm 腳距，ENIG 較平整；預算緊可選 HASL(Lead-free) |
| Outer Copper Weight | 1 oz | |
| Inner Copper Weight | 0.5 oz | 預設即可 |
| Via Covering | Tented | |
| Min via hole size | 0.3 mm | 板子用 0.6/0.3 |
| Remove Order Number | Yes 或 Specify a location | 不想板上有流水號就選 Yes（加價） |
| Impedance Control | No | DVP 不需要 |
| Confirm Production File | Yes | 讓工程師先給你看確認稿，多等 1 天但保險 |

---

## 2. 開啟 PCB Assembly

- [ ] PCB Assembly 切到 **開**
- [ ] PCBA Type：
  - **Standard**：連 J4（JST 座）、J5（1×7 母座）兩顆插件一起焊，較貴但收到就能插螢幕
  - **Economic**：只焊 SMD，J4、J5 兩顆插件要自己手焊，較便宜
- [ ] Assembly Side：**Both sides**（這片板上下兩面都有 SMD）
  - 若 Economic 不給選雙面，改 Standard
- [ ] PCBA Qty：2（最少），或 5 全組
- [ ] Edge Rails / Fiducials：Added by JLCPCB
- [ ] Confirm Parts Placement：**Yes**（步驟 5 會用到）
- [ ] 按 Confirm，進到 BOM/CPL 上傳頁

---

## 3. 上傳 BOM 與 CPL

- [ ] BOM 上傳 `esp32s3-camera-bom.csv`
- [ ] CPL 上傳 `esp32s3-camera-cpl.csv`
- [ ] 欄位對應（系統通常會自動抓，手動確認一次）：
  - BOM：Designator → Designator；Comment → Comment；Footprint → Footprint；LCSC Part # → JLCPCB Part #
  - CPL：Ref → Designator；PosX/PosY → Mid X/Mid Y；Rot → Rotation；Side → Layer

---

## 4. 料號配對頁（Bill of Materials）

逐行檢查 35 行，每行都要有料號、有庫存：

- [ ] 所有電阻、電容、LED 顯示 **Basic**（不收上料費）
- [ ] 以下 Extended 零件都有貨：U2、U3、U4、U5、U6、Q1、Q2、J1、J2、J3、SW1–2、SW3（C110293 ALPS SKRTLAE010 側按式，缺貨不要換成頂按式，可換同尺寸 4.5 × 3.55 側按品並確認封裝）、SW4；Standard 方案再看 J4 C131337、J5 C225482（1×7 母座，若缺貨換任何 2.54 mm 1×7 立式母座，8.5 mm 高）
- [ ] D3 配對到 **C8598（B5819W，SOD-123）**，不要讓系統改成 SS14，那是 SMA 封裝，焊盤不合
- [ ] **U1 ESP32-S3-WROOM-1-N16R8（C2913202）**：
  - 有貨 → 直接用
  - 顯示 Pre-order / 缺貨 → 選 Global Sourcing 代購，或改買 DigiKey 台灣模組寄給 JLCPCB（Consigned）
  - 絕對不要被系統換成 N8 或 N16 無 R 的版本
- [ ] 若選 **Economic**：把 J4、J5 兩行取消勾選（Do not place），之後自己焊
- [ ] 沒有任何一行是紅色「No part selected」

---

## 5. 零件擺放預覽（Component Placements）

KiCad 輸出的旋轉角度與 JLCPCB 的零件方向定義不一定一致，這一步最重要。有極性或方向的零件逐一看：

- [ ] **U1 模組**：天線端朝板子底邊（懸在天線淨空區那一側），腳位排列與板上焊盤對齊
- [ ] **J1 USB-C**：開口朝板邊外側
- [ ] **J2 FPC 座**：掀蓋朝板邊外側（頂邊），pin 1 位置對
- [ ] **J3 microSD**：卡片插入口朝板邊外側
- [ ] **J5 1×7 母座**（Standard 才有）：在底面右板邊，方形 pin 1 焊盤在靠天線那一端（y 大）
- [ ] **SW3 側按快門**：在上板邊右段，觸桿朝板邊外側（−y），兩個定位柱落在 Ø0.9 定位孔
- [ ] **U2、U4、U5、U6（SOT-23 系列）、U3（TP4056）**：pin 1 點與絲印一致
- [ ] **Q1、Q2 MOSFET**：三腳方向對
- [ ] **D3 SS14**：陰極線與絲印一致
- [ ] **D1、D2、D4、D5 LED**：陰極方向對（頂層 D1/D4/D5，底層 D2）
- [ ] **SW4 滑動開關**：撥桿朝右板邊外側，pad 3（GND）靠板子上緣
- [ ] **SW1–3**：方向不影響，略過
- [ ] 電阻、電容：無極性，略過

方向不對的在預覽頁直接旋轉修正，改完不用重傳 CPL。

---

## 6. 結帳前

- [ ] 報價明細：PCB 費、上料費（約 15 種 Extended × 一次費用）、零件費、組裝費、運費
- [ ] 運送到台灣：選 DHL 或 FedEx（3–5 天）較穩，郵政便宜但慢
- [ ] 貨物申報價值選 Low 或 Actual 皆可，超過 NT$2000 會課稅
- [ ] 儲存到購物車 → 付款
- [ ] 若步驟 1 選了 Confirm Production File，1–2 天內回信站確認工程師的檔案，不回覆會卡住

---

## 7. 同時另外採購（板外零件）

| 品項 | 規格 | 備註 |
|---|---|---|
| 相機模組 | OV2640，24pin 0.5 mm 排線，ESP32-CAM 相容 | 多買一條排線備用 |
| 鋰電池 | 3.7V 單芯、JST PH 2.0 插頭、帶保護板，尺寸 603040（30×40×6 mm）或更小 | 收到先量極性；貼在底面中央 (34,44)，墊 2 mm 雙面泡棉膠，保護板端朝下緣 |
| microSD 卡 | 8–32GB | |
| USB-C 線 | 能傳資料的 | |
| M2 螺絲、銅柱 | 4 組 | |
| 預覽螢幕 | 通用型 1.3 吋 IPS 240×240 ST7789，**7 pin 2.54 mm 直排針已焊**（GMT130 / ZJY133T，27.78 × 39.22 mm） | 用七條公–母杜邦線接底面 J5 母座（2026-09-23 起；也可直插）；腳序見 DESIGN.md 2d。Waveshare 版腳序不同，要用它附的線 |
| （Economic 才要）JST PH 2P 立式座 | 對應 J4，C131337 | |
| （Economic 才要）2.54 mm 1×7 立式母座 | 1 個，對應 J5，C225482 或任何 8.5 mm 高的同規格品 | |

---

## 8. 收到板子後的第一次上電

先**不要**插相機與電池。

- [ ] 目視：U1 天線端有沒有懸出淨空區、J2 掀蓋能開、有沒有明顯空焊、SW4 撥桿在右板邊能撥動
- [ ] 接 USB-C 後先撥 SW4：撥向絲印「ON」（往模組方向）藍燈 D5 亮，撥向「OFF」（往板子上緣）全熄。若方向與絲印相反，代表相容品機構相反，記下即可。關機狀態下 D2 紅燈仍應顯示充電
- [ ] 量電源對地阻抗：VBUS、+3V3、+2V8、+1V2 對 GND 不能短路
- [ ] 接 USB-C，量 +3V3 ≈ 3.3V、+2V8 ≈ 2.8V、+1V2 ≈ 1.2V
- [ ] 插螢幕前：母座 pin 1（方形焊盤、靠天線端）對地 0 Ω、pin 2 對地 3.3V；再把模組絲印的 GND 對到 pin 1 那一格才插
- [ ] 電腦裝置管理員看到 ESP32-S3 USB 裝置（或按住 BOOT 再插看到下載模式）
- [ ] 燒一個 blink 測 D1 綠燈
- [ ] 插 microSD：從左板邊（USB-C 的對面）插入 J3，金手指面朝電路板、標籤朝外，推到「喀」一聲；再推一下會退出
- [ ] 以上都過，斷電、插相機排線（接觸面朝下、確認 pin 1），排線往板邊出來約 2.5 mm 就反折 180° 蓋回 J2，模組貼在按鍵欄與 U4 之間的空區（鏡頭中心約 x30, y25 mm），底下墊 8×8 mm 雙面泡棉膠，再上電跑 CameraWebServer 範例
- [ ] 最後才接電池：J4 有 L 形絲印記號那一側是 pin 1 = 正極（底面朝自己、天線朝下時在左邊）。先量電池插頭紅線是否對到 pin 1，不對就把端子對調，再插上，確認 D2 充電紅燈亮

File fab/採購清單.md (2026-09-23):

# ESP32-S3 Camera v1.4 — 最終採購清單（2026-09-22）

連結與價格為查詢當日所見，下單前請再確認庫存與規格。

---

## A. 板子與板上零件：JLCPCB PCBA 一次搞定

上傳 `fab/esp32s3-camera-gerber.zip`、`fab/esp32s3-camera-bom.csv`、`fab/esp32s3-camera-cpl.csv`，步驟見 `fab/JLCPCB-下單清單.md`。
BOM 已含 LCSC 料號，58 顆 SMD 由 JLCPCB 貼好，**不用自己買**。

| 項目 | 規格 | 備註 |
|---|---|---|
| PCB | 60 × 85 mm、4 層、1.6 mm、1 oz、ENIG 建議 | 最少 5 片 |
| PCBA | Standard（含插件）或 Economic（只焊 SMD） | 雙面貼片，最少 2 片 |
| 需注意的料號 | U1 C2913202（N16R8 模組，可能預購）、D3 C8598（SOD-123，不是 SS14）、SW4 C431540、SW3 C110293（ALPS SKRTLAE010 側按快門） | 配對頁逐行看 |

**選 Economic 方案時要自己買並手焊的兩顆插件**

| 零件 | 料號 / 連結 | 備註 |
|---|---|---|
| J4 JST PH 2.0 mm 2P 立式座 | [LCSC C131337](https://www.lcsc.com/product-detail/Wire-To-Board-Connector_JST-B2B-PH-K-S-LF-SN_C131337.html) | 電池座 |
| J5 2.54 mm 1×7 立式母座（8.5 mm 高） | [LCSC C225482 CJT A2541WV-7P](https://www.lcsc.com/product-detail/C225482.html)，或 ICShop／蝦皮任何「單排母座 2.54 1×7」（買 1×40 剪也行） | 螢幕直插用；不要買 90° 或矮款，高度會變 |

---

## B. 板外零件：一律自己買

| # | 品項 | 規格 | 連結 | 備註 |
|---|---|---|---|---|
| 1 | OV2640 相機模組 | 24 pin 0.5 mm 排線、ESP32-CAM 相容、排線約 21 mm | [ICShop OV2640 攝影鏡頭 75°](https://www.icshop.com.tw/products/368030501479) NT$110；[AliExpress 多焦距／夜視版](https://www.aliexpress.us/item/3256802773370193.html) | 排線易折，多買一條備用。下單前確認是 24P 0.5 mm、ESP32-CAM 用 |
| 2 | 鋰電池 | 3.7V 單芯、**603040 或 503040（600 mAh）**、帶保護板、JST PH 2.0 插頭 | [勝特力 503040 600mAh](https://www.100y.com.tw/product/158757)；[詠豐電子 503040](https://www.yfe2019.com.tw/products/3.7V600mA%E8%81%9A%E5%90%88%E7%89%A9%E9%8B%B0%E9%9B%BB%E6%B1%A0503040-5e8561f5986e57d2.html)；[ICShop 150mAh（小容量）](https://www.icshop.com.tw/products/368090500104)；[ICShop 2400mAh（103450 等級，較厚）](https://www.icshop.com.tw/products/368090500165) | 收到先量極性：J4 pin 1 = 正極。換小電池要改 R3 |
| 3 | 預覽螢幕 | 通用型 1.3 吋 IPS 240×240 ST7789，**7 pin 2.54 mm 直排針已焊**，27.78 × 39.22 mm，用杜邦線接 J5 | [AliExpress 1.3" IPS ST7789 3.3V SPI](https://www.aliexpress.us/item/2255800033232649.html)；[AliExpress 另一賣家](https://www.aliexpress.us/item/2251832694355820.html)；蝦皮搜「1.3吋 IPS 240x240 ST7789 7pin」約 NT$150–220 | 替代：[ICShop Waveshare 1.3inch LCD Module NT$225](https://www.icshop.com.tw/products/368031700013)，板子較大、腳序不同，要用它附的線接，外殼孔位也要改 |
| 4 | 杜邦線 | **公–母**、10 cm、7 條（買一排 40P 撕 7 條） | 任何電子材料行／蝦皮 | 公頭插 J5 母座、母頭套螢幕排針，腳序一對一；外殼已照 14 mm 膠殼留深度（2026-09-23 改回用線，省事不焊） |
| 5 | microSD 卡 | 8–32 GB，Class 10 | 任何通路 | 金手指朝板子插入 J3 |
| 6 | USB-C 線 | 要能傳資料 | 任何通路 | 燒錄與充電 |
| 7 | M2 螺絲 | M2 × 35 盤頭 4 支（外殼，從背面鎖穿）＋ M2 × 4 盤頭 4 支（螢幕鎖在後殼矮柱上） | ICShop／蝦皮 | 外殼加深後 M2×25 不夠長 |
| 8 | 雙面泡棉膠 | 約 2 mm 厚 | 五金行 | 相機模組底下 8 × 8 mm 一塊；電池底下 26 × 36 mm 一塊 |
| 9 | 外殼 | 3D 列印，見 `../enclosure/` | — | 開孔：鏡頭 (30, 25) 頂面、快門上板邊 x 47.6–53.6、BOOT/RESET 針孔、開關右板邊 y 8–14、USB-C 右板邊 y 19.5–28.5、記憶卡左板邊 y 36–52、螢幕窗 23.4 × 23.4 中心 (28.4, 45) 底面；底側內深 27 mm（杜邦公頭膠殼 22.5 + 線彎 3.5 + 1；螢幕亮面離板底 26.4 mm）、前殼內高 8 mm。STEP：`esp32s3-camera.step` |

**只想先點亮板子的最小採購**：第 1、2、5、6 項，加上 Economic 方案時的 J4。

---

## C. 若 JLCPCB 的 ESP32-S3 模組缺貨

| 品項 | 連結 |
|---|---|
| ESP32-S3-WROOM-1-N16R8 | [DigiKey 台灣](https://www.digikey.tw/zh/products/detail/espressif-systems/ESP32-S3-WROOM-1-N16R8/16162642)（滿 NT$1400 免運） |
| 同上 | [ICShop ESP32-S3-WROOM 模組](https://www.icshop.com.tw/products/368030501809)（確認是 N16R8） |

買回來用 JLCPCB 的 Consigned parts 寄給他們，或自己回焊。

---

## D. 對照：板上連接器實物照（不用買，JLCPCB 會貼）

- [J2 Hirose FH12-24S-0.5SH 掀蓋 FPC 座](https://www.lcsc.com/product-detail/C202112.html)
- [J3 Hirose DM3AT microSD 座](https://lcsc.com/product-detail/C114218.html)
- [J1 HCTL 16P USB-C 座](https://www.lcsc.com/product-detail/C2894897.html)
- [SW4 SHOU HAN MSK12C02 滑動開關](https://www.lcsc.com/product-detail/C431540.html)
- [D5 KENTO KT-0603B 藍色 LED](https://www.lcsc.com/product-detail/Light-Emitting-Diodes-LED_Hubei-KENTO-Elec-KT-0603B_C2288.html)

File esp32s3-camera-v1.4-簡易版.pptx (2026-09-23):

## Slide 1

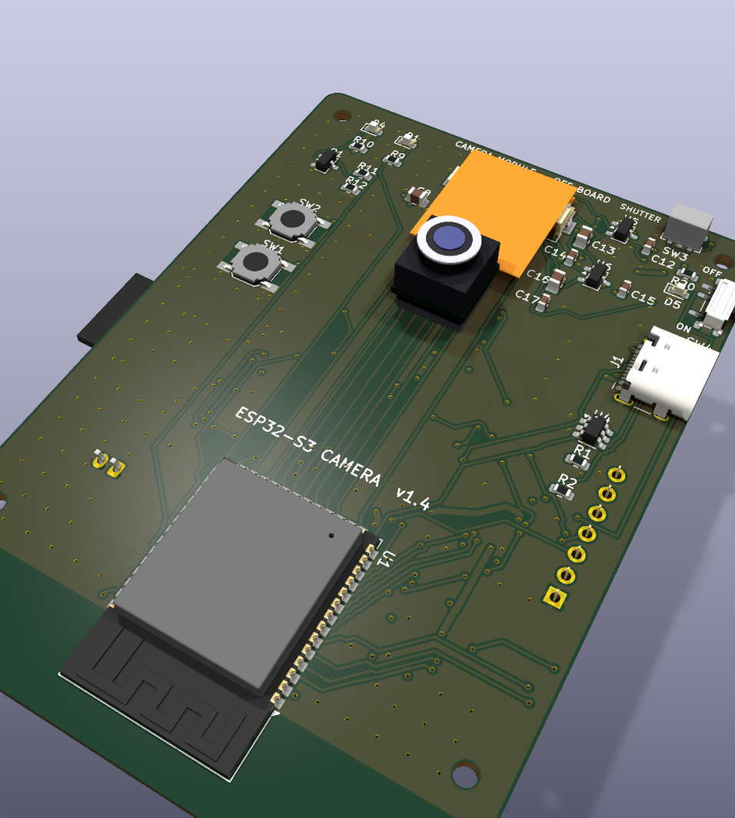
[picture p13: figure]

一塊自己設計的
小相機板

手掌大小、可以裝電池、拍完存進記憶卡，還有一個 3D 列印的相機外殼。這份簡報用最少的專業名詞，說明它是什麼、要買什麼、怎麼組起來。

第 1.4 版 · 2026 年 9 月

ESP32-S3 相機板 · 簡易說明

1

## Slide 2

它能做什麼

1

拍照

板上插一顆小鏡頭，按一下頂邊的快門就拍。

2

存進記憶卡

照片存在 microSD 卡裡，拔下來就能在電腦上看。

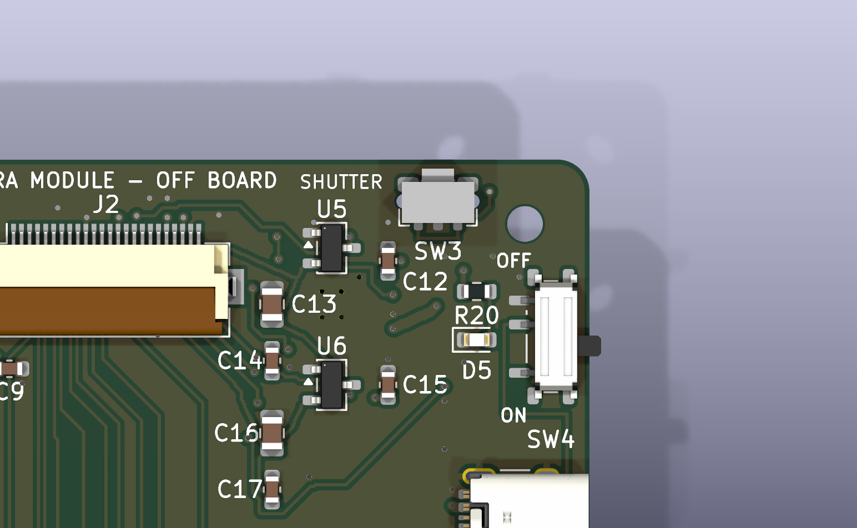
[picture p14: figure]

板子右上角：頂邊那顆是快門，旁邊是電源開關和藍色電源燈，下面是 USB-C 充電孔。

3

用電池跑

裝一顆手機那種鋰電池，插 USB 就能充電。

4

有開關和指示燈

撥開關開機，藍燈亮表示有電；充電時紅燈亮。

5

有小螢幕

背面有一片 1.3 吋螢幕，用七條現成的線接到板子，拍之前先看畫面。

6

Wi-Fi

板上的晶片本身有 Wi-Fi，照片也能傳到手機或電腦。

ESP32-S3 相機板 · 簡易說明

2

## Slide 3

正面長這樣

鏡頭朝這一面。快門在板子頂邊，四個角有螺絲孔鎖進外殼。

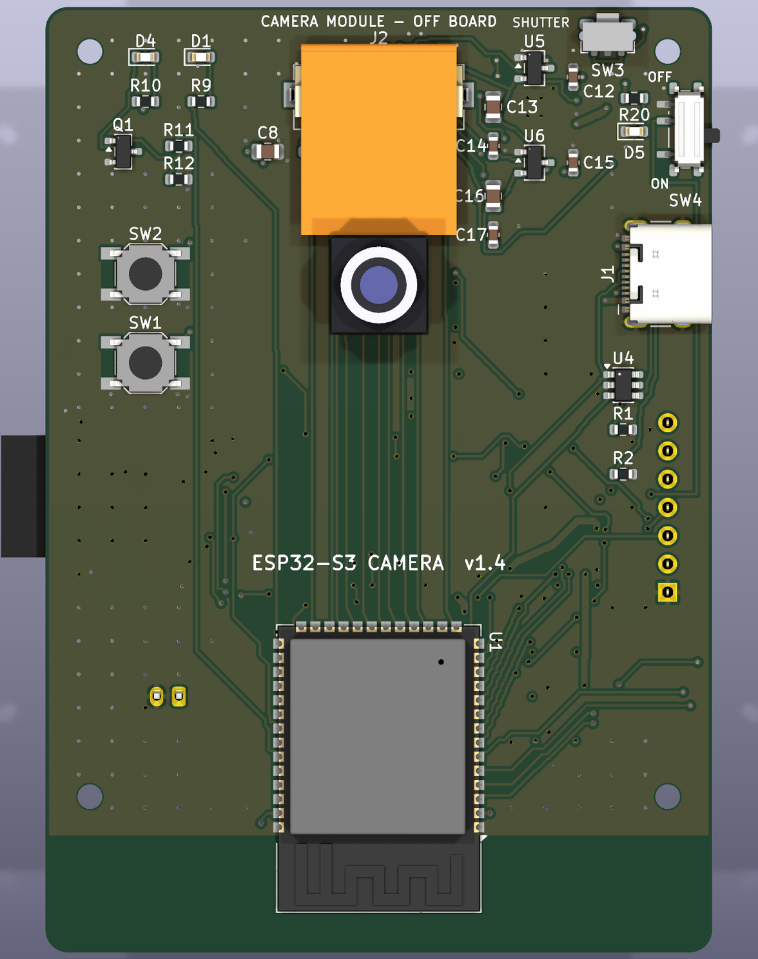
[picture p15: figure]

鏡頭

小小一顆黑色方塊，跟手機鏡頭差不多大。用一條軟排線接到板子，可以翻折貼平。

快門

板子頂邊右側一顆側面按的小開關，裝進外殼後從頂邊按，就像真的相機。

兩顆小鍵

這兩顆是開發用的，平常不用碰；快門不在這裡。

電源開關

右邊板邊的小撥桿，往上撥關機、往下撥開機，板上印了 ON / OFF。

主晶片

銀色方塊是整塊板子的大腦，內建 Wi-Fi，底下黑色區域是天線，不能被金屬遮住。

USB-C 孔

跟現在的手機一樣的接頭，用來充電和把程式燒進去。

ESP32-S3 相機板 · 簡易說明

3

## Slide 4

背面長這樣

電池貼在背面中間，螢幕用七條杜邦線接到右邊的插座、鎖在殼上，蓋在電池上方。這一面是使用的時候朝著自己的那一面。

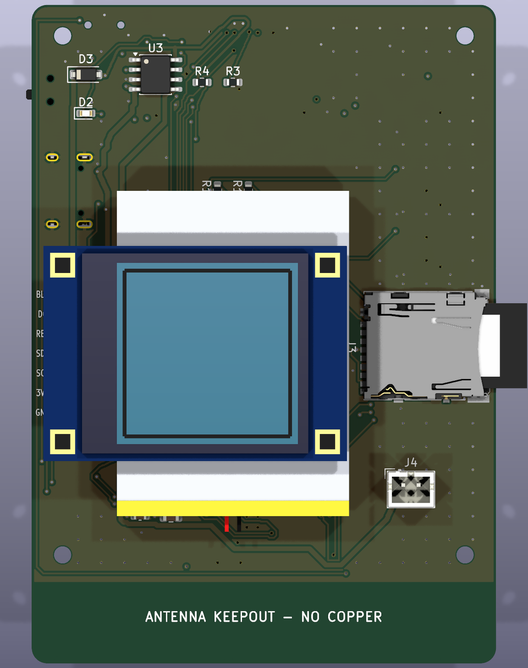
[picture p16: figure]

小螢幕

1.3 吋正方形螢幕，用七條現成的杜邦線接到板子右邊那排插座，不用焊。

記憶卡

microSD 卡從左邊板邊插進去，推到「喀」一聲。再推一下會退出。

電池

白色長方形是鋰電池，黃色那端是保護板。用雙面泡棉膠貼住。

充電晶片

上面左邊那一排小零件負責幫電池充電，充電中會微溫是正常的。

電池插座

小小的白色兩腳插座，電池線插這裡。插之前要先確認正負極。

天線區

最下面深色那一條下面是 Wi-Fi 天線，外殼這裡不要用金屬。

ESP32-S3 相機板 · 簡易說明

4

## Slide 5

工廠做一半，我們做一半

工廠負責

- 把設計圖做成 4 層的電路板
- 把 58 顆小零件焊上去（最小的比米粒還小，人手焊不了）
- 焊好寄回來，收到就是一塊完整的板子
- 選「含插件」方案的話，電池插座和螢幕插座也會一起焊好

工廠：JLCPCB，中國深圳的線上電路板廠，上傳檔案線上下單。

ESP32-S3 相機板 · 簡易說明

我們自己負責

- 另外買鏡頭、螢幕、杜邦線、電池、記憶卡、USB 線
- 把鏡頭的排線插上、螢幕用杜邦線接上、電池貼上、記憶卡插入
- 把程式燒進板子
- 3D 列印外殼三件（設計圖已經畫好），鎖螺絲
- 想改東西可以再改，所有檔案都在專案裡

全部不需要焊接，除非選了「只焊小零件」的便宜方案，那兩顆插座要自己焊。

5

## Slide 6

要另外買的東西

板子本身不含這些。前五項是必要的，最後一項是外殼相關。

鏡頭模組

OV2640，跟 ESP32-CAM 用的同一種。排線很脆弱，多買一條備用。

約 NT$110

鋰電池

3.7V、約 600 mAh、帶保護板、白色小插頭（JST PH 2.0）。

約 NT$100–200

記憶卡

microSD 8–32 GB，一般的就好。

手邊有就用

USB-C 線

要能傳資料的，不能是只能充電的線。

手邊有就用

小螢幕

1.3 吋 IPS 240×240，ST7789，7 針直排針已焊好那種。另外買 7 條公對母的杜邦線接到板子，不用焊。

約 NT$150–220

價格是 2026 年 9 月在台灣網購看到的大約數字。詳細店家連結在專案的採購清單裡。

螺絲、泡棉膠、外殼

M2 × 35 螺絲 4 支（殼）、M2 × 4 螺絲 4 支（螢幕）、2 mm 厚雙面泡棉膠、3D 列印外殼三件（前殼、後殼、快門帽）。

外殼自己印

ESP32-S3 相機板 · 簡易說明

6

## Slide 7

組裝只有三步

插鏡頭

排線金屬面朝下插進板子上緣的黑色小座，出來一點就往回折 180°，讓鏡頭躺回板面。底下墊一小塊泡棉膠。

ESP32-S3 相機板 · 簡易說明

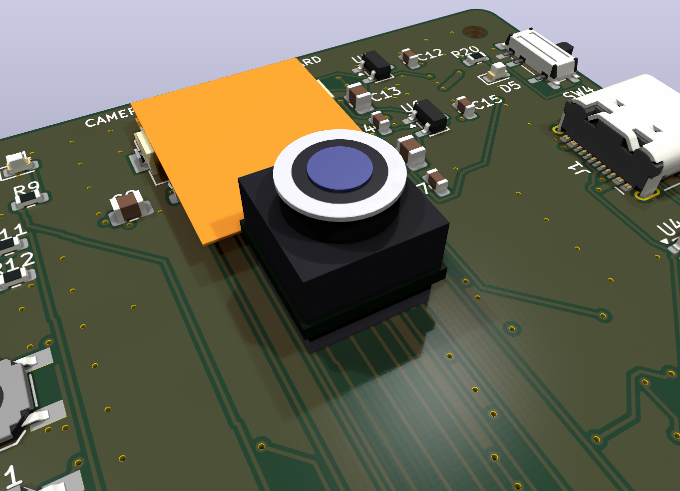
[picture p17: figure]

貼電池、接螢幕、插記憶卡

電池用泡棉膠貼在背面中間，插頭插進白色小座，插之前先確認紅線對到有 L 形記號那一邊。螢幕用七條杜邦線接到右邊那排插座，同名對同名（GND 對 GND）。記憶卡從左邊推進去。

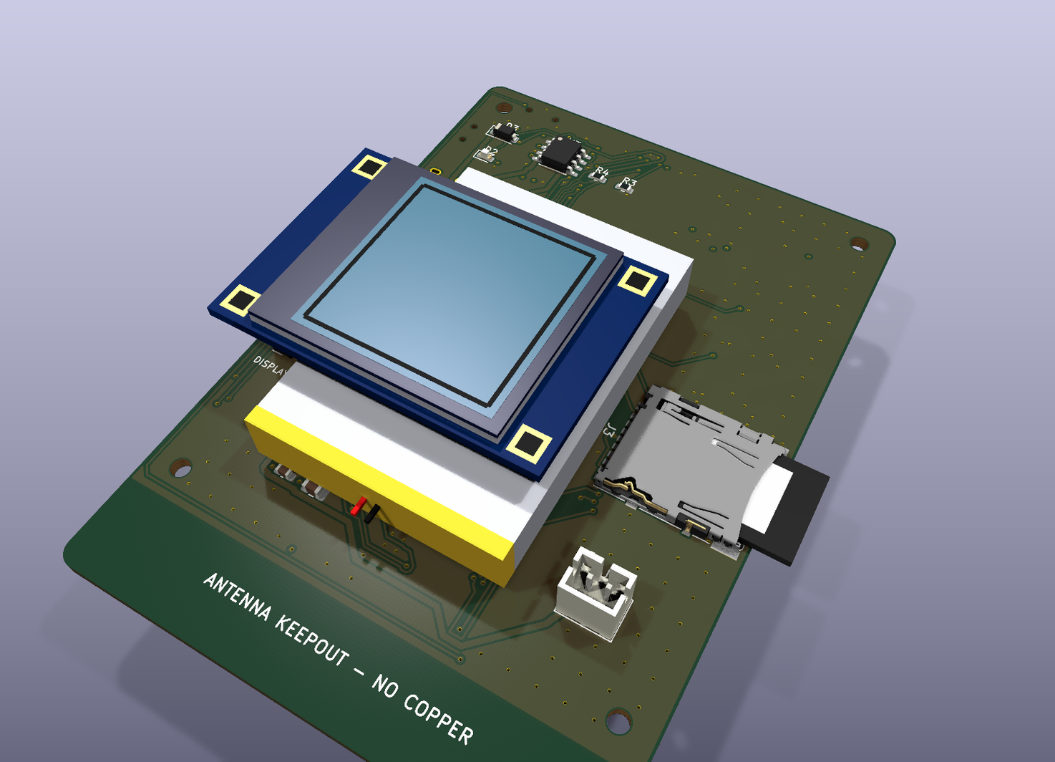
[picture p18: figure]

插 USB、撥開關

接上 USB-C 線，把開關往下撥，藍燈亮就是開機了。第一次先不要接電池，確認燈會亮再說。都好了再裝進外殼、鎖四支螺絲。

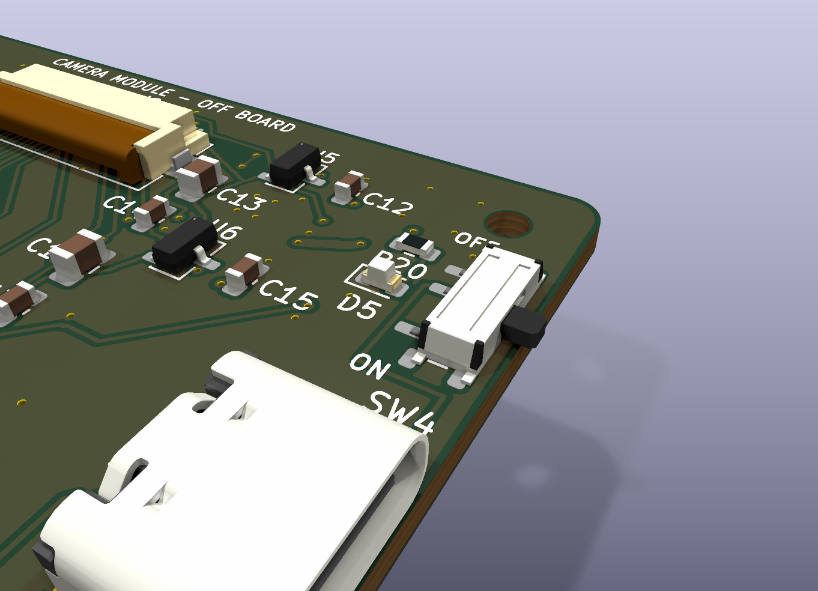
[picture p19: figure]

1

2

3

7

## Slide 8

三件要注意的事

電池正負極

電池插頭的紅黑線沒有統一規範，插之前一定要對一下：紅線要對到板上有 L 形記號的那一腳。插反會燒壞。

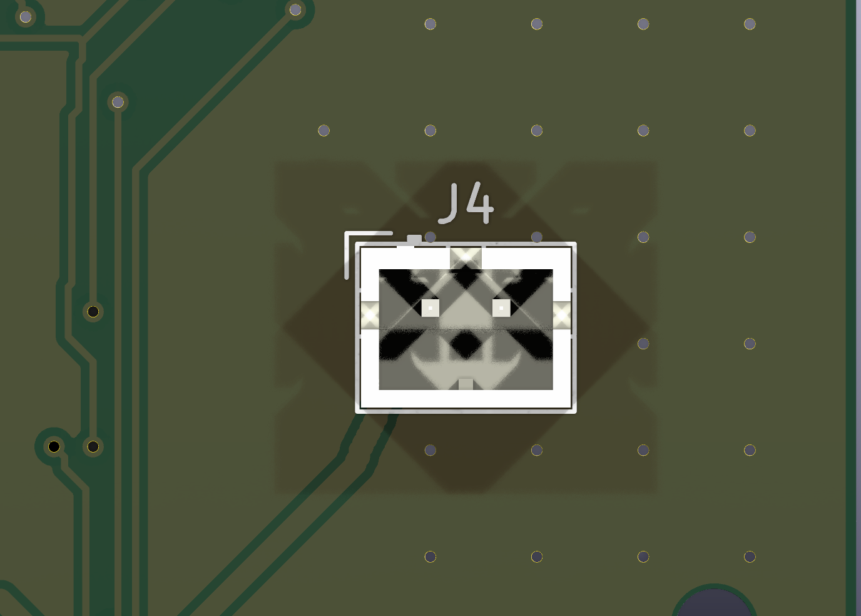
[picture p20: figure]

排線很脆弱

鏡頭那條軟排線折幾次就會斷，只在需要的地方折一次，其他時間不要拉扯。多買一條備用。

電池插座的特寫。左上角有 L 形白色印記的那一腳是正極，紅線要對到這裡。

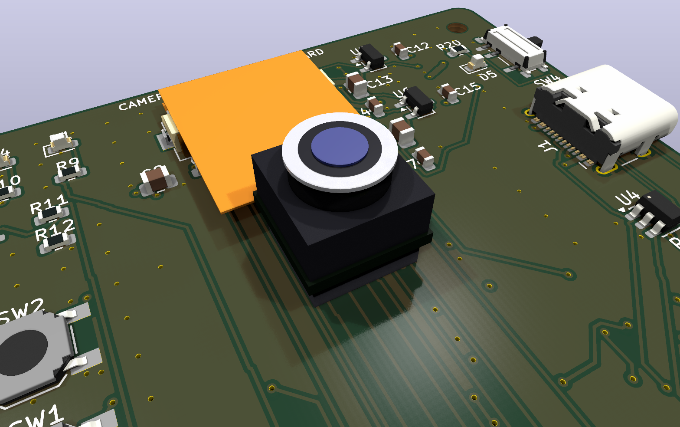
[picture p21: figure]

天線那一區不要壓金屬

板子最下面深色那一條是 Wi-Fi 天線。外殼那一段用塑膠，電池不要貼到那裡，不然訊號會變差。

ESP32-S3 相機板 · 簡易說明

8

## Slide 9

外殼長這樣

兩片殼夾住板子，鏡頭在正面、螢幕在背面、快門在頂邊，像一台小相機。用 3D 列印機印出來就好。

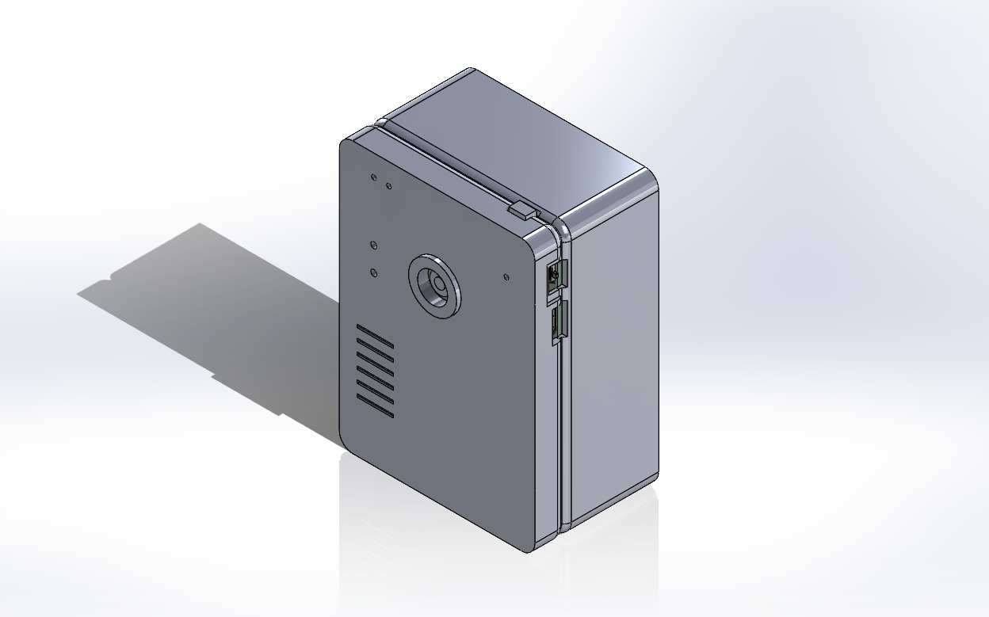
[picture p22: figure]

合起來：頂邊那顆就是快門

拆開看：前殼、板子、後殼

前殼、後殼、快門帽，塑膠印的，四支小螺絲從背面鎖起來。

三件

正面鏡頭孔和兩個針孔，頂邊快門，右邊開關和充電孔，左邊記憶卡口，背面螢幕窗。

看得到的孔

65 × 90 × 40 mm，差不多一張名片的長寬、四根手指的厚度。厚是因為螢幕用杜邦線接，線頭要有地方放。

尺寸

ESP32-S3 相機板 · 簡易說明

9

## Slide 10

裝進殼裡長這樣

把鏡頭、排線、電池、記憶卡、螢幕和接螢幕的杜邦線都放進電腦模型裡試裝過，什麼都沒有卡到。這兩張是把殼拿掉一半看裡面。

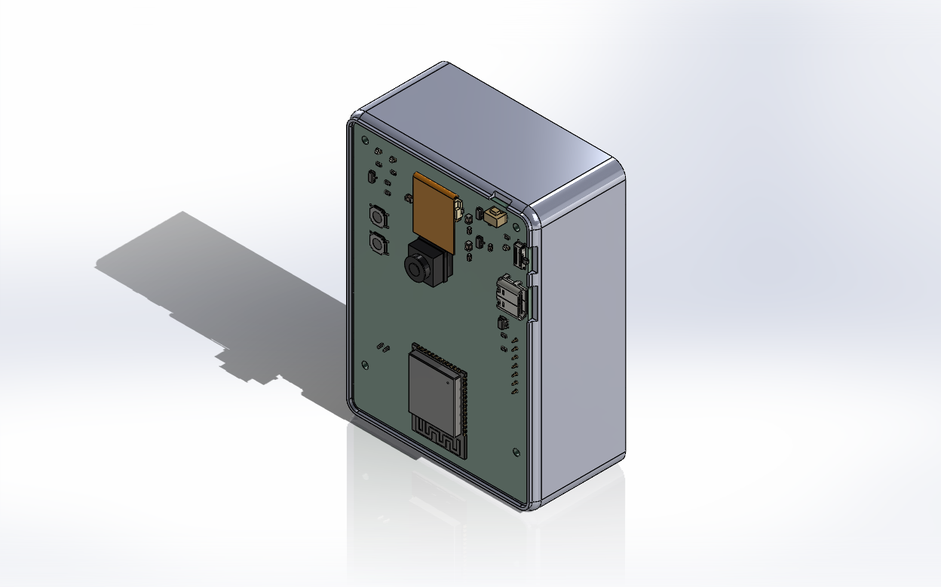
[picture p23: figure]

正面那片殼拿掉：橘色排線從座子出來反折、貼回板子接到鏡頭

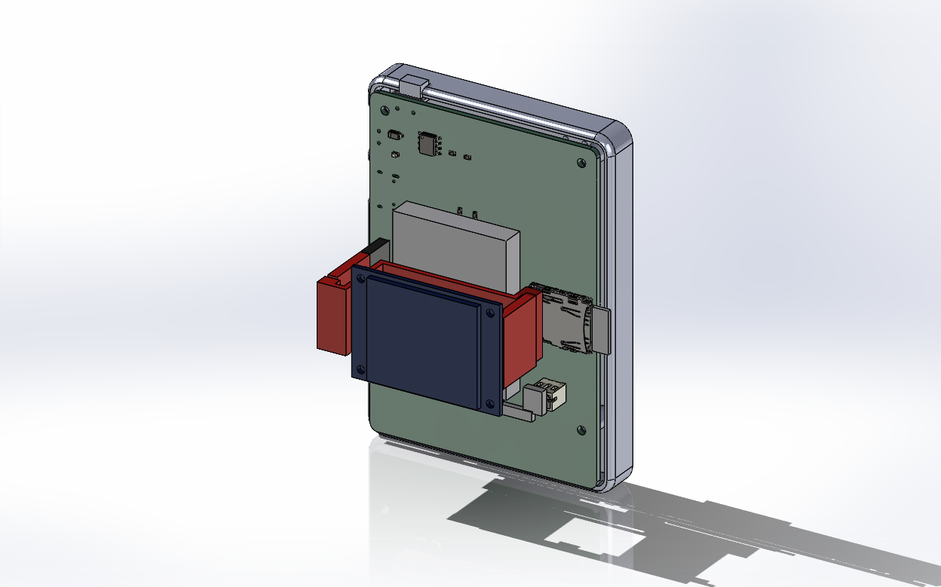
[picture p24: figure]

背面那片殼拿掉：紅色是接螢幕的杜邦線，螢幕鎖在殼上、蓋在電池上面

排線從板子上緣的座子出來折回來，鏡頭貼在板面上，離殼頂還有一點空間。

鏡頭

螢幕用七條杜邦線接到板子右邊的插座、鎖在殼上；電池夾在板子和螢幕之間，線也走那裡。

螢幕和電池

卡插到底還會露出一小段，剛好穿過殼側面的口，用指甲就能拔。

記憶卡

ESP32-S3 相機板 · 簡易說明

10

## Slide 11

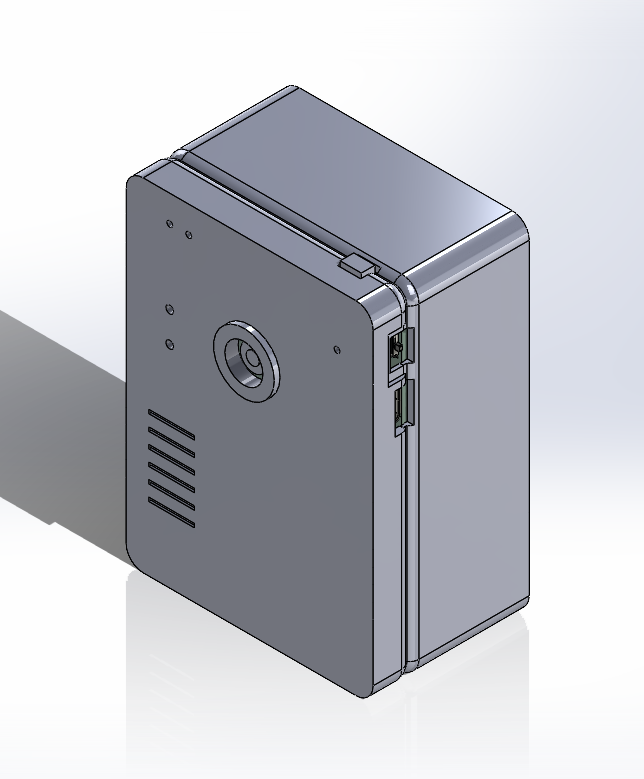
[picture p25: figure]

接下來會發生什麼

下單

把檔案上傳給工廠，選好數量與方案。約 1–2 天內工廠回信確認。

1

2

等貨

製作加運送大約兩到三週。這段時間把鏡頭、螢幕、電池、記憶卡買齊，外殼三件印出來。

3

組裝

照前面三步組起來，接 USB 看藍燈亮，再裝進外殼。

4

拍第一張照片

燒入程式，用手機連上板子的 Wi-Fi 看畫面，按快門。

ESP32-S3 相機板 · 簡易說明

11

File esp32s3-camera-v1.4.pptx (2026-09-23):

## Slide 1

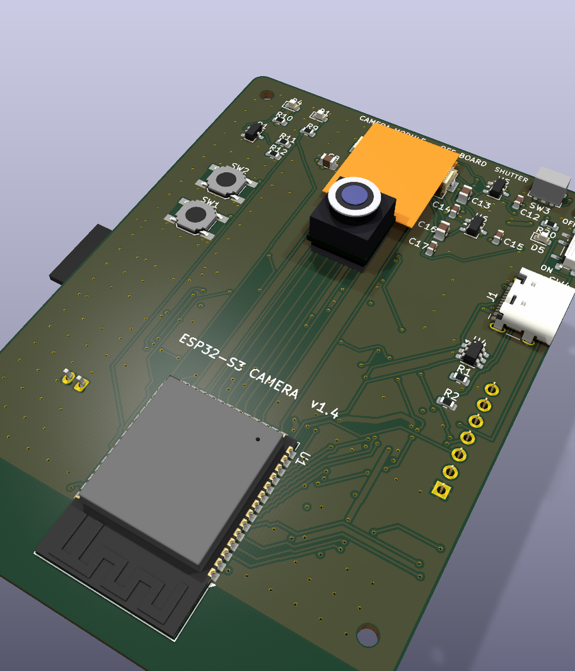
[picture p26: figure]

ESP32-S3 CAMERA · V1.4 · 60 × 85 MM · 4 層 · 含 3D 列印外殼

哪些零件 JLCPCB
幫你焊好，
哪些要自己買

零件分工圖、組裝示意、3D 渲染、外殼與採購清單。依實際 PCB 座標整理，對應 2026-09-22 定稿的電路板 v1.4。

JLCPCB 貼好（SMD）

插件兩顆

板外零件，自己買

ESP32-S3 Camera · v1.4 · 60 × 85 mm · 4 層 · 2026-09-23

1

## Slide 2

本頁對應電路板 v1.4

2026-09-22 定稿，快照存在專案 versions/v1.4/，含 Gerber、BOM、CPL、ERC/DRC 報告，視為唯讀。v1.2、v1.3 都沒有下單。

v1.0

最初佈局

- 60 × 85 mm 四層板
- ESP32-S3-WROOM-1 模組
- OV2640 相機、microSD、鋰電池充電

v1.1

相機腳位標準化

- 相機腳位改為 ESP32-CAM 標準
- 加相機專用 2.8V / 1.2V LDO
- BOM 填入 LCSC 料號

v1.2

電源開關與電源燈

- 加電源滑動開關 SW4
- 加 EN 上拉 R21
- 加藍色電源燈 D5 與限流 R20
- 絲印標 ON / OFF

v1.3

螢幕母座

- J5、J6 兩條排針換成 1×7 母座 J5
- 1.3 吋 ST7789 螢幕直插（09-23 改為杜邦線接）
- SCL = GPIO44、SDA = GPIO43
- 為 3D 列印外殼而改

v1.4

側按快門

- 快門 SW3 換成側按式 ALPS SKRTLAE010
- 移到上板邊右段 (50.6, 2.6)
- C12 下移、快門線改繞模組下方
- 外殼上牆做快門帽

v1.3 起板上有螢幕母座、v1.4 起快門在上板邊側按，兩版都是為了相機式 3D 列印外殼（鏡頭正面、螢幕背面、快門頂邊）而改。2026-09-23 螢幕改用七條公–母杜邦線接母座（省事、不焊），後殼因此加深到 27 mm 內深；外殼見第 14–17 頁。

ESP32-S3 Camera · v1.4 · 60 × 85 mm · 4 層 · 2026-09-23

2

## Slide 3

零件分三類：貼好的、插件的、板外的

58 顆 SMD · 32 項

JLCPCB 貼好

上傳 BOM 與 CPL 即可，料號已填在 BOM 內。電阻電容全是 Basic Part，其餘是模組與連接器。

PCBA 方案怎麼選

2 顆插件

Economic 自己焊，Standard 代焊

J4 電池座、J5 1×7 螢幕母座。J4 一定要焊才能接電池，J5 要焊才能插螢幕。

7 項板外零件

一律自己買

相機模組、1.3 吋螢幕與 7 條公–母杜邦線、鋰電池、microSD 卡、USB-C 線、M2×35 與 M2×4 螺絲、3D 列印外殼三件。

| Economic 只焊 SMD | Standard 含插件
JLCPCB 焊什麼 | 58 顆 SMD | 58 顆 SMD + J4、J5 兩顆插件
自己要做什麼 | 買 J4 電池座與 J5 母座回來手焊 | 不用買插件，收到板子接電池、接螢幕

ESP32-S3 Camera · v1.4 · 60 × 85 mm · 4 層 · 2026-09-23

3

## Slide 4

頂面 Top · F.Cu · 30 顆 SMD

依實際 PCB 座標繪製。粉紅色為板外零件的位置示意。

JLCPCB 貼好（SMD）

板外零件，自己買

ANTENNA KEEPOUT

J2

U5

SW3

Q1

U6

SW4

USB-C 線 → J1

燒錄與充電。J1 母座開口朝右板邊，要用能傳資料的線。

OV2640 相機模組 → J2

排線從 J2 出來後反折 180°，模組貼回板面、鏡頭朝上，底下墊 2 mm 泡棉膠。落在按鍵那一欄與 U4 之間的空區，鏡頭中心 (30, 25)。

SW2

J1

SW1

U4

v1.4：SW3 快門移到上板邊

側按式 ALPS SKRTLAE010，觸桿朝上板邊伸出，由外殼上牆的快門帽按。旁邊仍是 SW4 電源開關與 D5 藍燈。左欄只剩 SW1 BOOT、SW2 RESET。

M2 × 35 螺絲 × 4 → H1–H4

四角 Ø2.2 定位孔。外殼的 M2×35 螺絲從背面穿過立柱與板子，鎖進前殼。

U1

3D 列印外殼

相機式兩片殼：鏡頭孔對 (30, 25)，快門帽在上牆，BOOT / RESET 針孔。見第 14、15 頁。

U1 ESP32-S3-WROOM-1-N16R8

模組天線端懸在下方深綠色淨空區，那一帶不放任何零件。

ESP32-S3 Camera · v1.4 · 60 × 85 mm · 4 層 · 2026-09-23

4

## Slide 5

底面 Bottom · B.Cu · 28 顆 SMD + 2 插件

從底面看，已左右鏡像，與 KiCad 3D 檢視及 JLCPCB 預覽的 Bottom 一致。

JLCPCB 貼好（SMD）

插件，Economic 要自己焊（J4、J5）

ANTENNA KEEPOUT

板外零件，自己買

D3

U3

J4 電池座（插件）

JST PH 2.0 mm 2P 立式座。L 形絲印那側是 pin 1（VBAT +），靠板子中央；pin 2 GND 靠板邊。

電源電路在這一角

U3 TP4056 充電、D3 B5819W、U2 3.3V LDO、Q2 MOSFET 與 R21 EN 上拉。

LiPo 603040

J5

Q2

J3

3.7V 鋰電池 → J4

JST PH 2.0 插頭、帶保護板。603040（30 × 40 × 6 mm）墊 2 mm 泡棉貼在底面中央 (34, 44)。收到先量極性，pin 1 = 正極。

U2

microSD 卡 → J3

8–32 GB，金手指朝板子插入，卡槽開口朝這一側的板邊。

J5 螢幕母座（插件）

1×7 2.54 mm 立式母座 C225482。螢幕用七條公–母杜邦線接過來，公頭插這裡；腳序 GND 3V3 SCL SDA RES DC BLK，方形 pin 1 靠天線端。

J4

1.3 吋預覽螢幕 → J5

七條公–母杜邦線接 J5、亮面朝外；模組用 M2×4 鎖在後殼四支矮柱上、蓋在電池上方，背面離板底 23.6 mm，亮面約 26.4 mm。

ESP32-S3 Camera · v1.4 · 60 × 85 mm · 4 層 · 2026-09-23

5

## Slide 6

JLCPCB 貼好：58 顆 SMD · 32 項

上傳 fab/esp32s3-camera-bom.csv 與 CPL 即可，料號已填在 BOM 內

板上零件清單


裸板貼片後的頂面：兩顆按鍵、FPC 座、上板邊的側按快門、ESP32 模組與天線淨空區

右上角特寫：v1.4 的側按快門 SW3 在上板邊，SW4 電源開關、D5 藍燈在旁邊，一起由 JLCPCB 貼好。

- U1 ESP32-S3-WROOM-1-N16R8 模組 C2913202
- U2 AP2112K 3.3V LDO；U5 2.8V、U6 1.2V LDO 供相機
- U3 TP4056 充電；U4 USBLC6 ESD；Q1 Q2 MOSFET
- J1 USB-C 座；J2 24P FPC 座；J3 microSD 座
- SW1 BOOT、SW2 RESET 頂按式；SW3 快門 側按式 ALPS SKRTLAE010 C110293（v1.4）
- SW4 電源滑動開關 C431540；D5 藍色電源燈 C2288
- D1 D2 D4 LED；D3 B5819W C8598
- 21 顆電阻、17 顆電容，全部 Basic Part

配對頁要看的料號：U1 C2913202（N16R8 模組，可能預購）、D3 C8598（SOD-123，不是 SS14）、SW4 C431540、SW3 C110293（側按快門，不要被換成頂按式）。逐行確認有貨。

ESP32-S3 Camera · v1.4 · 60 × 85 mm · 4 層 · 2026-09-23

6

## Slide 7

插件兩顆：Economic 自己焊，Standard 由 JLCPCB 焊

兩顆通孔零件

Ref | 零件 | 料號 | 用途
J4 | JST PH 2.0 mm 2P 立式電池座 | C131337 | 接鋰電池，必要
J5 | 螢幕母座 1×7 2.54 mm 立式（CJT A2541WV-7P） | C225482 | 接 1.3 吋螢幕的杜邦線，v1.3 起


J4 電池座，從底面看。左上角 L 形絲印記號那一側是 pin 1（電池正極 VBAT），另一腳是 GND。

Economic 只焊 SMD

這兩顆會被略過，要自己買回來手焊。J4 一定要焊才能接電池；J5 要焊才能接螢幕，母座買 8.5 mm 高的標準款。

Standard 含插件

含插件焊接，這兩顆 JLCPCB 會一起焊好，不用自己買。收到板子接上電池、接上螢幕就能開機。

低角度側視：底面的 J5 母座（8.5 mm）是板上最高的插件。

ESP32-S3 Camera · v1.4 · 60 × 85 mm · 4 層 · 2026-09-23

7

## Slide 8

板外零件 7 項：一律自己買

1

OV2640 相機模組

24 pin 0.5 mm 排線，ESP32-CAM 相容

→ J2


組裝完成，底面（v1.3 直插版渲染）。603040 鋰電池墊泡棉貼在底面中央，黃色膠帶端是保護板；螢幕現在改用七條杜邦線接右板邊的 J5 母座，模組移到中央、鎖在後殼上；microSD 卡插在 J3

2

1.3 吋 ST7789 螢幕

→ J5

3

IPS 240×240，7 pin 直排針已焊；加 7 條公–母杜邦線接 J5

3.7V 鋰電池

→ J4

4

JST PH 2.0 插頭，帶保護板

microSD 卡

→ J3

8–32 GB，Class 10

USB-C 線

→ J1

5

要能傳資料，不要只能充電的線

6

M2 × 35 盤頭螺絲 × 4，M2 × 4 × 4

M2×35 從外殼背面鎖穿；M2×4 把螢幕鎖在後殼上

7

3D 列印外殼三件

前殼、後殼、快門帽；STL 在 enclosure/

相機排線容易折壞，建議多買一條備用。電池插頭極性沒有統一規範，收到先量。

ESP32-S3 Camera · v1.4 · 60 × 85 mm · 4 層 · 2026-09-23

8

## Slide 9

組裝完成示意

相機排線插進 J2 後反折 180° 讓模組貼回板面；microSD 卡插 J3；鋰電池墊在底面；螢幕接 J5 朝外（渲染為直插版，現改用杜邦線）。相機、記憶卡、電池、螢幕與側按快門是依實際尺寸畫的簡化模型，其餘是 KiCad 庫原廠 3D 模型。

組裝完成，頂面

橘色排線從 J2 出來反折，相機模組躺回板面、鏡頭朝上；左欄只剩兩顆鍵，快門在上板邊右段

從開關那一側看（v1.4）

螢幕模組蓋在電池上方（此圖為直插版）；右上角 SW4 電源開關撥桿突出板邊，上板邊是側按快門 SW3

OV2640 相機模組特寫

排線反折蓋過 J2 後接到模組，模組底下是泡棉膠墊；9 × 9 mm 感光板、8.5 mm 鏡座、Ø6.5 mm 鏡筒


ESP32-S3 Camera · v1.4 · 60 × 85 mm · 4 層 · 2026-09-23

9

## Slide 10

底面就是使用者看的那一面：螢幕朝外，鏡頭在反面


ESP32-S3 Camera · v1.4 · 60 × 85 mm · 4 層 · 2026-09-23

底面正視（含螢幕）

- 螢幕亮面朝外，2026-09-23 起用七條公–母杜邦線接右板邊的 J5 母座（左圖仍是直插版渲染）。腳序一對一：GND、3V3、SCL (GPIO44)、SDA (GPIO43)、RES (GPIO6)、DC (GPIO5)、BLK (GPIO4)。
- 杜邦線版模組移到 x 10.4–49.6、y 31.1–58.9，排針那排朝左；四角 Ø2 孔在 (12.9, 33.6)、(47.1, 33.6)、(12.9, 56.4)、(47.1, 56.4)，用 M2×4 鎖在後殼矮柱上


底面低角度，看高度

項目 | 高度 / 距離
電池 + 泡棉 | 8 mm
J5 母座 + 杜邦公頭膠殼 | 8.5 + 14 mm
模組 PCB 背面 → 亮面 | 23.6 → 約 26.4 mm
電池底到模組背面 / 外殼底側內深 | 15.6 mm / 27 mm

外殼開孔位置：鏡頭 (30, 25) 頂面、快門上板邊 x 47.6–53.6、BOOT / RESET 針孔 (9, 24) (9, 32)、開關右板邊 y 8–14、USB-C 右板邊、記憶卡左板邊、螢幕窗 23.4 × 23.4 中心 (28.4, 45)。

10

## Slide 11

相機模組落點與鏡頭中心

頂面正視

- 模組落在 x 25.5–34.5、y 20.5–29.5 mm 的空區，鏡頭中心 (30, 25)，外殼鏡頭孔與 Ø16 鏡座環對這個位置。
- 排線長度不同，落點會前後移；底下墊一塊約 2 mm 厚、8 × 8 mm 的雙面泡棉膠，不再懸出板邊。


ESP32-S3 Camera · v1.4 · 60 × 85 mm · 4 層 · 2026-09-23


上板邊右段：側按快門 SW3 觸桿朝板邊，SW4 撥桿突出右板邊，D5 藍燈在旁邊。


相機模組特寫：實品鏡片會有藍紫色鍍膜反光。

11

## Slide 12

裸板貼片後的 3D 渲染

只有 JLCPCB 出貨時板上會有的零件，沒有板外零件。用 KiCad 10 光線追蹤引擎從 v1.4 板檔輸出。

頂面立體。相機 FPC 座在上緣，快門在上緣右段，模組天線端懸在下方淨空區。


底面立體。microSD 座、JST 電池座與 J5 螢幕母座都在這一面。


頂面 / 底面正視。與 JLCPCB 預覽的 Top / Bottom 對應，底面已鏡像。

低角度側視。底面的母座是最高的插件。

相機接頭特寫。J2 掀蓋式 24P 座，右側 U5、U6 供相機電源。

USB-C 區。J1 開口朝板邊，下方 U4 是 ESD 保護。

12

ESP32-S3 Camera · v1.4 · 60 × 85 mm · 4 層 · 2026-09-23

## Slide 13

v1.4 重點特寫：側按快門、電源開關、USB-C、電池座


側按快門與電源開關（v1.4）。SW3 ALPS SKRTLAE010 在上板邊右段 (50.6, 2.6)，觸桿朝板邊伸出，外殼上牆的快門帽壓它；兩個 pad 1 用細線連通，GND 走板邊過孔。
SW4 撥桿朝右板邊，絲印 ON / OFF：撥向板子上緣是 OFF，撥向模組是 ON。D5 藍燈接 3.3V 開機必亮。

ESP32-S3 Camera · v1.4 · 60 × 85 mm · 4 層 · 2026-09-23

USB-C 區特寫。J1 母座開口朝板邊，下方 U4 是 USB ESD 保護。

J4 電池座，從底面看。以底面朝自己、天線那端朝下來看，pin 1（VBAT +）在左邊、靠板子中央；pin 2（GND）在右邊、靠板邊。

13

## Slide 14

3D 列印外殼：相機式兩片殼

SolidWorks 2024 依板檔座標用腳本建模，組合件放進板子 STEP 與相機模組、電池、記憶卡、螢幕、杜邦線的簡化模型做過干涉檢查（0 件）。整組 65 × 90 × 40.1 mm，壁厚 2 mm，外緣 R2.5 倒圓。


合起來：頂邊小方塊是快門帽，右側牆是開關槽與 USB-C 窗

爆炸圖：左前殼（鏡頭面）、中板子、右後殼（螢幕面）

前殼 · 鏡頭面

Ø10 鏡頭孔加 Ø16 凸 1.5 mm 鏡座環；上牆快門窗與 T 形快門帽；BOOT / RESET Ø2 針孔；三個 LED 導光孔；左側握持溝紋；右側牆 USB-C 窗、開關槽加指窪。

後殼 · 螢幕面

24.5 × 24.5 螢幕窗（中心 (28.4, 45)）外一層 0.8 mm 內縮邊框；左側牆記憶卡槽；四支 Ø5 立柱撐板子；四支 Ø4.5 矮柱，螢幕四角用 M2×4 鎖上。

固定與尺寸

四支 M2 × 35 從後殼沉孔鎖穿立柱與板子，自攻進前殼；後殼唇口對進前殼凹槽。前殼內高 8 mm，後殼內深 27 mm（給 J5 上的杜邦公頭膠殼）；螢幕亮面離板底 26.4 mm。

ESP32-S3 Camera · v1.4 · 60 × 85 mm · 4 層 · 2026-09-23

14

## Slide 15

外殼各面，與怎麼印

灰藍色渲染是 SolidWorks 組合件的標準視角；STL、SLDPRT、尺寸依據表在專案 enclosure/，改尺寸改腳本參數重跑即可。


鏡頭面

Ø10 鏡頭孔對 (30, 25)，外圈鏡座環；左欄兩個 Ø2 針孔是 RESET、BOOT；上方三個小孔透 D4 白、D1 綠，右上透 D5 藍。

螢幕面

24.5 × 24.5 螢幕窗壓在模組玻璃邊上、內側貼 0.5 mm 泡棉；四角是 M2 螺絲頭沉孔；左上小孔透 D2 紅色充電燈。

右側牆

上：電源開關槽 y 7–15 加 1 mm 深指窪，撥桿只伸出板邊 0.7 mm 所以牆要薄；下：USB-C 窗 y 18.75–29.25、高 4.2 mm。

左側牆

記憶卡槽在分模線下方的後殼上，卡插到底仍露出殼外 2 mm 好拔。

列印方向：兩片殼都開口朝下、外面朝上

外緣有 R2.5 倒圓，外面朝下印會讓圓角從近乎水平開始一層層外擴、表面很糙；翻過來讓圓角像圓頂往上收就沒有懸空，鏡座環、溝紋、螢幕邊框也都落在最上面那一面。
代價是殼內柱子變成從天花板往下長：前殼四支柱離床 2 mm，後殼立柱離床 1.6 mm、四支 2.2 mm 高的螢幕矮柱離床 26.4 mm。切片選「只在列印床上生成支撐」加樹狀支撐，支撐只會長在柱子下面。
各牆上的窗與槽都是垂直面上的橋接，不用支撐；快門帽凸緣朝下印。PLA / PETG 皆可，層高 0.2 mm、壁 3 圈；前殼約 20 g、後殼約 40 g（牆高 31 mm）。

ESP32-S3 Camera · v1.4 · 60 × 85 mm · 4 層 · 2026-09-23

15

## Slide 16

外殼裝配檢查：板外零件放進去看

相機模組與反折排線、電池與電池線、記憶卡、螢幕模組、七條杜邦線都依文件尺寸建成簡化模型放進 SolidWorks 組合件，和兩片殼一起跑干涉檢查：0 件。殼拿掉或調半透明拍的。


前殼拿掉：排線反折

橘色 24P 排線從 J2 出來、往板邊 2.5 mm 就以 0.7 mm 半徑反折，貼回板面接到黑色相機模組；反折最外緣離上牆內面 3.8 mm，鏡座頂離天花板 1.1 mm。

後殼拿掉

藍色螢幕模組鎖在後殼矮柱的高度、蓋在銀色電池上方，紅色是七條杜邦線的膠殼與線束；電池線從尾端繞到 J4 插頭；記憶卡從左板邊露出，正好穿過後殼的卡槽。

前殼半透明

看穿前殼：鏡頭穿出鏡座環、快門帽坐在上牆的窗裡對著開關觸桿、四支柱子壓在板子四角。後殼四支矮柱則頂住螢幕四角，M2×4 鎖住。

模型裡刻意沒放的東西

電池底下的泡棉（會包住 1.3 mm 高的零件，放進去只會報假警報）、插在 J4 裡的插頭本體、插在 J3 裡的卡身、膠殼與母座裡的針腳、杜邦線多出來的長度。相機鏡座原本只離天花板 0.1 mm，所以前殼內高從 7 改成 8 mm。

ESP32-S3 Camera · v1.4 · 60 × 85 mm · 4 層 · 2026-09-23

16

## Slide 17

螢幕改用杜邦線：線怎麼走，殼為什麼變厚

2026-09-23 決定不焊、直接用市售公–母杜邦線接螢幕。膠殼 14 mm 長，是後殼從 14.5 加深到 27 mm 內深的原因；紅色是七條線的膠殼與線束的簡化模型。


右側視：公頭膠殼到板底下 22.5 mm，螢幕吊在更深處

後殼與螢幕都拿掉：母頭在左、公頭站在右邊的 J5 母座上，線走電池底下

怎麼接

七條公–母杜邦線：公頭插 J5 母座、母頭套模組排針，腳序一對一，GND 對 GND，不用焊。模組改鎖在後殼四支矮柱上（M2×4），排針那排朝左。

線怎麼走

母頭朝板子伸 16.5 mm，線 S 彎後走電池底下 0.7 mm 的縫到模組右邊，沿模組邊下去、從底下繞進 J5 上的公頭；多出來的線盤在模組右邊。

代價

公頭膠殼 14 mm 站在 8.5 mm 母座上，線再彎出來 3.5：後殼內深 14.5 → 27 mm，整機 28.6 → 40.1 mm，外殼螺絲 M2×25 → M2×35。

ESP32-S3 Camera · v1.4 · 60 × 85 mm · 4 層 · 2026-09-23

17

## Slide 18

採購 A · 板子與板上零件：JLCPCB 一次搞定

上傳 fab/JLCPCB-上傳-v1.4/ 內的 gerber zip、BOM、CPL 三個檔。步驟見 fab/JLCPCB-下單清單.md。

下單規格

項目 | 規格 | 備註
PCB | 60 × 85 mm、4 層、1.6 mm、1 oz、ENIG 建議 | 最少 5 片
PCBA | Standard（含插件）或 Economic（只焊 SMD），雙面貼片 | 最少 2 片
配對頁要看的料號 | U1 C2913202（N16R8 模組，可能預購）、D3 C8598（SOD-123，不是 SS14）、SW4 C431540、SW3 C110293（ALPS SKRTLAE010 側按，不要被換成頂按式） | 逐行確認有貨

選 Economic 方案時要自己買並手焊的插件

零件 | 連結 | 備註
J4 JST PH 2.0 mm 2P 立式座 | LCSC C131337 (https://www.lcsc.com/product-detail/Wire-To-Board-Connector_JST-B2B-PH-K-S-LF-SN_C131337.html) | 電池座
J5 2.54 mm 1×7 立式母座（8.5 mm 高） | LCSC C225482 CJT A2541WV-7P；或 ICShop／蝦皮任何單排母座 2.54 1×7 (https://www.icshop.com.tw/products/368020101502) | 接螢幕的杜邦公頭插這裡；不要買 90° 或矮款

採購清單 2026-09-23 整理，與 fab/採購清單.md 同步。連結與價格為查詢當日所見，下單前再確認庫存與規格。

ESP32-S3 Camera · v1.4 · 60 × 85 mm · 4 層 · 2026-09-23

18

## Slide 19

採購 B · 板外零件：一律自己買

板外零件清單與購買網址

品項 | 規格 | 連結 | 備註
OV2640 相機模組 | 24 pin 0.5 mm 排線，ESP32-CAM 相容，排線約 21 mm | ICShop OV2640 攝影鏡頭 75° (https://www.icshop.com.tw/products/368030501479)（NT$110）、AliExpress 多焦距／夜視版 (https://www.aliexpress.us/item/3256802773370193.html) | 排線易折，多買一條。確認是 24P 0.5 mm、ESP32-CAM 用
鋰電池 | 3.7V 單芯，603040 或 503040 約 600 mAh，帶保護板，JST PH 2.0 插頭 | 勝特力 503040 600mAh (https://www.100y.com.tw/product/158757)、詠豐電子 503040 (https://www.yfe2019.com.tw/products/3.7V600mA%E8%81%9A%E5%90%88%E7%89%A9%E9%8B%B0%E9%9B%BB%E6%B1%A0503040-5e8561f5986e57d2.html)、ICShop 150mAh (https://www.icshop.com.tw/products/368090500104) | 收到先量極性，J4 pin 1 = 正極。換小電池要改 R3
預覽螢幕 | 通用型 1.3 吋 IPS 240×240 ST7789，7 pin 2.54 mm 直排針已焊，27.78 × 39.22 mm；加 7 條公–母 10 cm 杜邦線接 J5 | AliExpress 1.3" IPS ST7789 (https://www.aliexpress.us/item/2255800033232649.html)、AliExpress 另一賣家 (https://www.aliexpress.us/item/2251832694355820.html)；蝦皮搜「1.3吋 IPS 240x240 ST7789 7pin」約 NT$150–220 | 替代：ICShop Waveshare 1.3inch LCD（NT$225），腳序不同，用它附的線接
快門帽（外殼零件） | 3D 列印，T 形，凸緣 7.6 × 4.0 在牆內、頭露出 1 mm | STL 在 enclosure/ | 放在前殼上牆的窗裡，蓋殼時被 SW3 觸桿與牆夾住
microSD 卡 | 8–32 GB，Class 10 | 任何通路 | 金手指朝板子插入 J3
USB-C 線 | 要能傳資料 | 任何通路 | 燒錄與充電
M2 螺絲 | M2 × 35 盤頭 4 支 + M2 × 4 盤頭 4 支 | ICShop／蝦皮 | M2×35 從後殼沉孔鎖穿立柱與板子，自攻進前殼；M2×4 把螢幕鎖在後殼矮柱上
雙面泡棉膠 | 約 2 mm 厚 | 五金行 | 相機模組底下 8 × 8 mm，電池底下 26 × 36 mm
外殼前殼、後殼 | 3D 列印，PLA/PETG，開口朝下印，前殼約 20 g、後殼約 40 g | STL 在 enclosure/ | 開孔：鏡頭 (30, 25)、快門上板邊、針孔、開關與 USB-C 右板邊、記憶卡左板邊、螢幕窗 23.4 × 23.4 中心 (28.4, 45)；後殼內深 27 mm

ESP32-S3 Camera · v1.4 · 60 × 85 mm · 4 層 · 2026-09-23

19

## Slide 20

採購 C · 模組缺貨的備案，與最小採購

JLCPCB 的 ESP32-S3 模組缺貨時

品項 | 連結 | 備註
ESP32-S3-WROOM-1-N16R8 | DigiKey 台灣 (https://www.digikey.tw/zh/products/detail/espressif-systems/ESP32-S3-WROOM-1-N16R8/16162642) | 滿 NT$1400 免運
同上 | ICShop ESP32-S3-WROOM 模組 (https://www.icshop.com.tw/products/368030501809) | 確認是 N16R8 版

買回來用 JLCPCB 的代寄零件（Consigned parts）服務寄給他們，或自己回焊。

板外零件實物照片（賣場頁面）

板子本身還沒製作，沒有實拍。板外零件的實物照片在各賣場頁面，直接附連結。

OV2640 相機模組 → J2

黑色方形感光板加一條 24pin 棕色軟排線，鏡頭在正面。排線接觸面朝下插入 J2。

ICShop OV2640 75° (https://www.icshop.com.tw/products/368030501479)　AliExpress 多焦距 (https://www.aliexpress.us/item/3256802773370193.html)　Play Robot ESP32-CAM 含模組 (https://shop.playrobot.com/products/cee0055)

只想先點亮板子的最小採購

- OV2640 相機模組
- 3.7V 鋰電池（JST PH 2.0，帶保護板）
- microSD 卡
- USB-C 線（能傳資料）
- Economic 方案再加 J4 電池座；要看畫面再加 1.3 吋螢幕、7 條公–母杜邦線與 J5 母座

ESP32-S3 Camera · v1.4 · 60 × 85 mm · 4 層 · 2026-09-23

3.7V 鋰電池 → J4

銀色鋁塑軟包，一端有黃色膠帶包住的保護板，兩線紅黑接白色 JST PH 2.0 插頭。

ICShop 2400mAh (https://www.icshop.com.tw/products/368090500165)　ICShop 150mAh (https://www.icshop.com.tw/products/368090500104)　Yahoo 拍賣 950mAh (https://tw.bid.yahoo.com/item/100076609165)

板上連接器的長相（JLCPCB 貼好）

想先知道焊上去是什麼樣子，LCSC 產品頁有實物照。

J2 FH12-24S　J3 DM3AT　J1 USB-C 16P　J4 B2B-PH-K-S　J5 A2541WV-7P　SW3 SKRTLAE010　U1 模組 (https://www.lcsc.com/product-detail/C202112.html)

20

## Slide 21


下一步

三個動作，板子就能開機

1

JLCPCB 下單

上傳 Gerber、BOM、CPL；在配對頁逐行確認 U1、D3、SW3、SW4 有貨；選 Standard 或 Economic。

2

自己買板外零件

相機模組、1.3 吋螢幕與 7 條公–母杜邦線、鋰電池、microSD 卡、USB-C 線、M2×35 與 M2×4 螺絲；Economic 再加 J4、J5。同時把外殼三件印出來。

3

組裝

接電池前先量極性（J4 pin 1 = 正極）。排線反折讓模組貼回板面，墊 2 mm 泡棉膠。螢幕鎖在後殼上、用杜邦線接 J5（GND 對 GND），再蓋上前殼。

ESP32-S3 Camera · v1.4 · 60 × 85 mm · 4 層 · 2026-09-23

21

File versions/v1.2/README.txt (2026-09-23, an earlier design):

v1.2 — 2026-09-21 定稿；同日 18:16 送洗前檢查後更新快照（板子仍為 v1.2，絲印、標題欄、Gerber ProjectId 不變）。
相對 v1.1 的改動：新增電源滑動開關 SW4（控制 U2 EN）、EN 上拉 R21 100k、
藍色電源燈 D5 與限流 R20 1k；U2 pin 3 改為 LDO_EN 網路，C1/C2 的 VSYS 以 In2 內層跳線重接；
開關旁絲印 ON/OFF；絲印與標題欄 v1.2。
送洗前修正（v1.1 起就存在的缺陷）：J2.23 相機 AGND 與 C3.2 輸出電容 GND 兩個焊盤原本只接到孤立敷銅、沒有過孔，
各加一顆 GND 過孔（(37.0, 3.45) 與 (42.8, 53.0)），IPROG 頂層走線小幅上移讓位；R21 轉 180° 對齊原理圖腳位；
補 LCSC 欄位與封裝庫名。ERC 0 錯誤；DRC 0 錯誤、0 警告、0 未連接、原理圖一致性 0 問題。
內容：原理圖、板檔、專案檔、網表、ERC/DRC 報告、fab/（Gerber zip、鑽孔、BOM 35 行、CPL 58 顆、下單清單、採購清單）、
自訂 footprint 庫。預覽螢幕為外接（DESIGN.md 2d），不影響板子版本。
此資料夾視為唯讀。

2026-09-24 補回 v1.2 簡報（原本在根目錄，09-22 被 v1.4 版取代後刪除，自 commit 2c3535a 還原）：
esp32s3-camera-v1.2.pptx / .pdf（完整版）、esp32s3-camera-v1.2-簡易版.pptx / .pdf。

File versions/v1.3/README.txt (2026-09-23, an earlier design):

v1.3 — 2026-09-21 晚上定稿（v1.2 未下單，直接改成 v1.3）。
起因：要 3D 列印相機式外殼（鏡頭正面、螢幕背面），杜邦線接螢幕在外殼裡收不乾淨。
相對 v1.2 的改動：拆掉 J5 UART/DEBUG 1x4 與 J6 EXPANSION 1x4 兩條排針，
換成一個 1x7 2.54 mm 立式母座 J5（CJT A2541WV-7P，LCSC C225482），底面右板邊 x = 56，
pin 1 GND 在 y 52.62（靠天線端、方形焊盤）到 pin 7 BLK 在 y 37.38，腳序 GND VCC SCL SDA RES DC BLK 與
通用型 1.3 吋 IPS 240x240 ST7789 7 pin 模組相同，模組直接插入、亮面朝外、身體蓋在電池上方。
SCL = GPIO44（網路 UART_RX）、SDA = GPIO43（網路 UART_TX），RES/DC/BLK = GPIO6/5/4。
走線：UART_TX/UART_RX 頂層線只改末端；IO6/IO5/IO4 由原頂層線末端各加一顆過孔，沿右板邊底層 x 57.4/58.05/58.7 往上進 pin 5/6/7。
絲印：底面每腳旁 GND 3V3 SCL SDA RES DC BLK、DISPLAY；B.Fab 有模組 27.78x39.22 投影框。絲印、標題欄、Gerber ProjectId 皆為 v1.3。
58 顆 SMD 與 v1.2 完全相同，CPL 相同；插件 J4、J5 兩顆。零件 60 顆。
驗證：ERC 0 錯誤（2 個 XC6206 符號庫警告）；DRC 含原理圖一致性 0 錯誤、0 警告、0 未連接、0 一致性問題；
gnd_connectivity.py GND / +3V3 全部焊盤在主群集。
內容：原理圖、板檔、專案檔、網表、ERC/DRC 報告、fab/（Gerber zip、鑽孔、BOM 34 行、CPL 58 顆、JLCPCB-上傳-v1.3、下單清單、採購清單）、自訂 footprint 庫。
機構數字（外殼用）見 DESIGN.md「v1.3 改了什麼」：螢幕模組 PCB 背面離板底 11.0 mm、亮面 13.9 mm、有效顯示區中心約 (40.5, 45)。
腳本：render/illustration/v13_sch.py、v13_pcb.py、v13_pcb_fix.py、v13_pcb_fix2.py。
此資料夾視為唯讀。

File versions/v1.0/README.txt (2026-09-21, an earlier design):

ESP32-S3 Camera — v1.0 存檔（2026-09-17 改 J2 腳位前的最後狀態）
==================================================================

這三個檔案原本是根目錄的 *.bak_before_j2fix，2026-09-18 整理時改回正常檔名搬到這裡。

與 v1.1（根目錄正式檔）的差異：
- J2 相機 FPC 座腳位是舊定義，對不上 AI-Thinker ESP32-CAM 標準 24pin，和 v1.1 的韌體 camera_config_t 不相容。
- 沒有相機 LDO U5（2.8V）、U6（1.2V）和 C12–C17，共 53 個零件。
- 設計規則較鬆：間距 0.127 mm、線寬 0.15 mm；沒有 Plane 網路類別。
- 絲印文字為「rev A」，無標題欄版本號。

用途只有回頭對照，不要拿這一版出 Gerber 或下單。
專案內建封裝 ESP32-S3-WROOM-1-Cam 已內嵌在 .kicad_pcb 裡，直接開 .kicad_pro 即可，不需要 fp-lib-table。

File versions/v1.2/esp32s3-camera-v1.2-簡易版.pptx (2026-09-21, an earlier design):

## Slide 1


一塊自己設計的
小相機板

手掌大小、可以裝電池、拍完存進記憶卡。這份簡報用最少的專業名詞，說明它是什麼、要買什麼、怎麼組起來。

第 1.2 版 · 2026 年 9 月

ESP32-S3 相機板 · 簡易說明

1

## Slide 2

它能做什麼

1

拍照

板上插一顆小鏡頭，按一下快門鍵就拍。

2

存進記憶卡

照片存在 microSD 卡裡，拔下來就能在電腦上看。


板子右上角是電源開關，旁邊小顆的是藍色電源燈，下面是 USB-C 充電孔。

3

用電池跑

裝一顆手機那種鋰電池，插 USB 就能充電。

4

有開關和指示燈

撥開關開機，藍燈亮表示有電；充電時紅燈亮。

5

可以加小螢幕（選配）

外接一片 1.3 吋螢幕，拍之前先看畫面。

6

Wi-Fi

板上的晶片本身有 Wi-Fi，照片也能傳到手機或電腦。

ESP32-S3 相機板 · 簡易說明

2

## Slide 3

正面長這樣

鏡頭朝這一面，四個角有螺絲孔可以鎖進外殼。


鏡頭

小小一顆黑色方塊，跟手機鏡頭差不多大。用一條軟排線接到板子，可以翻折貼平。

電源開關

往上撥關機、往下撥開機，板上印了 ON / OFF。

三顆按鍵

上面兩顆是開發用的，最下面那顆是快門。

USB-C 孔

跟現在的手機一樣的接頭，用來充電和把程式燒進去。

主晶片

銀色方塊是整塊板子的大腦，內建 Wi-Fi，底下黑色區域是天線，不能被金屬遮住。

擴充排針

右邊兩排金色小孔，接選配的小螢幕就是從這裡拉線。

ESP32-S3 相機板 · 簡易說明

3

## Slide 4

背面長這樣

電池貼在背面中間，螢幕再疊在電池上。這一面是使用的時候朝著自己的那一面。


小螢幕（選配）

1.3 吋正方形螢幕，蓋在電池上面，用七條細線接到旁邊的排針。

記憶卡

microSD 卡從左邊板邊插進去，推到「喀」一聲。再推一下會退出。

電池

白色長方形是鋰電池，黃色那端是保護板。用雙面泡棉膠貼住。

充電晶片

上面左邊那一排小零件負責幫電池充電，充電中會微溫是正常的。

電池插座

小小的白色兩腳插座，電池線插這裡。插之前要先確認正負極。

天線區

最下面深色那一條下面是 Wi-Fi 天線，外殼這裡不要用金屬。

ESP32-S3 相機板 · 簡易說明

4

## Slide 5

工廠做一半，我們做一半

工廠負責

- 把設計圖做成 4 層的電路板
- 把 58 顆小零件焊上去（最小的比米粒還小，人手焊不了）
- 焊好寄回來，收到就是一塊完整的板子
- 選「含插件」方案的話，電池插座和排針也會一起焊好

工廠：JLCPCB，中國深圳的線上電路板廠，上傳檔案線上下單。

ESP32-S3 相機板 · 簡易說明

我們自己負責

- 另外買鏡頭、電池、記憶卡、USB 線
- 把鏡頭的排線插上、電池貼上、記憶卡插入
- 把程式燒進板子
- 想要螢幕的話，接七條線裝上去
- 找一個外殼，或 3D 列印一個

全部不需要焊接，除非選了「只焊小零件」的便宜方案，那三顆插座要自己焊。

5

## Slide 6

要另外買的東西

板子本身不含這些。前四項是必要的，後面是選配。

鏡頭模組

OV2640，跟 ESP32-CAM 用的同一種。排線很脆弱，多買一條備用。

約 NT$110

鋰電池

3.7V、約 600 mAh、帶保護板、白色小插頭（JST PH 2.0）。

約 NT$100–200

記憶卡

microSD 8–32 GB，一般的就好。

手邊有就用

USB-C 線

要能傳資料的，不能是只能充電的線。

手邊有就用

小螢幕（選配）

1.3 吋 IPS 240×240，ST7789，7 針焊接式。加 7 條母對母杜邦線。

約 NT$150–220

價格是 2026 年 9 月在台灣網購看到的大約數字。詳細店家連結在專案的採購清單裡。

螺絲、泡棉膠、外殼（選配）

M2 螺絲和銅柱 4 組、2 mm 厚雙面泡棉膠、自製或 3D 列印外殼。

看外殼

ESP32-S3 相機板 · 簡易說明

6

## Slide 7

組裝只有三步

插鏡頭

排線金屬面朝下插進板子上緣的黑色小座，出來一點就往回折 180°，讓鏡頭躺回板面。底下墊一小塊泡棉膠。

ESP32-S3 相機板 · 簡易說明


貼電池、插記憶卡

電池用泡棉膠貼在背面中間，插頭插進白色小座。插之前先確認紅線對到有 L 形記號那一邊。記憶卡從左邊推進去。


插 USB、撥開關

接上 USB-C 線，把開關往下撥，藍燈亮就是開機了。第一次先不要接電池，確認燈會亮再說。


1

2

3

7

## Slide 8

三件要注意的事

電池正負極

電池插頭的紅黑線沒有統一規範，插之前一定要對一下：紅線要對到板上有 L 形記號的那一腳。插反會燒壞。


排線很脆弱

鏡頭那條軟排線折幾次就會斷，只在需要的地方折一次，其他時間不要拉扯。多買一條備用。

電池插座的特寫。左上角有 L 形白色印記的那一腳是正極，紅線要對到這裡。


天線那一區不要壓金屬

板子最下面深色那一條是 Wi-Fi 天線。外殼那一段用塑膠，電池不要貼到那裡，不然訊號會變差。

ESP32-S3 相機板 · 簡易說明

8

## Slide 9


接下來會發生什麼

下單

把檔案上傳給工廠，選好數量與方案。約 1–2 天內工廠回信確認。

1

2

等貨

製作加運送大約兩到三週。這段時間把鏡頭、電池、記憶卡買齊。

3

組裝

照前面三步組起來，接 USB 看藍燈亮。

4

拍第一張照片

燒入程式，用手機連上板子的 Wi-Fi 看畫面，按快門。

ESP32-S3 相機板 · 簡易說明

9

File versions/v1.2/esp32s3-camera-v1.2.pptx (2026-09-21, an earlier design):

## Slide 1


ESP32-S3 CAMERA · V1.2 · 60 × 85 MM · 4 層

哪些零件 JLCPCB
幫你焊好，
哪些要自己買

零件分工圖、組裝示意、3D 渲染與採購清單。依實際 PCB 座標整理，對應 2026-09-21 定稿的電路板 v1.2。

JLCPCB 貼好（SMD）

插件三顆

板外零件，自己買

ESP32-S3 Camera · v1.2 · 60 × 85 mm · 4 層 · 2026-09-21

1

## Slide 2

本頁對應電路板 v1.2

2026-09-21 定稿，快照存在專案 versions/v1.2/，含 Gerber、BOM、CPL、ERC/DRC 報告，視為唯讀

v1.0

最初佈局

- 60 × 85 mm 四層板
- ESP32-S3-WROOM-1 模組
- OV2640 相機、microSD、鋰電池充電

v1.1

相機腳位標準化

- 相機腳位改為 ESP32-CAM 標準
- 加相機專用 2.8V / 1.2V LDO
- BOM 填入 LCSC 料號

v1.2

電源開關與電源燈

- 加電源滑動開關 SW4
- 加 EN 上拉 R21
- 加藍色電源燈 D5 與限流 R20
- 絲印標 ON / OFF

›

›

預覽螢幕為外接：1.3 吋 ST7789 IPS 螢幕接在 J5、J6 排針上，不改板，仍屬 v1.2。不再規劃 v1.3。

ESP32-S3 Camera · v1.2 · 60 × 85 mm · 4 層 · 2026-09-21

2

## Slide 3

零件分三類：貼好的、插件的、板外的

58 顆 SMD · 32 項

JLCPCB 貼好

上傳 BOM 與 CPL 即可，料號已填在 BOM 內。電阻電容全是 Basic Part，其餘是模組與連接器。

PCBA 方案怎麼選

3 顆插件

Economic 自己焊，Standard 代焊

J4 電池座、J5 UART 排針、J6 擴充排針。J4 一定要焊才能接電池。

6 項板外零件

一律自己買

相機模組、鋰電池、microSD 卡、USB-C 線、M2 螺絲銅柱、外殼或夾具。

| Economic 只焊 SMD | Standard 含插件
JLCPCB 焊什麼 | 58 顆 SMD | 58 顆 SMD + J4、J5、J6 三顆插件
自己要做什麼 | 買 J4（必要）與 J5、J6（可先空著）回來手焊 | 不用買插件，收到板子直接接電池

ESP32-S3 Camera · v1.2 · 60 × 85 mm · 4 層 · 2026-09-21

3

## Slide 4

頂面 Top · F.Cu · 30 顆 SMD

依實際 PCB 座標繪製。粉紅色為板外零件的位置示意。

JLCPCB 貼好（SMD）

板外零件，自己買

ANTENNA KEEPOUT

J2

U5

Q1

U6

SW4

USB-C 線 → J1

燒錄與充電。J1 母座開口朝右板邊，要用能傳資料的線。

OV2640 相機模組 → J2

排線從 J2 出來後反折 180°，模組貼回板面、鏡頭朝上，底下墊 2 mm 泡棉膠。落在按鍵那一欄與 U4 之間的空區，鏡頭中心 (30, 25)。

SW2

J1

SW1

U4

v1.2 新增：SW4、D5、R20

右上角 SW4 電源滑動開關撥桿突出板邊，絲印 ON / OFF；D5 藍色電源燈與 R20 限流電阻在旁邊。

M2 螺絲 × 4 → H1–H4

四角 Ø2.2 定位孔，配 M2 銅柱鎖外殼。

SW3

U1

外殼 / 夾具

自製或 3D 列印，固定相機模組，鏡頭開孔對 (30, 25)。

U1 ESP32-S3-WROOM-1-N16R8

模組天線端懸在下方深綠色淨空區，那一帶不放任何零件。

ESP32-S3 Camera · v1.2 · 60 × 85 mm · 4 層 · 2026-09-21

4

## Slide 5

底面 Bottom · B.Cu · 24 顆 SMD + 3 插件

從底面看，已左右鏡像，與 KiCad 3D 檢視及 JLCPCB 預覽的 Bottom 一致。

JLCPCB 貼好（SMD）

插件，Economic 要自己焊

ANTENNA KEEPOUT

板外零件，自己買

D3

U3

J4 電池座（插件）

JST PH 2.0 mm 2P 立式座。L 形絲印那側是 pin 1（VBAT +），靠板子中央；pin 2 GND 靠板邊。

電源電路在這一角

U3 TP4056 充電、D3 B5819W、U2 3.3V LDO、Q2 MOSFET 與 R21 EN 上拉。

LiPo 603040

Q2

J3

3.7V 鋰電池 → J4

JST PH 2.0 插頭、帶保護板。603040（30 × 40 × 6 mm）墊 2 mm 泡棉貼在底面中央 (34, 44)。收到先量極性，pin 1 = 正極。

J5

U2

microSD 卡 → J3

8–32 GB，金手指朝板子插入，卡槽開口朝這一側的板邊。

J6

J5 UART、J6 擴充排針（插件）

1×4 2.54 mm。要接螢幕建議用 90° 彎針，不撐高。暫時用不到可以先空著。

J4

1.3 吋預覽螢幕（選配）

疊在電池外側、亮面朝外，7 pin 排針邊朝 J5、J6 那側的板邊，離排針只有 5 mm，七條短線接完。

ESP32-S3 Camera · v1.2 · 60 × 85 mm · 4 層 · 2026-09-21

5

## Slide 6

JLCPCB 貼好：58 顆 SMD · 32 項

上傳 fab/esp32s3-camera-bom.csv 與 CPL 即可，料號已填在 BOM 內

板上零件清單


裸板貼片後的頂面：三顆按鍵、FPC 座、ESP32 模組與天線淨空區

v1.2 新增的三顆：SW4 電源開關、D5 藍色電源燈、R20 限流電阻，都在右上角，一起由 JLCPCB 貼好。

- U1 ESP32-S3-WROOM-1-N16R8 模組 C2913202
- U2 AP2112K 3.3V LDO；U5 2.8V、U6 1.2V LDO 供相機
- U3 TP4056 充電；U4 USBLC6 ESD；Q1 Q2 MOSFET
- J1 USB-C 座；J2 24P FPC 座；J3 microSD 座
- SW1–3 按鍵；SW4 電源滑動開關 C431540（v1.2 新增）
- D1 D2 D4 LED；D5 藍色電源燈 C2288（v1.2 新增）；D3 B5819W C8598
- 21 顆電阻、17 顆電容，全部 Basic Part（v1.2 多了 R20 限流、R21 EN 上拉）

配對頁要看的料號：U1 C2913202（N16R8 模組，可能預購）、D3 C8598（SOD-123，不是 SS14）、SW4 C431540。逐行確認有貨。

ESP32-S3 Camera · v1.2 · 60 × 85 mm · 4 層 · 2026-09-21


6

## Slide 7

插件三顆：Economic 自己焊，Standard 由 JLCPCB 焊

三顆通孔零件

Ref | 零件 | 料號 | 用途
J4 | JST PH 2.0 mm 2P 立式電池座 | C131337 | 接鋰電池，必要
J5 | UART 除錯排針 1×4 2.54 mm | C124378 | 除錯、接螢幕
J6 | 擴充排針 1×4 2.54 mm | C124378 | 擴充、接螢幕


J4 電池座，從底面看。左上角 L 形絲印記號那一側是 pin 1（電池正極 VBAT），另一腳是 GND。

Economic 只焊 SMD

這三顆會被略過，要自己買回來手焊。J4 一定要焊才能接電池，J5、J6 暫時用不到可以先空著。

Standard 含插件

含插件焊接，這三顆 JLCPCB 會一起焊好，不用自己買。收到板子接上電池就能開機。


低角度側視：排針與 JST 座是板上最高的插件。

ESP32-S3 Camera · v1.2 · 60 × 85 mm · 4 層 · 2026-09-21

7

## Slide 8

板外零件 6 項：一律自己買

1

OV2640 相機模組

24 pin 0.5 mm 排線，ESP32-CAM 相容

→ J2


組裝完成，底面。603040 鋰電池墊泡棉貼在底面中央，黃色膠帶端是保護板；電池外側再疊 1.3 吋 ST7789 預覽螢幕，7 pin 排針邊朝右板邊；microSD 卡插在 J3。

2

3.7V 鋰電池

→ J4

JST PH 2.0 插頭，帶保護板

3

microSD 卡

8–32 GB，Class 10

→ J3

4

USB-C 線

要能傳資料，不要只能充電的線

→ J1

5

M2 螺絲與銅柱 4 組

→ H1–H4

6

長度依外殼決定

外殼或夾具

自製或 3D 列印，固定相機模組

相機排線容易折壞，建議多買一條備用。電池插頭極性沒有統一規範，收到先量。

ESP32-S3 Camera · v1.2 · 60 × 85 mm · 4 層 · 2026-09-21

8

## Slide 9

組裝完成示意

相機排線插進 J2 後反折 180° 讓模組貼回板面；microSD 卡插 J3；鋰電池墊在底面；螢幕疊在電池外側朝外。相機、記憶卡、電池、螢幕是依實際尺寸畫的簡化模型，其餘是 KiCad 庫原廠 3D 模型。

組裝完成，頂面

橘色排線從 J2 出來反折，相機模組躺回板面、鏡頭朝上；右側是 USB-C 座 J1

從開關那一側看（v1.2）

右上角是 SW4 電源開關，撥桿突出板邊；旁邊小顆的是 D5 藍色電源燈，下方是 USB-C 座 J1

OV2640 相機模組特寫

排線反折蓋過 J2 後接到模組，模組底下是泡棉膠墊；9 × 9 mm 感光板、8.5 mm 鏡座、Ø6.5 mm 鏡筒


ESP32-S3 Camera · v1.2 · 60 × 85 mm · 4 層 · 2026-09-21

9

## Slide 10

底面就是使用者看的那一面：螢幕朝外，鏡頭在反面


ESP32-S3 Camera · v1.2 · 60 × 85 mm · 4 層 · 2026-09-21

底面正視（含螢幕）

- 螢幕亮面朝外，7 pin 排針邊朝右，離 J5、J6 排針 5 mm，七條短線就接完。
- 螢幕四角 Ø2 mm 孔落在 (16.9, 33.6)、(51.1, 33.6)、(16.9, 56.4)、(51.1, 56.4)，可用 M2 銅柱固定到外殼。
- 螢幕轉 90°，通用型 1.3 吋 IPS ST7789，27.78 × 39.22 mm，依 lcdwiki 尺寸圖 1:1。


底面低角度，看高度

項目 | 高度 / 距離
電池 + 泡棉 | 8 mm
J5、J6 排針 | 8.5 mm
螢幕模組疊上去 | +2.8 mm → 約 10.8 mm
螢幕距排針 / J4 / 天線區 | 5.2 / 4.5 / 10.5 mm

外殼開孔位置：鏡頭 (30, 25)、開關右板邊 y 8–14、USB-C 右板邊、記憶卡左板邊、螢幕窗 23.4 × 23.4 mm。

10

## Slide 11

相機模組落點與鏡頭中心

頂面正視

- 模組落在 x 25.5–34.5、y 20.5–29.5 mm 的空區，鏡頭中心 (30, 25)，外殼開孔對這個位置。
- 排線長度不同，落點會前後移；底下墊一塊約 2 mm 厚、8 × 8 mm 的雙面泡棉膠，不再懸出板邊。


ESP32-S3 Camera · v1.2 · 60 × 85 mm · 4 層 · 2026-09-21


從開關側看：SW4 撥桿突出板邊，D5 藍燈在旁邊。


相機模組特寫：實品鏡片會有藍紫色鍍膜反光。

11

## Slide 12

裸板貼片後的 3D 渲染

只有 JLCPCB 出貨時板上會有的零件，沒有板外零件。用 KiCad 10 光線追蹤引擎從最終板檔輸出。

頂面立體。相機 FPC 座在上緣，模組天線端懸在下方淨空區。


底面立體。microSD 座、JST 電池座與 J5、J6 排針都在這一面。


頂面 / 底面正視。與 JLCPCB 預覽的 Top / Bottom 對應，底面已鏡像。


低角度側視。排針與 JST 座是最高的插件。


相機接頭特寫。J2 掀蓋式 24P 座，右側 U5、U6 供相機電源。

USB-C 區。J1 開口朝板邊，下方 U4 是 ESD 保護。

12

ESP32-S3 Camera · v1.2 · 60 × 85 mm · 4 層 · 2026-09-21

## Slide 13

v1.2 重點特寫：電源開關、電源燈、USB-C、電池座

電源開關與電源燈（v1.2）。SW4 撥桿朝右板邊，絲印標了 ON / OFF：撥向板子上緣（角落孔那側）是 OFF，撥向模組方向是 ON。
D5 藍燈接在 3.3V 上，開機必亮；開關控制穩壓器 EN，關機時 USB 仍可充電。

ESP32-S3 Camera · v1.2 · 60 × 85 mm · 4 層 · 2026-09-21

USB-C 區特寫。J1 母座開口朝板邊，下方 U4 是 USB ESD 保護。

J4 電池座，從底面看。以底面朝自己、天線那端朝下來看，pin 1（VBAT +）在左邊、靠板子中央；pin 2（GND）在右邊、靠板邊。

13

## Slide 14

採購 A · 板子與板上零件：JLCPCB 一次搞定

上傳 fab/esp32s3-camera-gerber.zip、esp32s3-camera-bom.csv、esp32s3-camera-cpl.csv。步驟見 fab/JLCPCB-下單清單.md。

下單規格

項目 | 規格 | 備註
PCB | 60 × 85 mm、4 層、1.6 mm、1 oz、ENIG 建議 | 最少 5 片
PCBA | Standard（含插件）或 Economic（只焊 SMD），雙面貼片 | 最少 2 片
配對頁要看的料號 | U1 C2913202（N16R8 模組，可能預購）、D3 C8598（SOD-123，不是 SS14）、SW4 C431540 | 逐行確認有貨

選 Economic 方案時要自己買並手焊的插件

零件 | 連結 | 備註
J4 JST PH 2.0 mm 2P 立式座 | LCSC C131337 (https://www.lcsc.com/product-detail/Wire-To-Board-Connector_JST-B2B-PH-K-S-LF-SN_C131337.html) | 電池座
J5、J6 排針 1×4 2.54 mm ×2 | ICShop 單排 90° 排針（剪成 4P） (https://www.icshop.com.tw/products/368020101502)、LCSC C124378 直排 (https://www.lcsc.com/product-detail/PCB-Connectors-Headers-Male-Pins_Shenzhen-Cankemeng-Headers-Pins-1-4P-2-54mm-Straight-line_C124378.html) | 要接螢幕建議用 90° 彎針，不撐高

採購清單 2026-09-21 整理，與 fab/採購清單.md 同步。連結與價格為查詢當日所見，下單前再確認庫存與規格。

ESP32-S3 Camera · v1.2 · 60 × 85 mm · 4 層 · 2026-09-21

14

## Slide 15

採購 B · 板外零件：一律自己買

板外零件清單與購買網址

品項 | 規格 | 連結 | 備註
OV2640 相機模組 | 24 pin 0.5 mm 排線，ESP32-CAM 相容，排線約 21 mm | ICShop OV2640 攝影鏡頭 75° (https://www.icshop.com.tw/products/368030501479)（NT$110）、AliExpress 多焦距／夜視版 (https://www.aliexpress.us/item/3256802773370193.html) | 排線易折，多買一條。確認是 24P 0.5 mm、ESP32-CAM 用
鋰電池 | 3.7V 單芯，603040 或 503040 約 600 mAh，帶保護板，JST PH 2.0 插頭 | 勝特力 503040 600mAh (https://www.100y.com.tw/product/158757)、詠豐電子 503040 (https://www.yfe2019.com.tw/products/3.7V600mA%E8%81%9A%E5%90%88%E7%89%A9%E9%8B%B0%E9%9B%BB%E6%B1%A0503040-5e8561f5986e57d2.html)、ICShop 150mAh (https://www.icshop.com.tw/products/368090500104) | 收到先量極性，J4 pin 1 = 正極。換小電池要改 R3
預覽螢幕（選配） | 通用型 1.3 吋 IPS 240×240 ST7789，7 pin 2.54 mm 焊接式，27.78 × 39.22 mm | AliExpress 1.3" IPS ST7789 (https://www.aliexpress.us/item/2255800033232649.html)、AliExpress 另一賣家 (https://www.aliexpress.us/item/2251832694355820.html)；蝦皮搜「1.3吋 IPS 240x240 ST7789 7pin」約 NT$150–220 | 替代：ICShop Waveshare 1.3inch LCD (https://www.icshop.com.tw/products/368031700013)（NT$225），板子較大、腳序不同
杜邦線 | 母對母 10 cm，7 條 | ICShop／蝦皮任選 | 接螢幕到 J5、J6
microSD 卡 | 8–32 GB，Class 10 | 任何通路 | 金手指朝板子插入 J3
USB-C 線 | 要能傳資料 | 任何通路 | 燒錄與充電
M2 螺絲與銅柱 | 板子 4 組，螢幕 4 組（螢幕四角 Ø2 孔） | ICShop／蝦皮 | 長度依外殼
雙面泡棉膠 | 約 2 mm 厚 | 五金行 | 相機模組底下 8 × 8 mm，電池底下 26 × 36 mm
外殼 | 自製或 3D 列印 | — | 開孔：鏡頭 (30, 25)、開關右板邊 y 8–14、USB-C 右板邊、記憶卡左板邊、螢幕窗 23.4 × 23.4

ESP32-S3 Camera · v1.2 · 60 × 85 mm · 4 層 · 2026-09-21

15

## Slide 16

採購 C · 模組缺貨的備案，與最小採購

JLCPCB 的 ESP32-S3 模組缺貨時

品項 | 連結 | 備註
ESP32-S3-WROOM-1-N16R8 | DigiKey 台灣 (https://www.digikey.tw/zh/products/detail/espressif-systems/ESP32-S3-WROOM-1-N16R8/16162642) | 滿 NT$1400 免運
同上 | ICShop ESP32-S3-WROOM 模組 (https://www.icshop.com.tw/products/368030501809) | 確認是 N16R8 版

買回來用 JLCPCB 的代寄零件（Consigned parts）服務寄給他們，或自己回焊。

板外零件實物照片（賣場頁面）

板子本身還沒製作，沒有實拍。板外零件的實物照片在各賣場頁面，直接附連結。

OV2640 相機模組 → J2

黑色方形感光板加一條 24pin 棕色軟排線，鏡頭在正面。排線接觸面朝下插入 J2。

ICShop OV2640 75° (https://www.icshop.com.tw/products/368030501479)　AliExpress 多焦距 (https://www.aliexpress.us/item/3256802773370193.html)　Play Robot ESP32-CAM 含模組 (https://shop.playrobot.com/products/cee0055)

只想先點亮板子的最小採購

- OV2640 相機模組
- 3.7V 鋰電池（JST PH 2.0，帶保護板）
- microSD 卡
- USB-C 線（能傳資料）
- Economic 方案再加 J4 電池座

ESP32-S3 Camera · v1.2 · 60 × 85 mm · 4 層 · 2026-09-21

3.7V 鋰電池 → J4

銀色鋁塑軟包，一端有黃色膠帶包住的保護板，兩線紅黑接白色 JST PH 2.0 插頭。

ICShop 2400mAh (https://www.icshop.com.tw/products/368090500165)　ICShop 150mAh (https://www.icshop.com.tw/products/368090500104)　Yahoo 拍賣 950mAh (https://tw.bid.yahoo.com/item/100076609165)

板上連接器的長相（JLCPCB 貼好）

想先知道焊上去是什麼樣子，LCSC 產品頁有實物照。

J2 FH12-24S (https://www.lcsc.com/product-detail/C202112.html)　J3 DM3AT (https://lcsc.com/product-detail/C114218.html)　J1 USB-C 16P (https://www.lcsc.com/product-detail/C2894897.html)　J4 B2B-PH-K-S (https://www.lcsc.com/product-detail/C131337.html)　U1 模組 (https://www.lcsc.com/product-detail/WiFi-Modules_Espressif-Systems-ESP32-S3-WROOM-1-N16R8_C2913202.html)

16

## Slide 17


下一步

三個動作，板子就能開機

1

JLCPCB 下單

上傳 Gerber、BOM、CPL；在配對頁逐行確認 U1、D3、SW4 有貨；選 Standard 或 Economic。

2

自己買板外零件

相機模組、鋰電池、microSD 卡、USB-C 線；Economic 再加 J4 電池座。相機排線多買一條。

3

組裝

接電池前先量極性（J4 pin 1 = 正極）。排線反折讓模組貼回板面，墊 2 mm 泡棉膠。螢幕接 J5、J6。

ESP32-S3 Camera · v1.2 · 60 × 85 mm · 4 層 · 2026-09-21

17

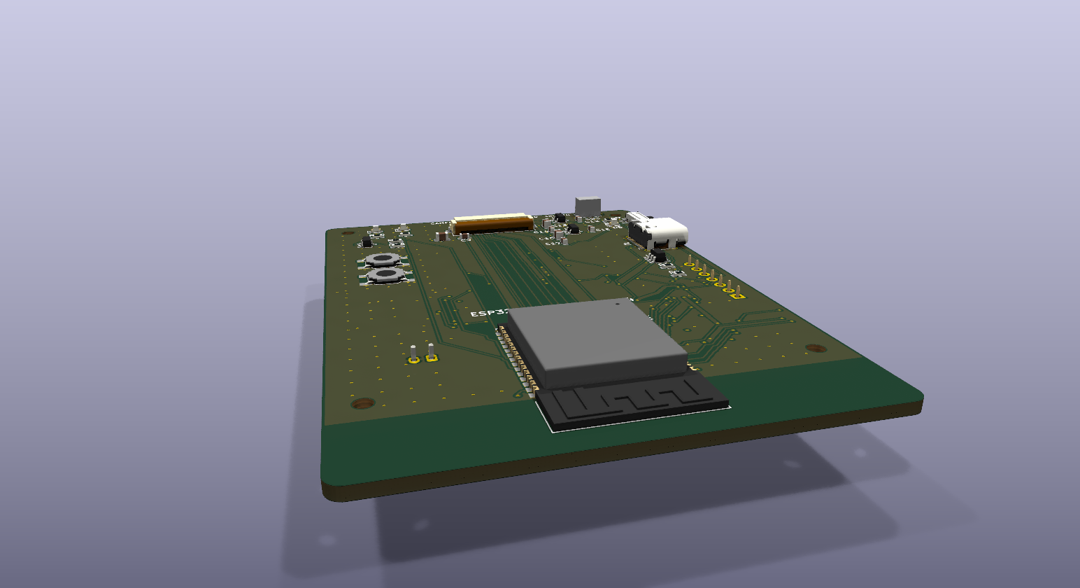
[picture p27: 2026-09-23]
render/low-angle.png

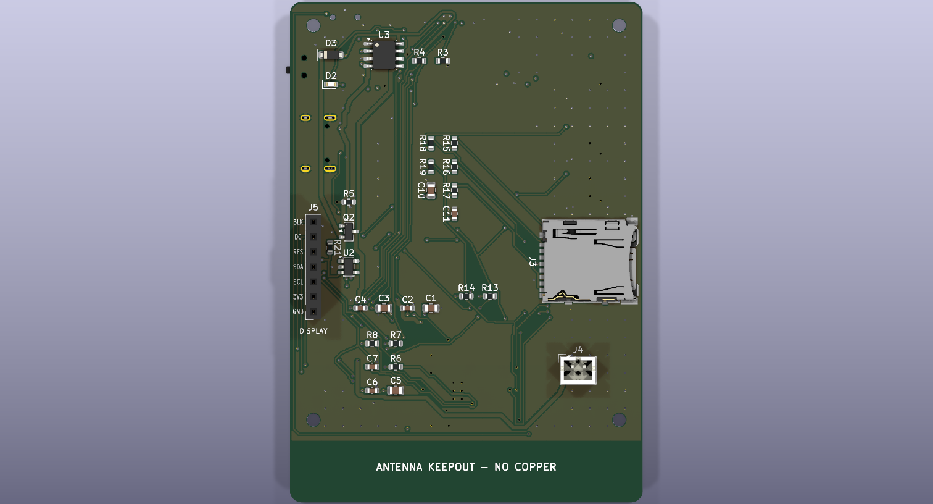
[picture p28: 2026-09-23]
view-bottom.png

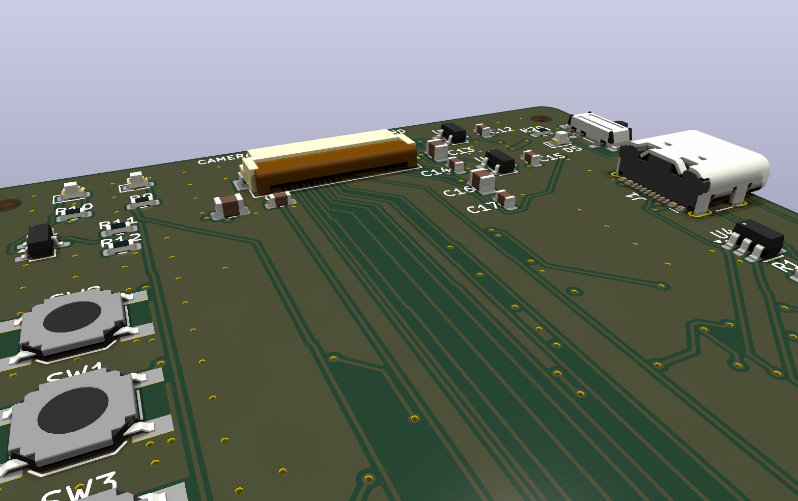
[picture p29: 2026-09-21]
render/closeup-usb.png

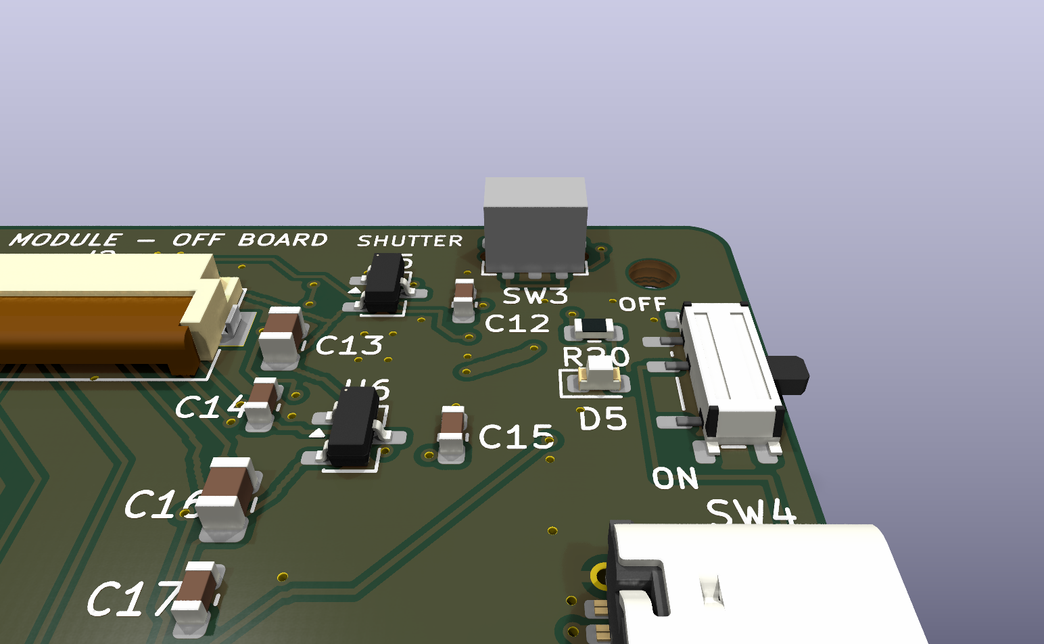
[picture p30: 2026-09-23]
render/closeup-shutter.png

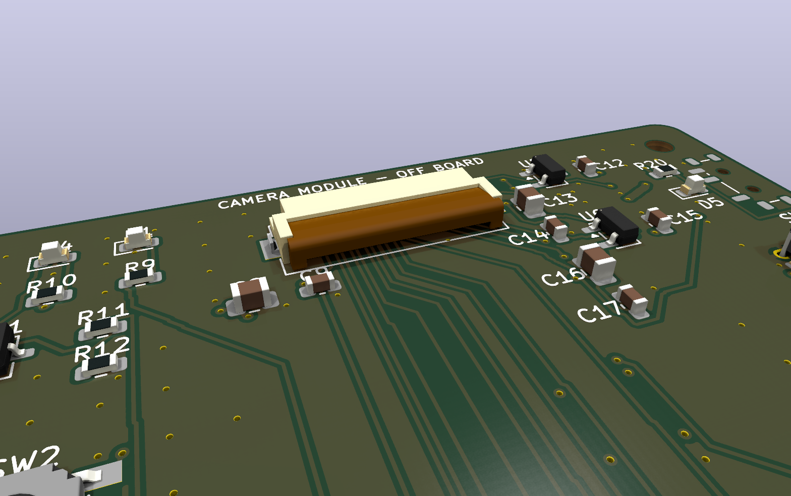
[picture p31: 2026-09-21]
render/closeup-camera.png

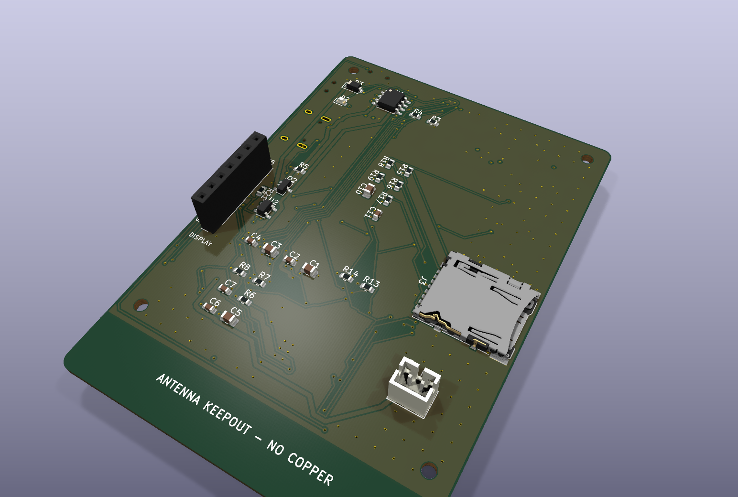
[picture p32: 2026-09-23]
render/iso-bottom.png

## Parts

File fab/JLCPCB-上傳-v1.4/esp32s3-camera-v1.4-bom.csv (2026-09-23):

Designator | Comment | Footprint | Qty | LCSC Part #
C1,C3 | 22u | Capacitor_SMD:C_0805_2012Metric | 2 | C45783
C2,C4,C7,C12,C15 | 1u | Capacitor_SMD:C_0603_1608Metric | 5 | C15849
C5,C8,C10,C13,C16 | 10u | Capacitor_SMD:C_0805_2012Metric | 5 | C15850
C6,C9,C11,C14,C17 | 100n | Capacitor_SMD:C_0603_1608Metric | 5 | C14663
D1 | GREEN | LED_SMD:LED_0603_1608Metric | 1 | C72043
D2 | RED | LED_SMD:LED_0603_1608Metric | 1 | C2286
D3 | SS14 | Diode_SMD:D_SOD-123 | 1 | C8598
D4 | WHITE | LED_SMD:LED_0603_1608Metric | 1 | C2290
D5 | BLUE | LED_SMD:LED_0603_1608Metric | 1 | C2288
J1 | USB-C | Connector_USB:USB_C_Receptacle_HCTL_HC-TYPE-C-16P-01A | 1 | C2894897
J2 | OV2640/OV5640 24P | Connector_FFC-FPC:Hirose_FH12-24S-0.5SH_1x24-1MP_P0.50mm_Horizontal | 1 | C202112
J3 | microSD | Connector_Card:microSD_HC_Hirose_DM3AT-SF-PEJM5 | 1 | C114218
J4 | LiPo 3.7V | Connector_JST:JST_PH_B2B-PH-K_1x02_P2.00mm_Vertical | 1 | C131337
J5 | DISPLAY 1.3in ST7789 | Connector_PinSocket_2.54mm:PinSocket_1x07_P2.54mm_Vertical | 1 | C225482
Q1 | AO3400A | Package_TO_SOT_SMD:SOT-23 | 1 | C20917
Q2 | AO3401A | Package_TO_SOT_SMD:SOT-23 | 1 | C15127
R1,R2 | 5.1k | Resistor_SMD:R_0603_1608Metric | 2 | C23186
R3 | 2k | Resistor_SMD:R_0603_1608Metric | 1 | C22975
R4,R9,R20 | 1k | Resistor_SMD:R_0603_1608Metric | 3 | C21190
R5,R12,R21 | 100k | Resistor_SMD:R_0603_1608Metric | 3 | C25803
R6-R8,R15-R19 | 10k | Resistor_SMD:R_0603_1608Metric | 8 | C25804
R10 | 47 | Resistor_SMD:R_0603_1608Metric | 1 | C23182
R11 | 100 | Resistor_SMD:R_0603_1608Metric | 1 | C22775
R13,R14 | 4.7k | Resistor_SMD:R_0603_1608Metric | 2 | C23162
SW1 | BOOT | Button_Switch_SMD:SW_SPST_SKQG_WithoutStem | 1 | C115351
SW2 | RESET | Button_Switch_SMD:SW_SPST_SKQG_WithoutStem | 1 | C115351
SW3 | SHUTTER | esp32s3-camera:SW_Push_SKRTLAE010_Side | 1 | C110293
SW4 | PWR | Button_Switch_SMD:SW_SPDT_Shouhan_MSK12C02 | 1 | C431540
U1 | ESP32-S3-WROOM-1-N16R8 | esp32s3-camera:ESP32-S3-WROOM-1-Cam | 1 | C2913202
U2 | AP2112K-3.3 | Package_TO_SOT_SMD:SOT-23-5 | 1 | C51118
U3 | TP4056 | Package_SO:SOIC-8-1EP_3.9x4.9mm_P1.27mm_EP2.41x3.3mm | 1 | C16581
U4 | USBLC6-2SC6 | Package_TO_SOT_SMD:SOT-23-6 | 1 | C7519
U5 | XC6206P282MR | Package_TO_SOT_SMD:SOT-23-3 | 1 | C14255
U6 | XC6206P122MR | Package_TO_SOT_SMD:SOT-23-3 | 1 | C424699

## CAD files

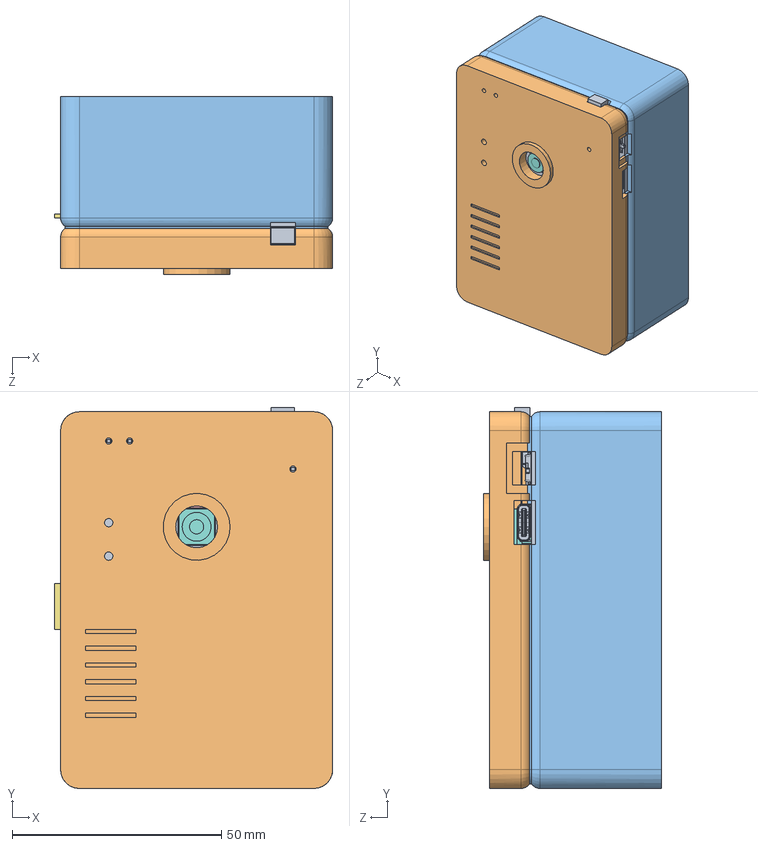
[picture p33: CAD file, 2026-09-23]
enclosure/esp32s3-camera-enclosure.SLDASM
66.5 x 91.0 x 42.6 mm
esp32s3-camera-board
offboard-camera-module
offboard-battery-card
offboard-display-module
offboard-ribbon
offboard-display-cable
esp32s3-camera-shell-back
esp32s3-camera-shell-front
esp32s3-camera-shutter-cap

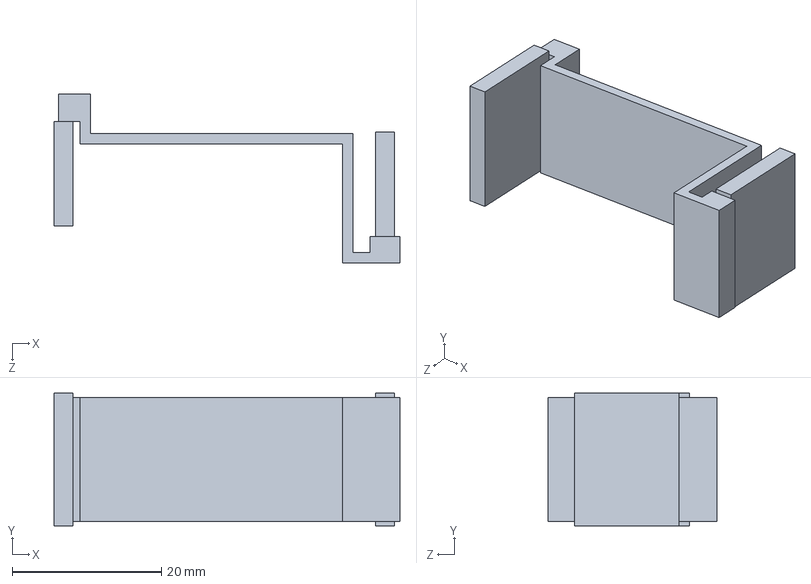
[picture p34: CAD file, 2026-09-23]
enclosure/offboard-display-cable.SLDPRT
46.4 x 17.8 x 22.6 mm

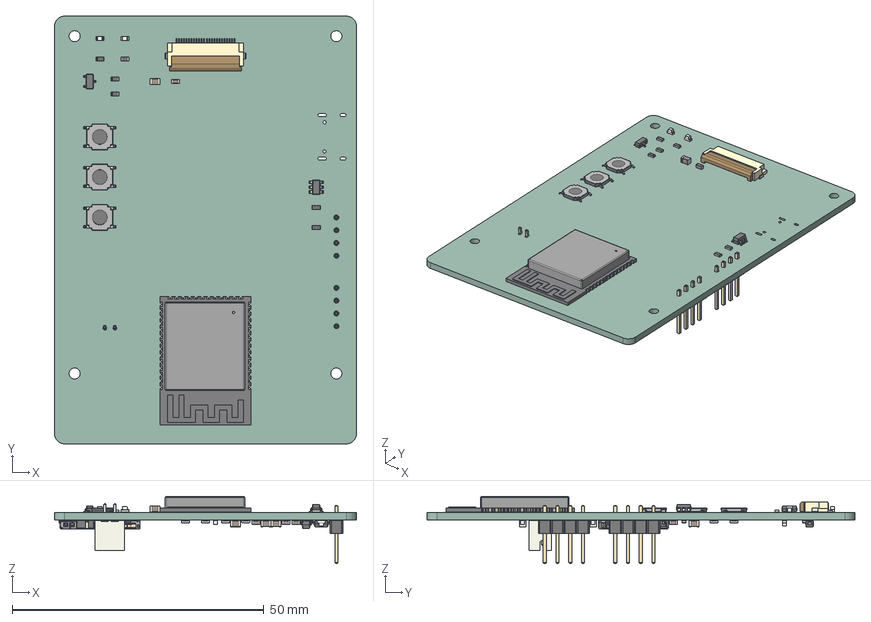
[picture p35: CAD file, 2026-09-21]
esp32s3-camera.step
60.0 x 85.0 x 13.3 mm
R_0603_1608Metric x 19
SW_SPST_SKQG_WithoutStem x 3
ESP32-S3-WROOM-1
LED_0603_1608Metric x 3
SOT-23 x 2
C_0805_2012Metric x 5
SOT-23-6
lock
pins
C_0603_1608Metric x 6
microSD_HC_Hirose_DM3AT-SF-PEJM5
SOT-23-5
PinHeader_1x04_P254mm_Vertical x 2
D_SOD-123
JST_B2B_PH_K
esp32s3-camera_PCB

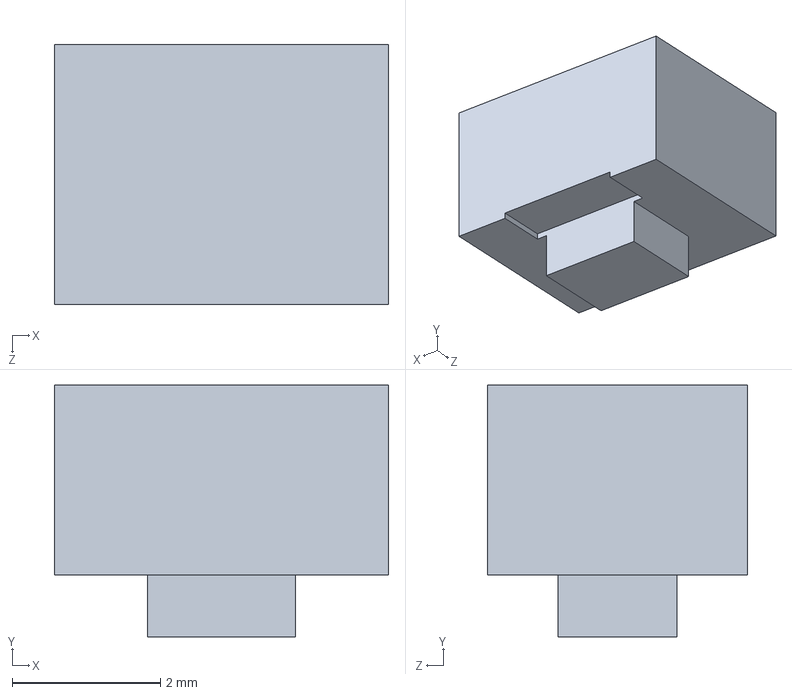
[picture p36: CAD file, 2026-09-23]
models/SW_Push_SKRTLAE010_Side.step
4.50 x 3.39 x 3.50 mm

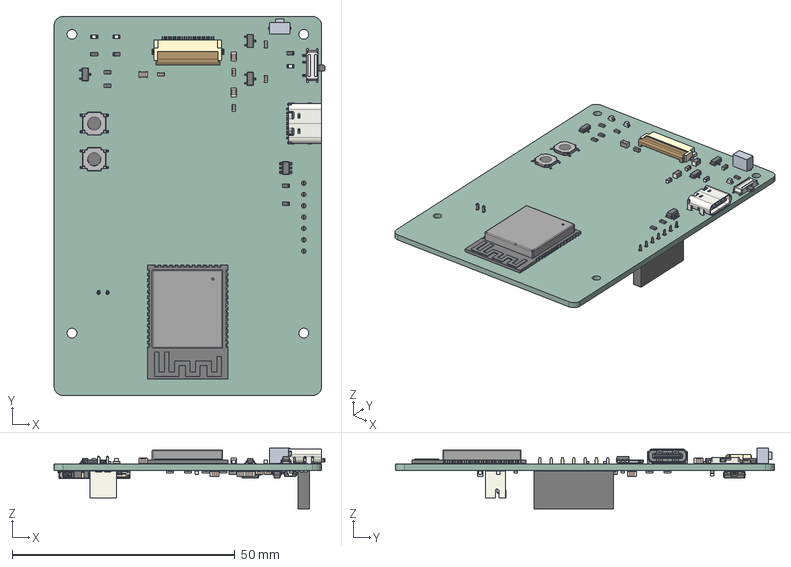
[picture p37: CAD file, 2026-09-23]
versions/v1.4/esp32s3-camera.step
60.7 x 85.0 x 13.7 mm
R_0603_1608Metric x 21
SW_Push_SKRTLAE010_Side
SW_SPST_SKQG_WithoutStem x 2
C_0603_1608Metric x 10
ESP32-S3-WROOM-1
LED_0603_1608Metric x 4
C_0805_2012Metric x 7
SOT-23 x 2
SOT-23-3 x 2
SOT-23-6
lock
pins
USB_C_Receptacle_16P_TopMnt_Horizontal_GCT_USB4105-xx-A
Fusion_sp
microSD_HC_Hirose_DM3AT-SF-PEJM5
SOT-23-5
D_SOD-123
JST_B2B_PH_K
SOIC-8-1EP_3.9x4.9mm_P1.27mm_EP2.41x3.81mm
PinSocket_1x07_P2.54mm_Vertical
esp32s3-camera_PCB

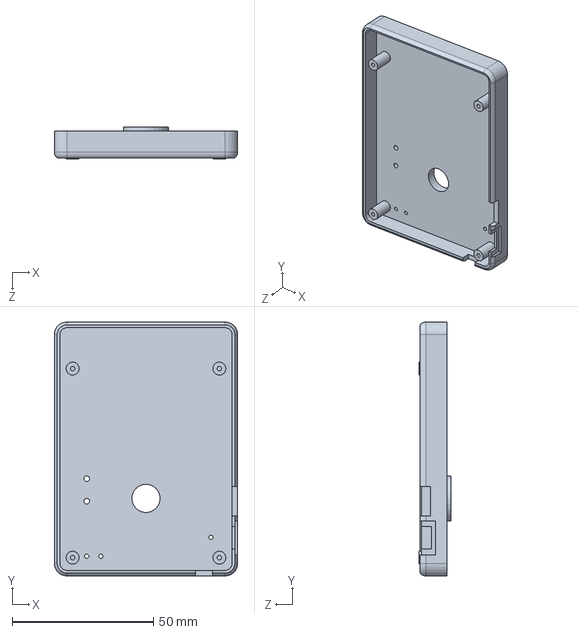
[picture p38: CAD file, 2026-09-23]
enclosure/esp32s3-camera-shell-front.SLDPRT
65.0 x 90.0 x 11.5 mm

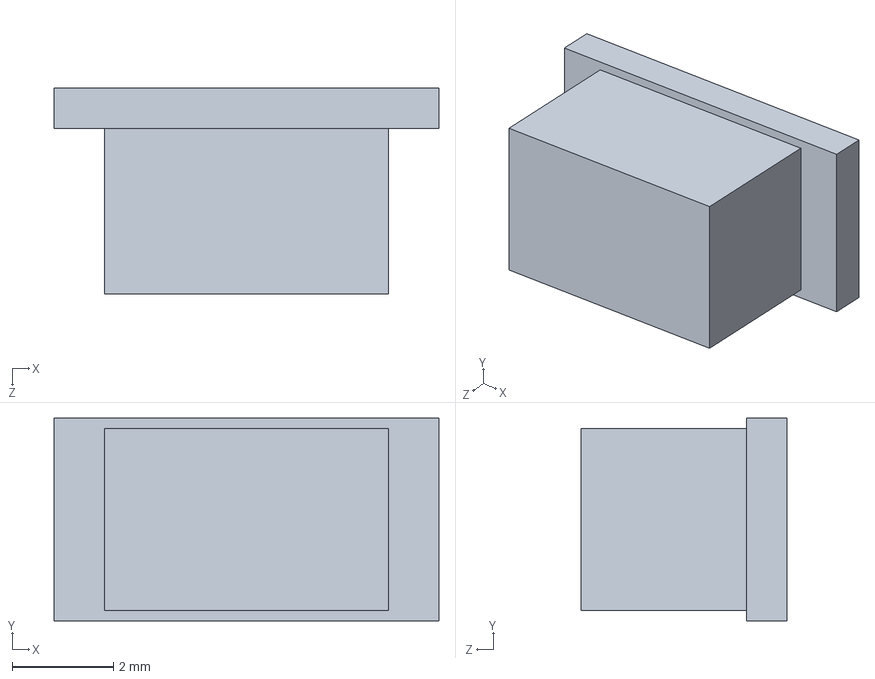
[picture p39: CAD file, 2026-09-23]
enclosure/esp32s3-camera-shutter-cap.SLDPRT
7.60 x 4.00 x 4.06 mm

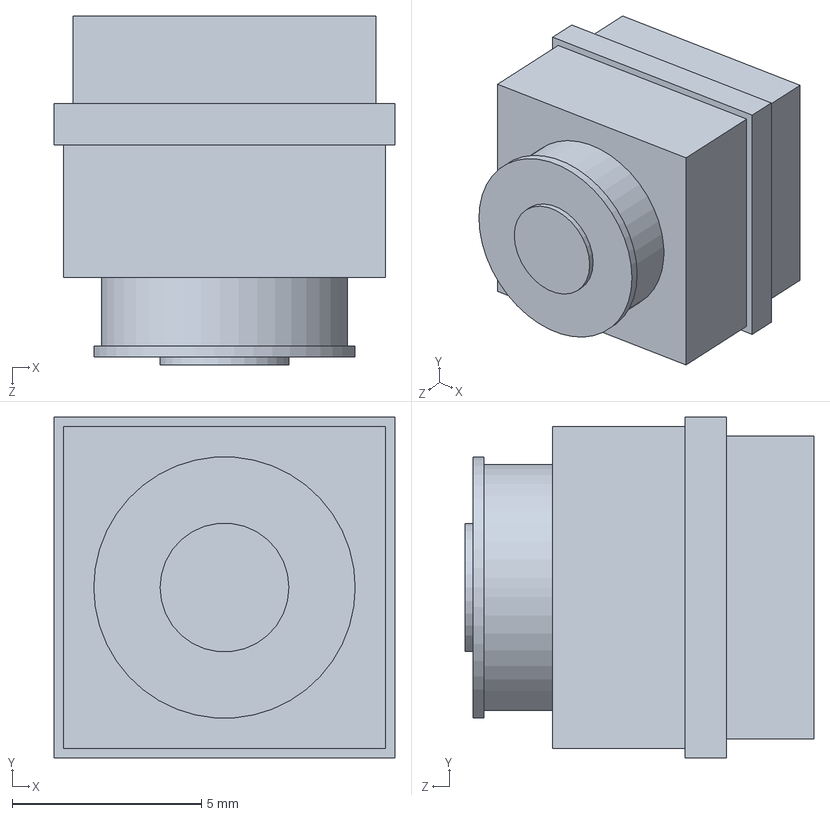
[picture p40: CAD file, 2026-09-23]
enclosure/offboard-camera-module.SLDPRT
9.00 x 9.00 x 9.20 mm

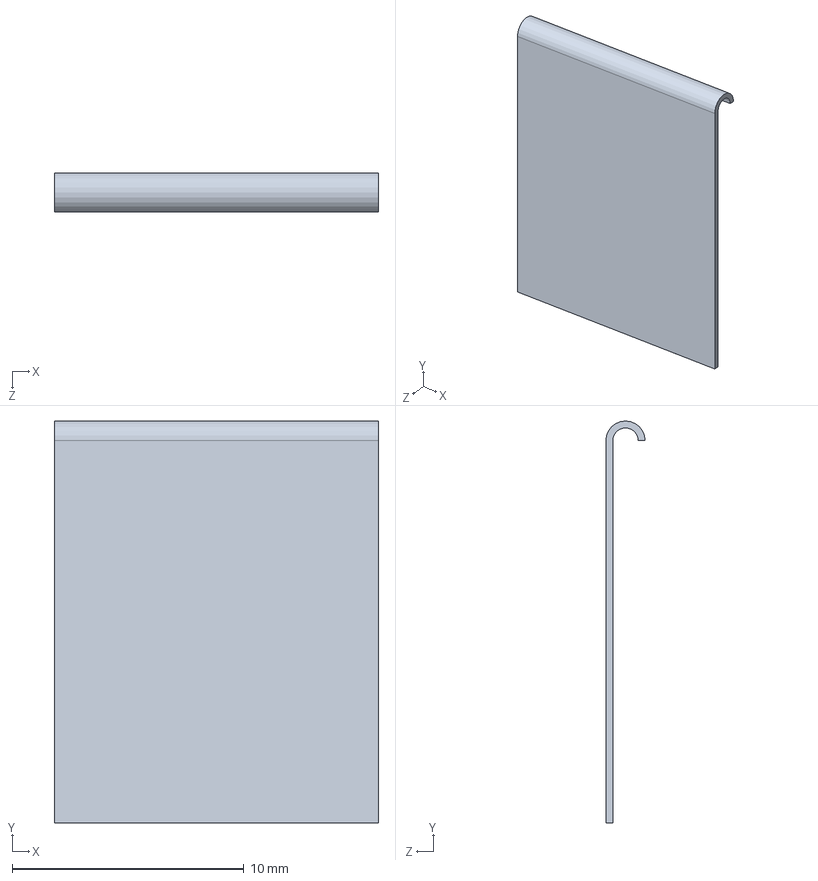
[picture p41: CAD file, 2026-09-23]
enclosure/offboard-ribbon.SLDPRT
14.0 x 17.4 x 1.70 mm

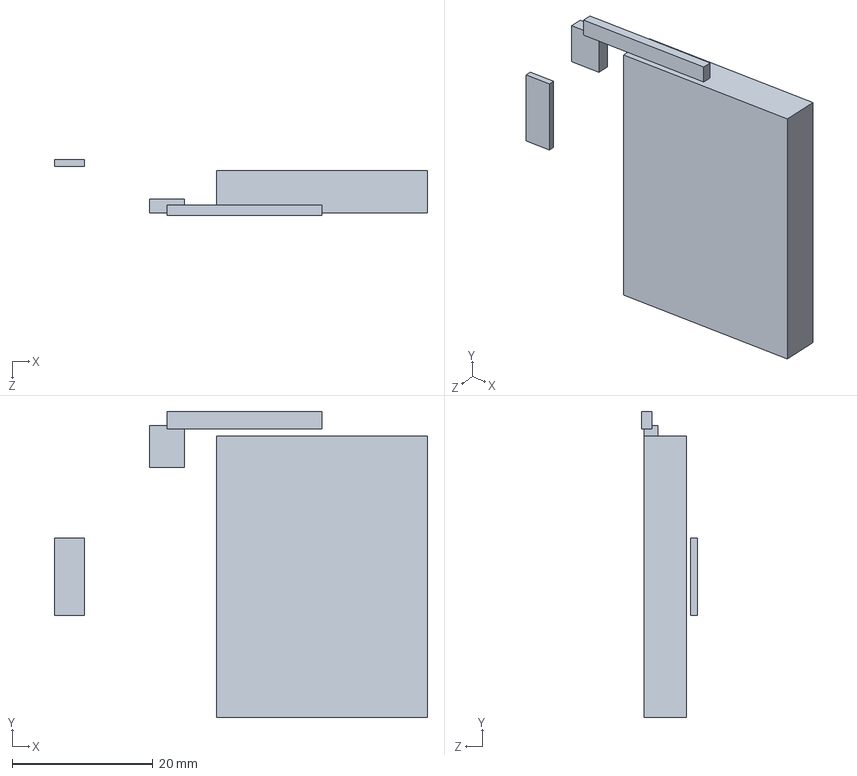
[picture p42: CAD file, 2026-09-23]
enclosure/offboard-battery-card.SLDPRT
53.0 x 43.5 x 8.00 mm

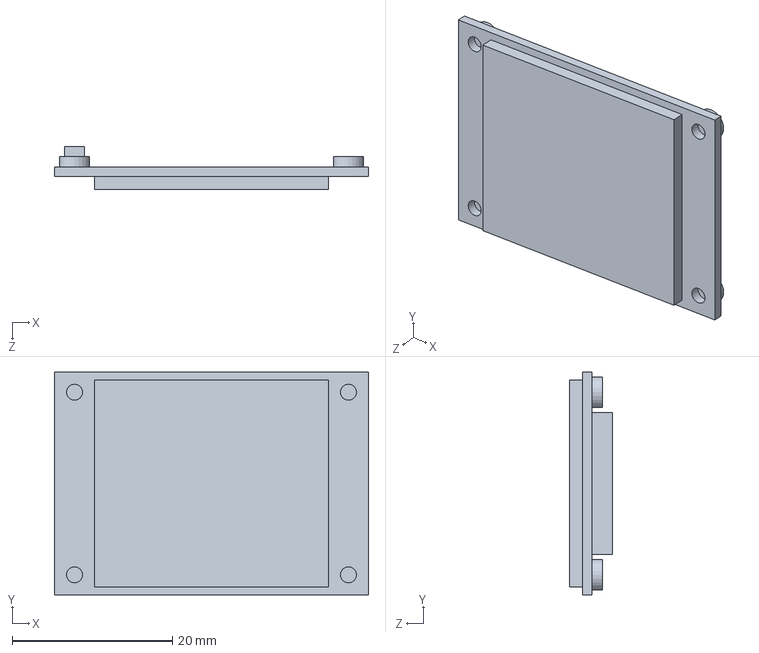
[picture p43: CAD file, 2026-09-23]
enclosure/offboard-display-module.SLDPRT
39.2 x 27.8 x 5.34 mm

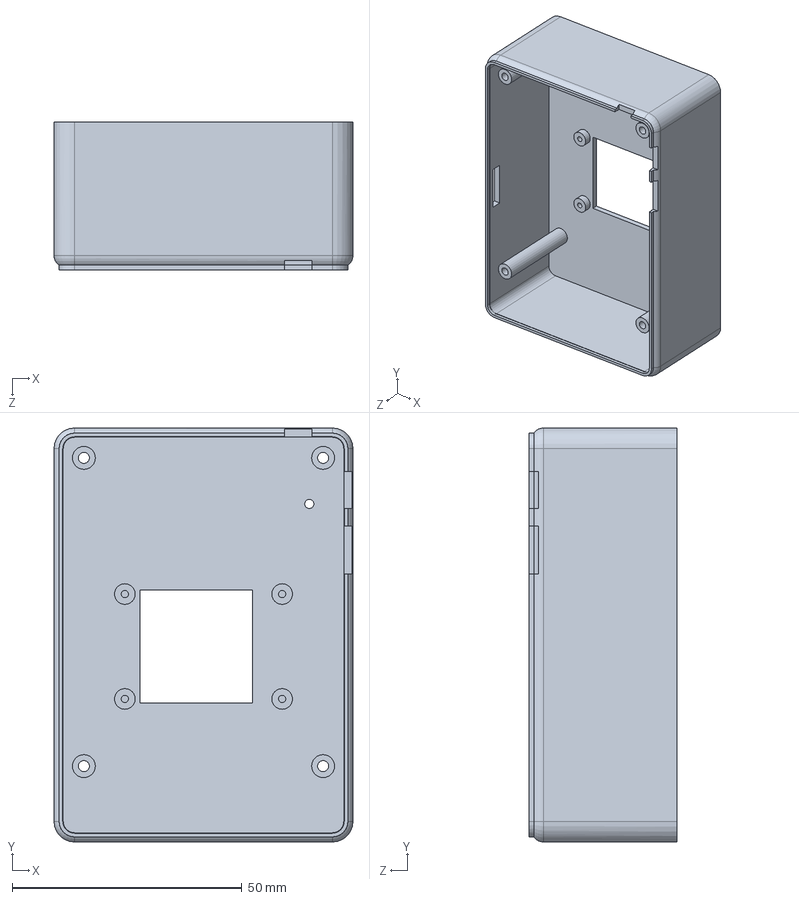
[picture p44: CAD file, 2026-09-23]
enclosure/esp32s3-camera-shell-back.SLDPRT
65.0 x 90.0 x 32.1 mm

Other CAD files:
enclosure/esp32s3-camera-board.SLDPRT
enclosure/esp32s3-camera-shell-back.STL
enclosure/esp32s3-camera-shell-front.STL
enclosure/esp32s3-camera-shutter-cap.STL
models/SW_Push_SKRTLAE010_Side.SLDPRT

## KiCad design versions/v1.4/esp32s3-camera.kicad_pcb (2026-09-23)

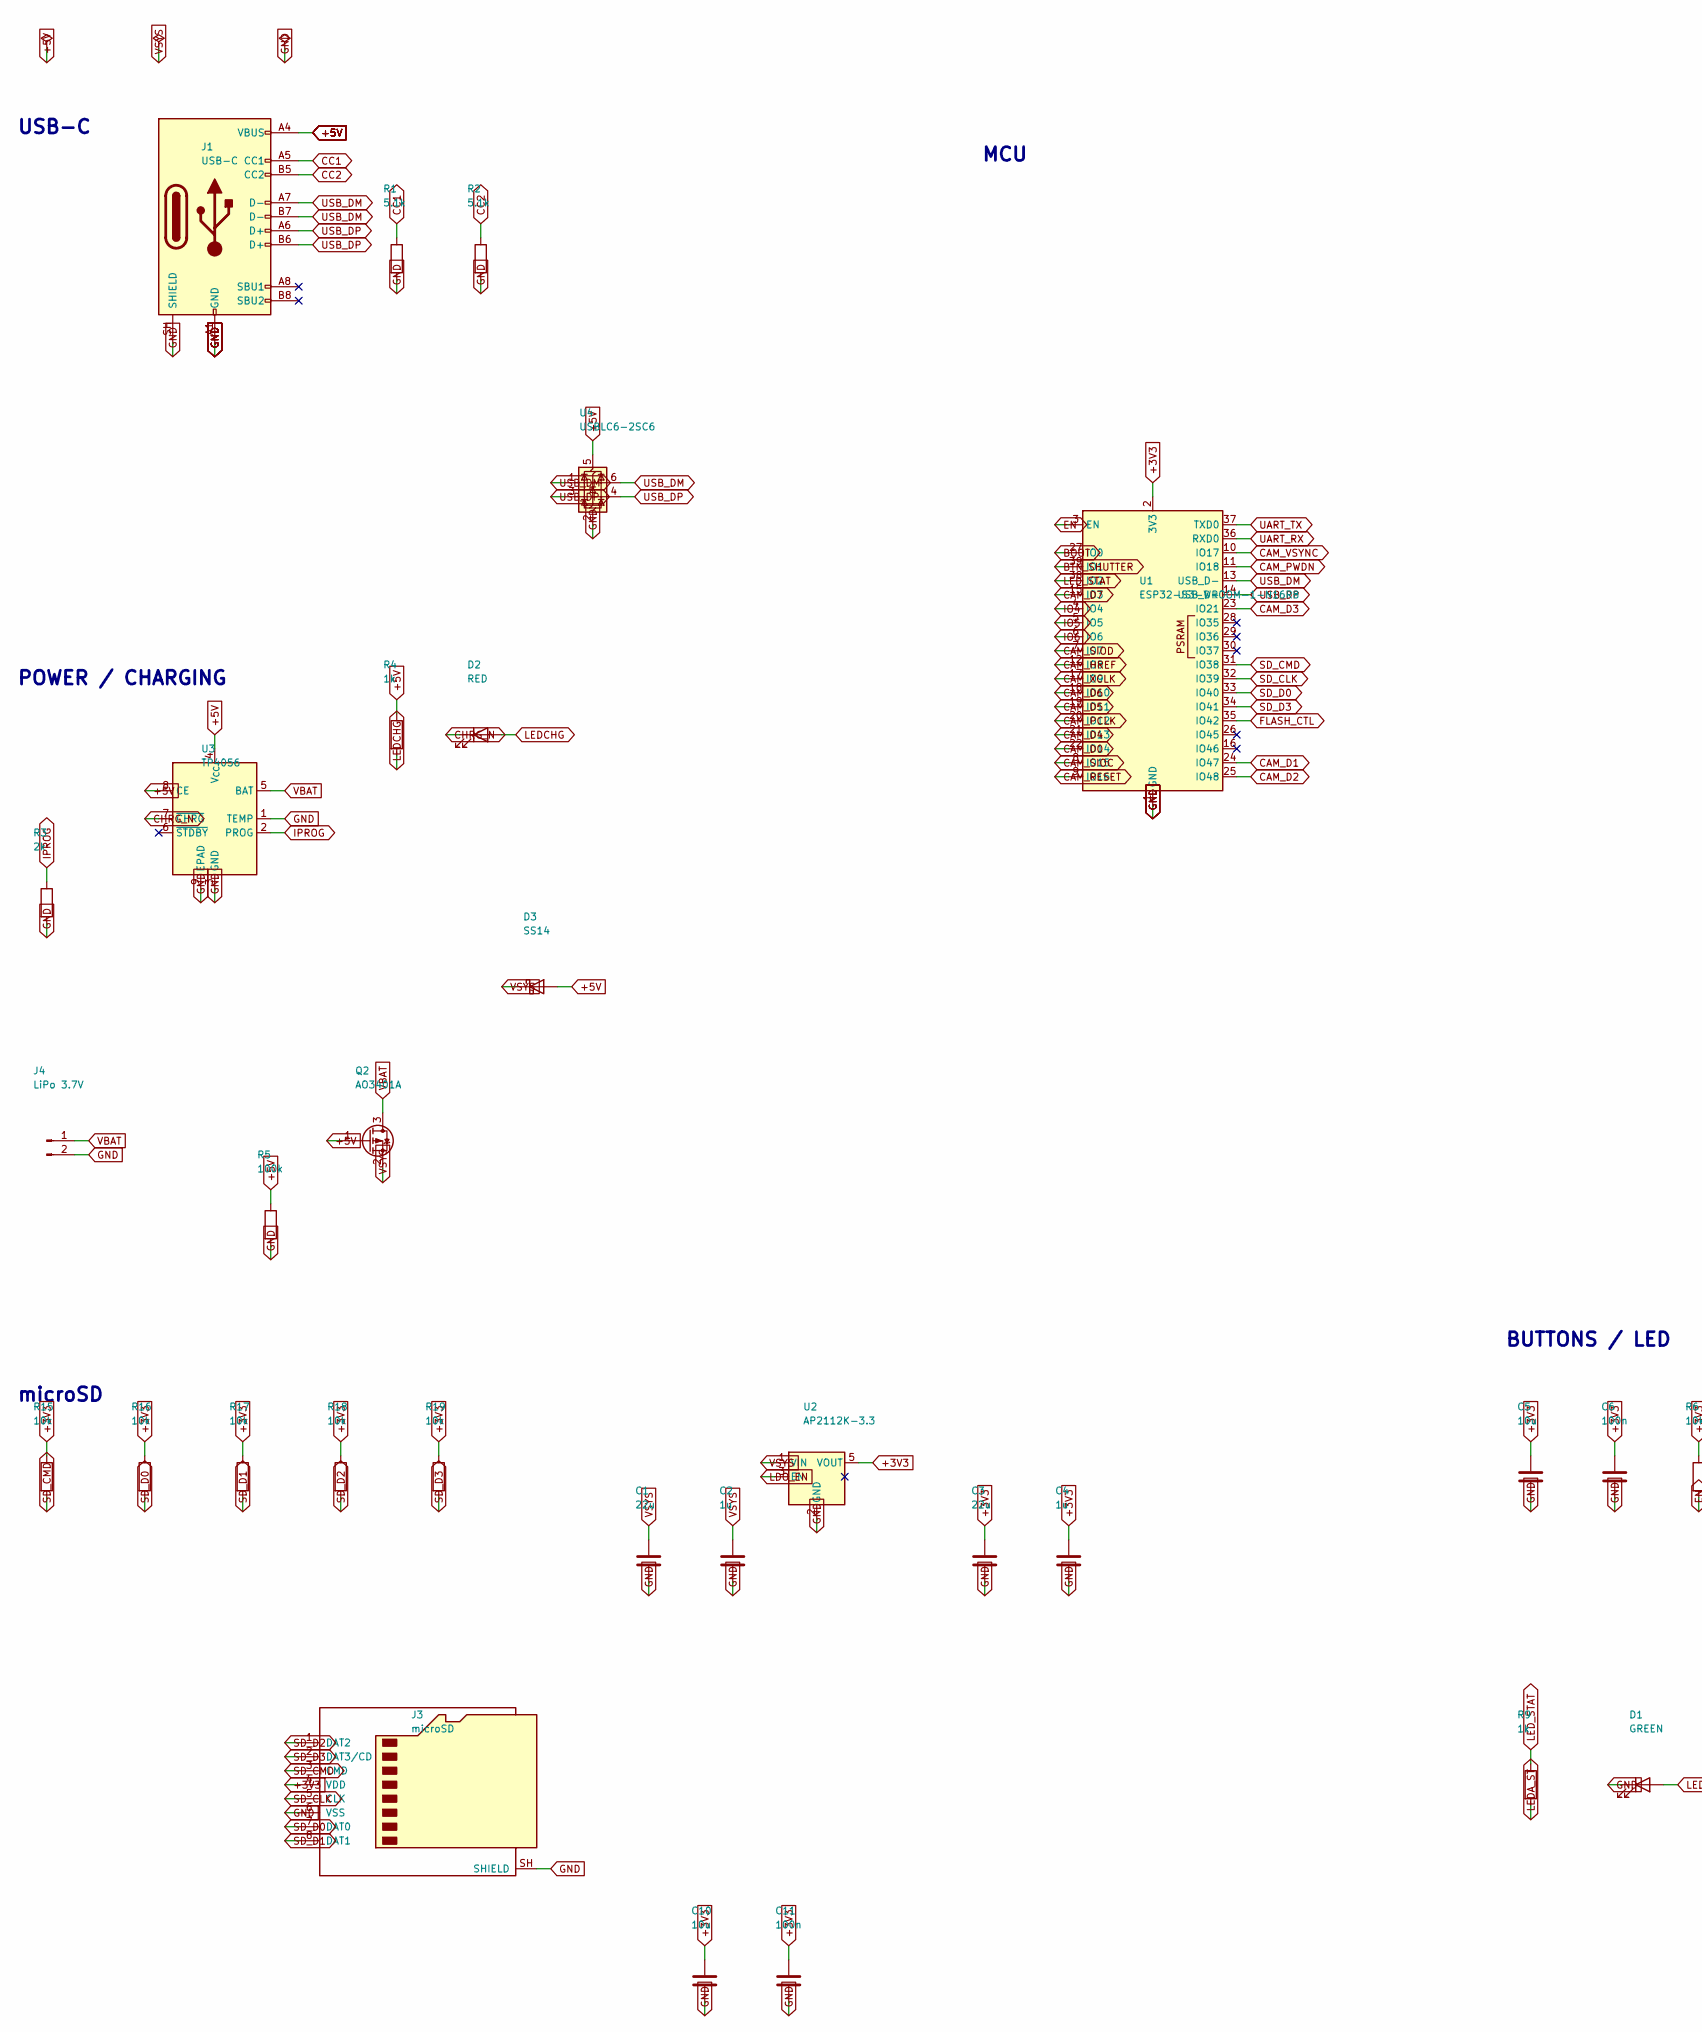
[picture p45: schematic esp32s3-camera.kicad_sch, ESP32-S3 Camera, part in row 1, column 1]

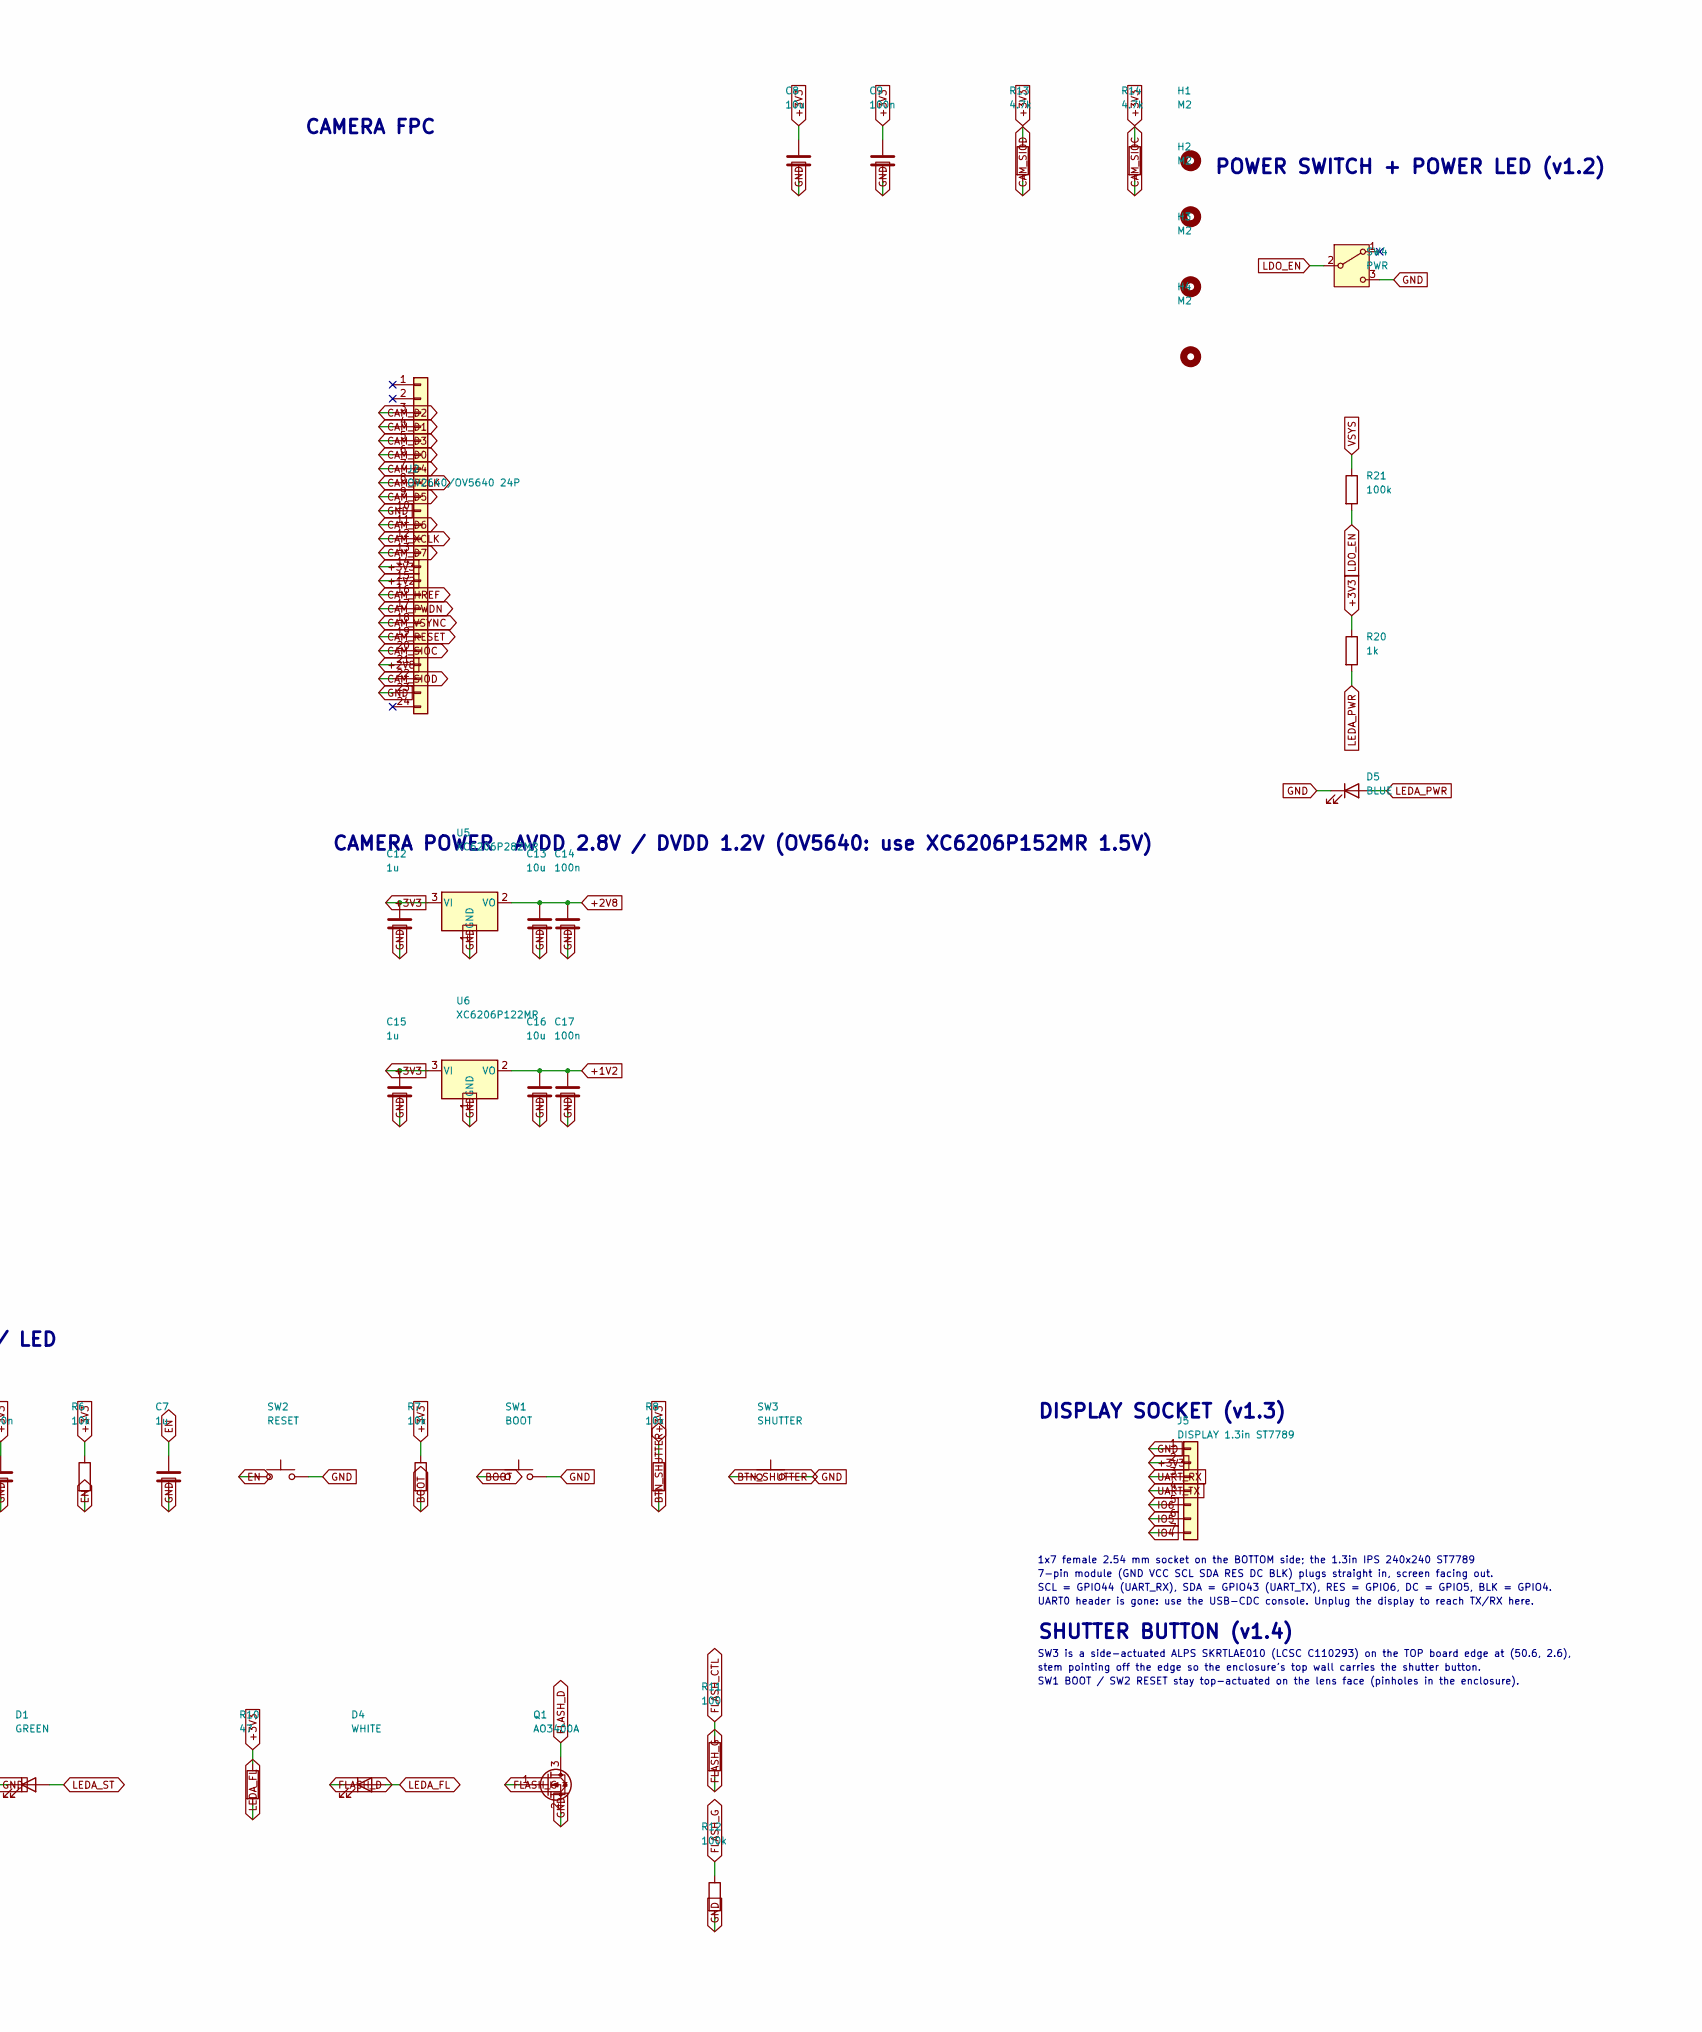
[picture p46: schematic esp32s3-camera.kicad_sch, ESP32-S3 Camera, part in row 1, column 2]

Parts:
C1, C3: 22u; C_0805_2012Metric; LCSC C45783
C2, C4, C7, C12, C15: 1u; C_0603_1608Metric; LCSC C15849
C5, C8, C10, C13, C16: 10u; C_0805_2012Metric; LCSC C15850
C6, C9, C11, C14, C17: 100n; C_0603_1608Metric; LCSC C14663
D1: GREEN; LED_0603_1608Metric; LCSC C72043
D2: RED; LED_0603_1608Metric; LCSC C2286
D3: SS14; D_SOD-123; LCSC C8598
D4: WHITE; LED_0603_1608Metric; LCSC C2290
D5: BLUE; LED_0603_1608Metric; LCSC C2288
H1, H2, H3, H4: M2; MountingHole_2.2mm_M2
J1: USB-C; USB_C_Receptacle_HCTL_HC-TYPE-C-16P-01A; LCSC C2894897
J2: OV2640/OV5640 24P; Hirose_FH12-24S-0.5SH_1x24-1MP_P0.50mm_Horizontal; LCSC C202112
J3: microSD; microSD_HC_Hirose_DM3AT-SF-PEJM5; LCSC C114218
J4: LiPo 3.7V; JST_PH_B2B-PH-K_1x02_P2.00mm_Vertical; LCSC C131337
J5: DISPLAY 1.3in ST7789; PinSocket_1x07_P2.54mm_Vertical; LCSC C225482
Q1: AO3400A; SOT-23; LCSC C20917
Q2: AO3401A; SOT-23; LCSC C15127
R1, R2: 5.1k; R_0603_1608Metric; LCSC C23186
R3: 2k; R_0603_1608Metric; LCSC C22975
R4, R9, R20: 1k; R_0603_1608Metric; LCSC C21190
R5, R12, R21: 100k; R_0603_1608Metric; LCSC C25803
R6, R7, R8, R15, R16, R17, R18, R19: 10k; R_0603_1608Metric; LCSC C25804
R10: 47; R_0603_1608Metric; LCSC C23182
R11: 100; R_0603_1608Metric; LCSC C22775
R13, R14: 4.7k; R_0603_1608Metric; LCSC C23162
SW1: BOOT; SW_SPST_SKQG_WithoutStem; LCSC C115351
SW2: RESET; SW_SPST_SKQG_WithoutStem; LCSC C115351
SW3: SHUTTER; SW_Push_SKRTLAE010_Side; LCSC C110293
SW4: PWR; SW_SPDT_Shouhan_MSK12C02; LCSC C431540
U1: ESP32-S3-WROOM-1-N16R8; ESP32-S3-WROOM-1-Cam; LCSC C2913202
U2: AP2112K-3.3; SOT-23-5; LCSC C51118
U3: TP4056; SOIC-8-1EP_3.9x4.9mm_P1.27mm_EP2.41x3.3mm; LCSC C16581
U4: USBLC6-2SC6; SOT-23-6; LCSC C7519
U5: XC6206P282MR; SOT-23-3; LCSC C14255
U6: XC6206P122MR; SOT-23-3; LCSC C424699

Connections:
+1V2: C16.1, C17.1, J2.15, U6.2 (VO)
+2V8: C13.1, C14.1, J2.21, U5.2 (VO)
+3V3: C3.1, C4.1, C5.1, C6.1, C8.1, C9.1, C10.1, C11.1, C12.1, C15.1, J2.14, J3.4 (VDD), J5.2, R6.1, R7.1, R8.1, R10.1, R13.1, R14.1, R15.1, R16.1, R17.1, R18.1, R19.1, R20.1, U1.2 (3V3), U2.5 (VOUT), U5.3 (VI), U6.3 (VI)
+5V: D3.2 (A), J1.A4 (VBUS), J1.A9 (VBUS), J1.B4 (VBUS), J1.B9 (VBUS), Q2.1 (G), R4.1, R5.1, U3.4 (V_{CC}), U3.8 (CE), U4.5 (VBUS)
BOOT: R7.2, SW1.1, U1.27 (IO0)
BTN_SHUTTER: R8.2, SW3.1, U1.39 (IO1)
CAM_D0: J2.6, U1.22 (IO14)
CAM_D1: J2.4, U1.24 (IO47)
CAM_D2: J2.3, U1.25 (IO48)
CAM_D3: J2.5, U1.23 (IO21)
CAM_D4: J2.7, U1.21 (IO13)
CAM_D5: J2.9, U1.19 (IO11)
CAM_D6: J2.11, U1.18 (IO10)
CAM_D7: J2.13, U1.15 (IO3)
CAM_HREF: J2.16, U1.12 (IO8)
CAM_PCLK: J2.8, U1.20 (IO12)
CAM_PWDN: J2.17, U1.11 (IO18)
CAM_RESET: J2.19, U1.9 (IO16)
CAM_SIOC: J2.20, R14.2, U1.8 (IO15)
CAM_SIOD: J2.22, R13.2, U1.7 (IO7)
CAM_VSYNC: J2.18, U1.10 (IO17)
CAM_XCLK: J2.12, U1.17 (IO9)
CC1: J1.A5 (CC1), R1.1
CC2: J1.B5 (CC2), R2.1
CHRG_N: D2.1 (K), U3.7 (~CHRG)
EN: C7.1, R6.2, SW2.1, U1.3 (EN)
FLASH_CTL: R11.1, U1.35 (IO42)
FLASH_D: D4.1 (K), Q1.3 (D)
FLASH_G: Q1.1 (G), R11.2, R12.1
GND: C1.2, C2.2, C3.2, C4.2, C5.2, C6.2, C7.2, C8.2, C9.2, C10.2, C11.2, C12.2, C13.2, C14.2, C15.2, C16.2, C17.2, D1.1 (K), D5.1 (K), J1.A1 (GND), J1.A12 (GND), J1.B1 (GND), J1.B12 (GND), J1.SH (SHIELD), J2.10, J2.23, J3.6 (VSS), J3.SH (SHIELD), J4.2, J5.1, Q1.2 (S), R1.2, R2.2, R3.2, R5.2, R12.2, SW1.2, SW2.2, SW3.2, SW4.3 (C), U1.1 (GND), U1.40 (GND), U1.41 (GND), U2.2 (GND), U3.1 (TEMP), U3.3 (GND), U3.9 (EPAD), U4.2 (GND), U5.1 (GND), U6.1 (GND)
IO4: J5.7, U1.4 (IO4)
IO5: J5.6, U1.5 (IO5)
IO6: J5.5, U1.6 (IO6)
IPROG: R3.1, U3.2 (PROG)
LDO_EN: R21.2, SW4.2 (B), U2.3 (EN)
LEDA_FL: D4.2 (A), R10.2
LEDA_PWR: D5.2 (A), R20.2
LEDA_ST: D1.2 (A), R9.2
LEDCHG: D2.2 (A), R4.2
LED_STAT: R9.1, U1.38 (IO2)
SD_CLK: J3.5 (CLK), U1.32 (IO39)
SD_CMD: J3.3 (CMD), R15.2, U1.31 (IO38)
SD_D0: J3.7 (DAT0), R16.2, U1.33 (IO40)
SD_D1: J3.8 (DAT1), R17.2
SD_D2: J3.1 (DAT2), R18.2
SD_D3: J3.2 (DAT3/CD), R19.2, U1.34 (IO41)
UART_RX: J5.3, U1.36 (RXD0)
UART_TX: J5.4, U1.37 (TXD0)
USB_DM: J1.A7 (D-), J1.B7 (D-), U1.13 (USB_D-), U4.1 (I/O1), U4.6 (I/O1)
USB_DP: J1.A6 (D+), J1.B6 (D+), U1.14 (USB_D+), U4.3 (I/O2), U4.4 (I/O2)
VBAT: J4.1, Q2.3 (D), U3.5 (BAT)
VSYS: C1.1, C2.1, D3.1 (K), Q2.2 (S), R21.1, U2.1 (VIN)

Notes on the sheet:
BUTTONS / LED
POWER / CHARGING
MCU
microSD
CAMERA FPC
USB-C
CAMERA POWER AVDD 2.8V / DVDD 1.2V (OV5640: use XC6206P152MR 1.5V)
POWER SWITCH + POWER LED (v1.2)
DISPLAY SOCKET (v1.3)
1x7 female 2.54 mm socket on the BOTTOM side; the 1.3in IPS 240x240 ST7789
7-pin module (GND VCC SCL SDA RES DC BLK) plugs straight in, screen facing out.
SCL = GPIO44 (UART_RX), SDA = GPIO43 (UART_TX), RES = GPIO6, DC = GPIO5, BLK = GPIO4.
UART0 header is gone: use the USB-CDC console. Unplug the display to reach TX/RX here.
SHUTTER BUTTON (v1.4)
SW3 is a side-actuated ALPS SKRTLAE010 (LCSC C110293) on the TOP board edge at (50.6, 2.6),
stem pointing off the edge so the enclosure's top wall carries the shutter button.
SW1 BOOT / SW2 RESET stay top-actuated on the lens face (pinholes in the enclosure).

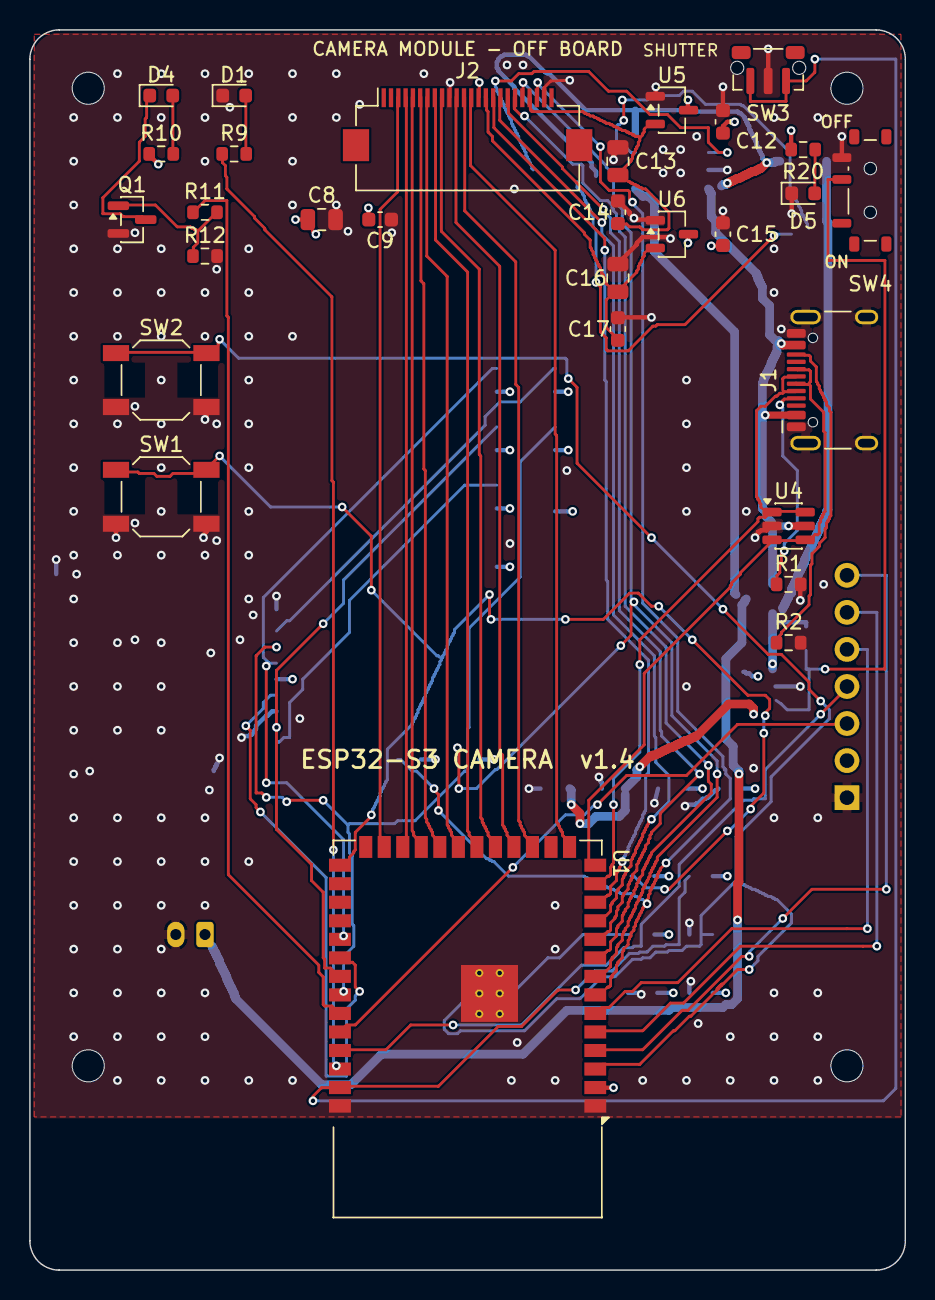
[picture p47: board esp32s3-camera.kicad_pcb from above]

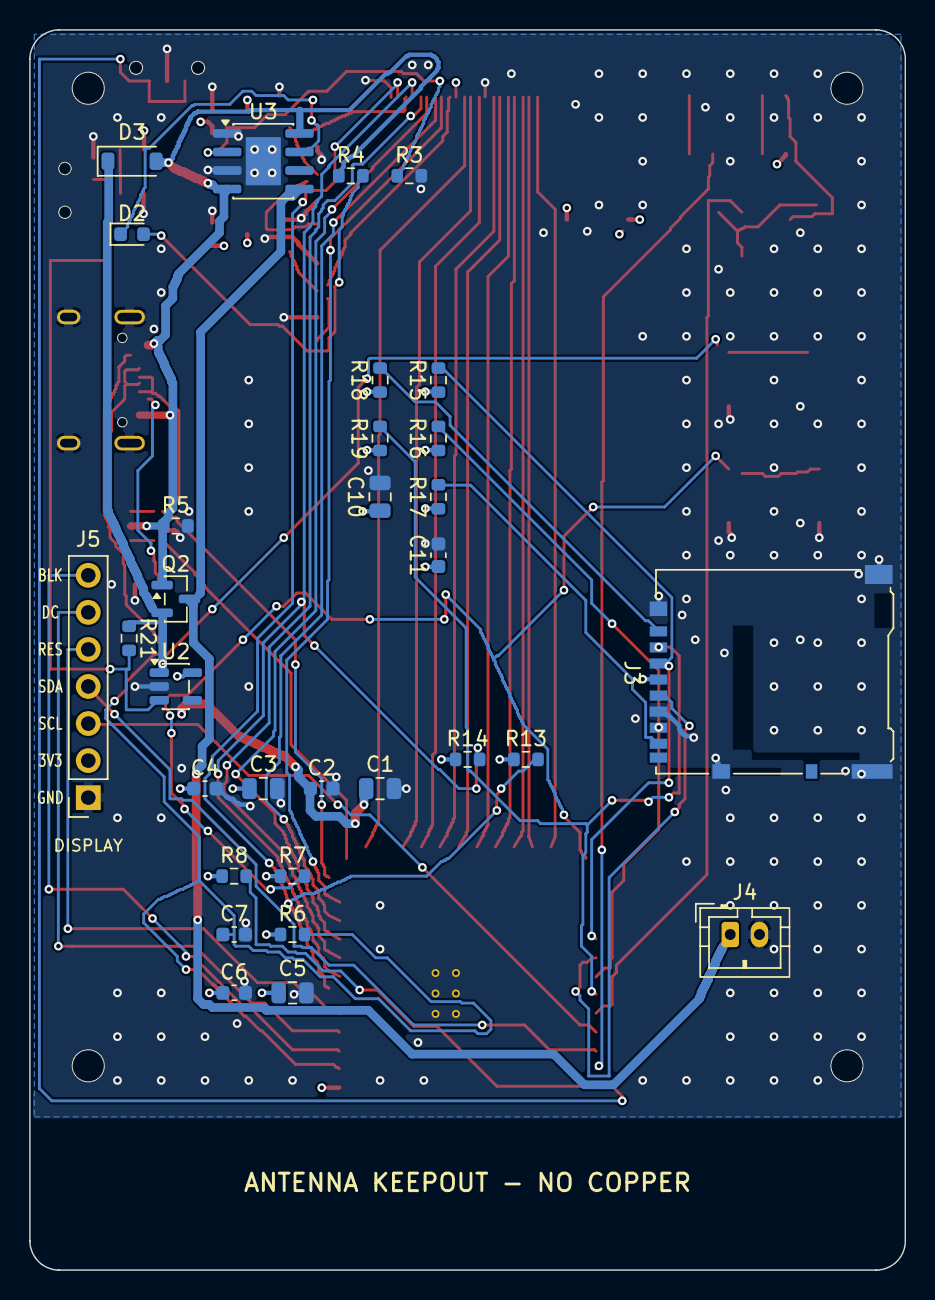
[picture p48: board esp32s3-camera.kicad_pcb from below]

Board: 4 copper layers, 60.0 x 85.0 mm, 64 parts (31 on the bottom side), 52 nets.

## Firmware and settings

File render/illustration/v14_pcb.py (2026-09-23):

"""v1.4 PCB edit with pcbnew: move the SHUTTER button SW3 from the lens face (top-actuated
SKQG at (9, 40)) to a side-actuated ALPS SKRTLAE010 on the top board edge at (50.6, 2.6),
actuator pointing -y through the enclosure's top wall. BOOT/RESET (SW1/SW2) stay.

Steps
 1. remove the old SW3 footprint and the F.Cu branch that fed it (BTN_SHUTTER), plus GND stubs
 2. clear the top-right corner: delete GND stitching vias (51,3) and (54,3); move C12 down 0.8 mm
 3. place the new SW3, pad 1 = BTN_SHUTTER, pad 2 = GND (+ GND via below it)
 4. route BTN_SHUTTER: pad -> via (53.8, 2.0) -> B.Cu along the right edge x = 59.35 -> channel
    y = 65.0 -> joins the existing B.Cu track of the net at (44.5, 62.7) (R8 pull-up side)
 5. silkscreen v1.4, title rev 1.4, zone refill
Run with KiCad's python. Board must not be open in KiCad."""
import os
import pcbnew
from pcbnew import VECTOR2I, FromMM

PROJ = os.environ.get("PROJ_DIR", r"C:\Users\aa095\Desktop\esp32s3-camera")
BOARD = os.path.join(PROJ, "esp32s3-camera.kicad_pcb")
FPLIB = r"C:\Program Files\KiCad\10.0\share\kicad\footprints"
NEW_FP = ("Button_Switch_SMD", "SW_Push_1P1T-MP_NO_Horizontal_Alps_SKRTLAE010")
LCSC = "C110293"
SW_X, SW_Y, SW_ROT = 50.6, 2.6, 180      # centre; stem tip lands at y = 0.56, body y 1.39..3.95
LANE_X, CHAN_Y, TOP_Y = 59.35, 65.0, 2.0

b = pcbnew.LoadBoard(BOARD)
assert b.GetTitleBlock().GetRevision() == "1.3", "expected v1.3 board"
mm = pcbnew.ToMM
def P(x, y): return VECTOR2I(FromMM(x), FromMM(y))
F, B = b.GetLayerID("F.Cu"), b.GetLayerID("B.Cu")
FSILK = b.GetLayerID("F.SilkS")
_keep = []          # python refs to removed items (see v13 note about dangling pointers)


def net(name):
    n = b.FindNet(name); assert n is not None, name; return n


def fp_by_ref(ref):
    for fp in b.GetFootprints():
        if fp.GetReference() == ref:
            return fp
    raise KeyError(ref)


def pad(fp, num):
    for p in fp.Pads():
        if p.GetNumber() == num:
            return p
    raise KeyError(num)


def track(x1, y1, x2, y2, layer, netname, w=0.2):
    t = pcbnew.PCB_TRACK(b)
    t.SetStart(P(x1, y1)); t.SetEnd(P(x2, y2)); t.SetLayer(layer); t.SetWidth(FromMM(w)); t.SetNet(net(netname))
    b.Add(t); return t


def via(x, y, netname):
    v = pcbnew.PCB_VIA(b)
    v.SetPosition(P(x, y)); v.SetDrill(FromMM(0.3))
    try:
        v.SetWidth(pcbnew.PADSTACK.ALL_LAYERS, FromMM(0.6))
    except Exception:
        v.SetWidth(FromMM(0.6))
    v.SetLayerPair(F, B); v.SetNet(net(netname)); b.Add(v); return v


def key(t):
    s, e = t.GetStart(), t.GetEnd()
    return ((round(mm(s.x), 1), round(mm(s.y), 1)), (round(mm(e.x), 1), round(mm(e.y), 1)))


def remove_tracks(netname, segs, expect):
    kill = []
    for t in list(b.GetTracks()):
        if t.GetClass() == "PCB_TRACK" and t.GetNetname() == netname:
            k = key(t)
            if k in segs or (k[1], k[0]) in segs:
                kill.append(t)
    for t in kill:
        b.Remove(t); _keep.append(t)
    assert len(kill) == expect, f"{netname}: removed {len(kill)}, expected {expect}"
    return len(kill)


def remove_vias(netname, points):
    kill = []
    for t in list(b.GetTracks()):
        if t.GetClass() == "PCB_VIA" and t.GetNetname() == netname:
            pos = (round(mm(t.GetPosition().x), 1), round(mm(t.GetPosition().y), 1))
            if pos in points:
                kill.append(t)
    for t in kill:
        b.Remove(t); _keep.append(t)
    assert len(kill) == len(points), f"{netname} vias: removed {len(kill)} of {points}"


def set_rot(fp, deg):
    try:
        fp.SetOrientation(pcbnew.EDA_ANGLE(deg, pcbnew.DEGREES_T))
    except Exception:
        fp.SetOrientationDegrees(deg)


# ------------------------------------------------------------------ 1. old SW3 and its feed
old = fp_by_ref("SW3")
sw3_path = old.GetPath()
gnd_pads = [(mm(p.GetPosition().x), mm(p.GetPosition().y)) for p in old.Pads() if p.GetNetname() == "GND"]
b.Remove(old); _keep.append(old)
print("old SW3 removed; path", sw3_path.AsString())
branch = {((21.2, 72.5), (20.7, 72.0)), ((20.7, 72.0), (20.2, 72.0)), ((20.2, 72.0), (19.9, 71.7)), ((19.9, 71.7), (19.9, 70.3)),
          ((19.9, 70.3), (13.0, 63.4)), ((13.0, 63.4), (13.0, 51.4)), ((13.0, 51.4), (12.4, 50.8)), ((12.4, 50.8), (12.4, 44.2)),
          ((12.4, 44.2), (10.9, 42.7)), ((10.9, 42.7), (10.9, 42.4)), ((10.9, 42.4), (9.9, 41.4)), ((9.9, 41.4), (9.9, 38.6)),
          ((9.9, 38.6), (10.4, 38.1)), ((10.4, 38.1), (12.1, 38.1)), ((9.9, 38.6), (9.4, 38.1)), ((9.4, 38.1), (5.9, 38.1))}
print("BTN_SHUTTER branch segments removed:", remove_tracks("BTN_SHUTTER", branch, 16))
# GND stubs that ended on the old SW3 GND pads
kill = []
for t in list(b.GetTracks()):
    if t.GetClass() == "PCB_TRACK" and t.GetNetname() == "GND":
        for (px, py) in gnd_pads:
            for pt in (t.GetStart(), t.GetEnd()):
                if abs(mm(pt.x) - px) < 1.0 and abs(mm(pt.y) - py) < 1.0:
                    kill.append(t); break
            else:
                continue
            break
for t in {id(t): t for t in kill}.values():
    print("  GND stub removed", key(t)); b.Remove(t); _keep.append(t)

# ------------------------------------------------------------------ 2. clear the corner, move C12
remove_vias("GND", {(51.0, 3.0), (54.0, 3.0)})
c12 = fp_by_ref("C12")
remove_tracks("GND", {((47.5, 4.7), (47.5, 3.9))}, 1)
remove_tracks("+3V3", {((47.5, 6.3), (48.3, 6.3))}, 1)
c12.SetPosition(P(47.5, 6.3))
p3, pg = pad(c12, "1"), pad(c12, "2")
assert p3.GetNetname() == "+3V3" and pg.GetNetname() == "GND"
print(f"C12 moved: +3V3 pad @ ({mm(p3.GetPosition().x):.2f},{mm(p3.GetPosition().y):.2f}) GND pad @ ({mm(pg.GetPosition().x):.2f},{mm(pg.GetPosition().y):.2f})")
gx, gy = mm(pg.GetPosition().x), mm(pg.GetPosition().y)
vx, vy = mm(p3.GetPosition().x), mm(p3.GetPosition().y)
track(gx, gy, gx, 3.9, F, "GND", 0.3)                       # to the existing GND via (47.5, 3.9)
track(vx, vy, vx, 6.6, F, "+3V3", 0.3); track(vx, 6.6, 47.8, 6.3, F, "+3V3", 0.3); track(47.8, 6.3, 48.3, 6.3, F, "+3V3", 0.3)
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

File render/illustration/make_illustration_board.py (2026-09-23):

"""Create render/illustration/esp32s3-camera-illustration.kicad_pcb: a copy of the
real board plus pad-less footprints carrying simple VRML models of the off-board
parts (camera module + ribbon, microSD card, LiPo battery). For rendering only;
the real board file is not touched. Model paths use ${KIPRJMOD}/models so the
folder is self-contained.
"""
import shutil
import uuid
from pathlib import Path

PROJ = Path(r"C:\Users\aa095\Desktop\esp32s3-camera")
SRC = PROJ / "esp32s3-camera.kicad_pcb"
OUT_DIR = PROJ / "render" / "illustration"
DST = OUT_DIR / "esp32s3-camera-illustration.kicad_pcb"
MODEL_SRC = OUT_DIR / "models"  # models live next to this script

# name, ref, x, y, rot, model file, offset xyz (mm)
ITEMS = [
    ("CameraModule", "ILL1", 30.0, 6.5, 0, "camera_module.wrl", (0, 0, 0)),
    ("MicroSDCard", "ILL2", 3.5, 44.0, 0, "microsd_card.wrl", (0, 0, -2.5)),
    # pouch top face 2.0 mm below the board underside (1.6 mm board + 2.0 mm foam pad)
    ("LiPoBattery", "ILL3", 34.0, 44.0, 180, "lipo_battery.wrl", (0, 0, -3.6)),
    # v1.3: 1.3" ST7789 7-pin module (27.78 x 39.22) plugged into the 1x7 female socket J5 at x = 56
    # (pins y 37.38..52.62). rot 90: local +Y (header edge) -> board +X, so the header row sits at
    # x = 58.5 - 2.5 = 56 and the body spans x 19.3..58.5, y 31.1..58.9. Module PCB face sits on top of
    # the socket (8.5) plus its own header plastic (2.54): z = -(1.6 + 8.5 + 2.54) = -12.64.
    ("DisplayModule", "ILL4", 38.89, 45.0, 90, "display_module.wrl", (0, 0, -12.64)),
]


def prop(name, value, layer):
    return f"""\t\t(property "{name}" "{value}"
\t\t\t(at 0 0 0)
\t\t\t(layer "{layer}")
\t\t\t(hide yes)
\t\t\t(uuid "{uuid.uuid4()}")
\t\t\t(effects
\t\t\t\t(font
\t\t\t\t\t(size 1 1)
\t\t\t\t\t(thickness 0.15)
\t\t\t\t)
\t\t\t)
\t\t)
"""


def footprint(name, ref, x, y, rot, model, off):
    return f"""\t(footprint "Illustration:{name}"
\t\t(layer "F.Cu")
\t\t(uuid "{uuid.uuid4()}")
\t\t(at {x} {y} {rot})
{prop("Reference", ref, "F.SilkS")}{prop("Value", name, "F.Fab")}{prop("Datasheet", "", "F.Fab")}{prop("Description", "illustration only, not a real part", "F.Fab")}\t\t(attr exclude_from_pos_files exclude_from_bom board_only)
\t\t(embedded_fonts no)
\t\t(model "${{KIPRJMOD}}/models/{model}"
\t\t\t(offset
\t\t\t\t(xyz {off[0]} {off[1]} {off[2]})
\t\t\t)
\t\t\t(scale
\t\t\t\t(xyz 1 1 1)
\t\t\t)
\t\t\t(rotate
\t\t\t\t(xyz 0 0 0)
\t\t\t)
\t\t)
\t)
"""


(OUT_DIR / "models").mkdir(parents=True, exist_ok=True)
for it in ITEMS:
    src, dst = MODEL_SRC / it[5], OUT_DIR / "models" / it[5]
    if src.resolve() != dst.resolve():
        shutil.copyfile(src, dst)
    assert dst.exists(), f"missing model {dst}"

text = SRC.read_text(encoding="utf-8")
assert text.rstrip().endswith(")")
body = text.rstrip()[:-1]
extra = "".join(footprint(*it) for it in ITEMS)
DST.write_text(body + extra + ")\n", encoding="utf-8", newline="\n")
(OUT_DIR / "README.txt").write_text(
    "僅供 3D 示意渲染用的板檔複本。多了 ILL1–ILL4 四個沒有焊盤的假零件，\n"
    "掛著 models/ 內簡化的相機模組、microSD 卡、鋰電池、1.3 吋螢幕模組 VRML 模型（v1.3 起螢幕插在 J5 母座上）。\n"
    "不要拿這個檔案出 Gerber；真正的板檔是上層的 esp32s3-camera.kicad_pcb。\n",
    encoding="utf-8",
)
print("wrote", DST)

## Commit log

2026-09-21 ESP32-S3 Camera v1.2: KiCad project, fab files, renders, docs and deck
    [esp32s3-camera-B_Cu.gbr, esp32s3-camera-B_Mask.gbr, esp32s3-camera-B_Paste.gbr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]
2026-09-21 Add layperson deck (簡易版) + PDF, rename full deck, update README
2026-09-21 README: add 簡報 section describing both decks
2026-09-21 Track .history, drc.out and terminal shortcut as requested
2026-09-21 Exclude .history again: it is KiCad's own embedded Git repo, cannot be nested
2026-09-23 Board v1.3: 1x7 display socket J5 replaces the J5/J6 pin headers
    For the 3D-printed camera enclosure the 1.3" ST7789 module now plugs
    straight into a CJT A2541WV-7P socket (LCSC C225482) on the bottom side
    at x = 56; pin order GND VCC SCL SDA RES DC BLK, SCL = GPIO44, SDA = GPIO43.
    v1.2 was never ordered. Snapshot in versions/v1.3 (Gerber, BOM, CPL,
    ERC/DRC 0/0/0 with schematic parity), edit scripts in render/illustration,
    and the v1.2 JLCPCB upload folder moved into its own snapshot.
    [esp32s3-camera-B_Cu.gbr, esp32s3-camera-B_Mask.gbr, esp32s3-camera-B_Paste.gbr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]
2026-09-23 Board v1.4: side-actuated shutter on the top edge
    SW3 SHUTTER moves from the lens face (top-actuated SKQG at 9,40) to an
    ALPS SKRTLAE010 side switch at (50.6, 2.6) with the stem pointing off the
    top edge, so the enclosure's top wall can carry the shutter button under
    the right index finger. Project footprint copy with 0.55 mm pads for hole
    clearance, SolidWorks-made simplified STEP model (KiCad's library has
    none), C12 moved 0.8 mm, BTN_SHUTTER rerouted under the module (B.Cu
    y 73.4) and up the right edge (x 59.35). ERC 0, DRC with parity 0/0/0,
    GND/3V3 connectivity 0 isolated pads; CPL differs from v1.3 only in C12
    and SW3. Fab outputs, versions/v1.4 snapshot, renders and docs updated.
    Co-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
    [SW_Push_SKRTLAE010_Side.SLDPRT, SW_Push_SKRTLAE010_Side.step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]
2026-09-23 Enclosure: SolidWorks camera case for board v1.4 and the v1.4 web page
    Two-shell 3D-printed case built by enclosure/build_enclosure_sw.py through
    the SolidWorks 2024 COM API from the board coordinates: lens-side front
    shell (Ø10 lens hole with Ø16 bezel ring, top-wall shutter cap, BOOT/RESET
    pinholes, LED light holes, USB-C window, power-switch slot, grip grooves),
    screen-side back shell (24.5 mm window in a recessed frame, microSD slot,
    four M2 standoffs, four locating posts with pegs into the display module's
    corner holes), R2.5 edge round-over, R4.5 corners, M2x25 screws from the
    back. Assembly includes the board STEP; interference check 0. SLDPRT,
    SLDASM, STL, renders, README with the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
    [esp32s3-camera-board.SLDPRT, esp32s3-camera-enclosure.SLDASM, esp32s3-camera-shell-back.SLDPRT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]
2026-09-23 Decks: v1.4 full and simplified pptx/pdf replace the v1.2 ones, generators in tools/
    The v1.2 decks are removed; the v1.4 pair (20-page full version and the
    simplified one) is generated by tools/update_decks_v14.py from the v1.2
    files, with fit-check slides added by tools/add_fit_slides.py and exported
    to PDF by tools/export_decks.py. These decks still describe the display as
    plugged straight into J5; the Dupont-jumper change of 2026-09-23 is not in
    them yet.
    [add_fit_slides.py, export_decks.py, update_decks_v14.py]
2026-09-23 Enclosure: display on seven male-female Dupont jumpers, back shell 27 mm deep
    The user decided to connect the 1.3" ST7789 module to J5 with off-the-shelf
    male-female Dupont jumpers instead of plugging it in (no soldering). The
    14 mm male housings standing in the 8.5 mm socket set the depth: back-shell
    cavity 14.5 -> 27.0 mm below the board, device 28.6 -> 40.1 mm thick, case
    screws M2x25 -> M2x35. The module moves to x 10.4-49.6 (centred on x = 30,
    header row on the left at x 12.9, away from J5) and is screwed with M2x4 to
    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
    [esp32s3-camera-board.SLDPRT, esp32s3-camera-enclosure.SLDASM, esp32s3-camera-shell-back.SLDPRT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]
2026-09-23 Decks: Dupont-jumper display in both v1.4 decks, new wiring slide
    tools/update_decks_dupont.py edits the two v1.4 decks in place: display now
    connected to J5 with seven male-female Dupont jumpers, module screwed to
    four posts, back shell 27 mm deep, device 40.1 mm, screws M2x35 + M2x4,
    window centre (28.4, 45); height table and shopping tables updated; the
    re-rendered enclosure and fit-check pictures swapped in; a new slide 17
    in the full deck shows the wire path and why the case got thicker. PDFs
    re-exported with PowerPoint. Captions on the KiCad renders that still show
    the plug-in variant say so.
    [update_decks_dupont.py]
2026-10-10 Enclosure: re-export the three STLs with full geometry, add export_stl.py
    SolidWorks writes the STL of the active document only, so the STLs saved by
    build_enclosure_sw.py held 10-48 triangles (plain boxes). The script now
    activates the part and clears the selection before SaveAs3; export_stl.py
    re-exports and checks triangle count and bounding box. Front shell 13,580
    triangles, back shell 17,180, shutter cap 28; sizes 65 x 90 mm as designed.
2026-10-10 Firmware: Arduino sketch for board v1.4 (preview, shutter to microSD, flash)
    OV2640 RGB565 240x240 preview on the ST7789 over SPI on GPIO44/43, side
    shutter takes a UXGA JPEG to /DCIM on the microSD (SDMMC 1-bit), BOOT toggles
    the flash LED. Pin map in board_pins.h from DESIGN.md section 4. Compiles
    with esp32 core 3.3.10 (ESP32S3 Dev Module, OPI PSRAM, 16MB, USB CDC);
    untested on hardware, the board has not been ordered.
